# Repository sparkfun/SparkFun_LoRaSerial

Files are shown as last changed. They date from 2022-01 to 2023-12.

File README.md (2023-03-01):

SparkFun LoRaSerial
========================================

SparkFun LoRaSerial (https://www.sparkfun.com/products/19311)

[*SparkFun LoRaSerial Kit - 915MHz (WRL-19311)*](https://www.sparkfun.com/products/19311)

Head to the [LoRaSerial Product Manual](http://docs.sparkfun.com/SparkFun_LoRaSerial/) for technical documentation.

LoRaSerial is a pair of serial radio modems that simply passes serial back and forth. Do you have a system that needs to report data every few seconds? Is it located beyond WiFi or Bluetooth range? Do you need 9 mile/15 kilometer range? LoRaSerial transmits data over LoRa giving it incredible range compared to other methods. We’ve regularly transmitted over 9 miles/15km line-of-sight using two LoRaSerial radios, right out of the box.

LoRaSerial utilizes a 1 watt 915MHz transceiver and an open source protocol to and transmit AES encrypted data at 4800bps or approximately 480 bytes per second. Video streaming, this is not. LoRaSerial is very good at getting whatever data you need from point A to point B, encrypted, without configuration. The radios automatically frequency hop (FHSS) between channels to avoid collisions. The ‘airspeed’ or data rate is configurable up to approximately 2,000 bytes per second for shorter range, or for *extremely* long range transmissions, as low as 400 bytes per second.

LoRaSerial radios support simple point to point and point as well as multipoint broadcasts. Multipoint broadcasting makes it ideal for GNSS RTK and many other scenarios where one device needs to produce data and many devices need to consume that data.

The LoRaSerial firmware supports an innovative and simple to use ‘training’ method. Pressing the train button on both radios will generate a new random network ID and AES encryption key and share them between radios. This makes pairing radios in the field as simple as a button press. WiFi WPS this is not. Bring the radios near each other and the LoRaSerial training method is simple and secure.

Currently, SparkFun is offering radios utilizing 915MHz modems that are allowed in most parts of the world. Please check your local restrictions. The radios are fully configurable to restrict frequencies, channels, dwell time, power output, and a variety of other settings to make the radios compatible with your local regulations.

Repository Contents
-------------------

* **/Binaries** - Compiled firmware, ready to load
* **/Documents** - Datasheets and additional product information
* **/Firmware** - Main Arduino firmware
* **/Hardware** - Eagle PCB files

Documentation
--------------

* **[LoRaSerial Product Manual](http://docs.sparkfun.com/SparkFun_LoRaSerial/)** - Configuration guide for the SparkFun LoRaSerial.

License Information
-------------------

This product is _**open source**_! 

Please review the LICENSE.md file for license information. 

If you have any questions or concerns on licensing, please contact technical support on our [SparkFun forums](https://forum.sparkfun.com/viewforum.php?f=152).

Distributed as-is; no warranty is given.

- Your friends at SparkFun.

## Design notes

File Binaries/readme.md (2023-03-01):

Programming SAMD21 in Circuit
===========================================================

LoRaSerial uses a SAMD21. This folder contains the various production and release binaries for the device. Please see [Updating LoRaSerial Firmware](https://docs.sparkfun.com/SparkFun_LoRaSerial/firmware_update/) for instructions on how to update the firmware on the device.

This folder also contains binaries combined with a UF2 bootloader. These binaries are loaded during production to allow both the bootloader and firmware to be loaded in one step. These files, along with atprogram.exe are used with a J-Link programmer to load the combined binary onto a target device.

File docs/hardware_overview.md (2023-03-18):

# Hardware Overview

The LoRaSerial is a SAMD21 based assembly with an SX1276 LoRa radio with innovative firmware to make things as simple as possible.

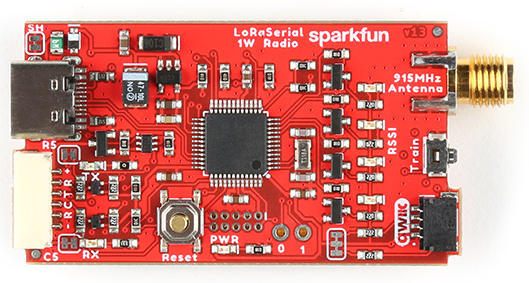
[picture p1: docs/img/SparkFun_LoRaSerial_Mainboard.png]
SAMD21 based serial radio


*SAMD21 based serial radio*

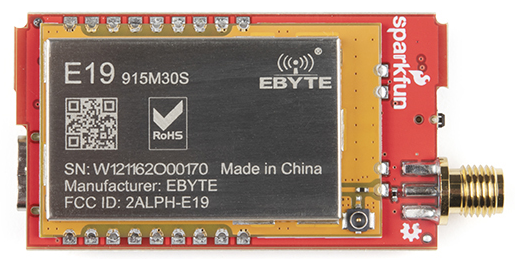
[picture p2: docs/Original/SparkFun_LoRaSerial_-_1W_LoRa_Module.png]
LoRa module


*1-watt module containing the SX1276 and a power amplifier*

The LoRaSerial uses a 1W LoRa radio based on the SX1276 radio along with a SAMD21 utilizing the UF2 bootloader. Any serial received at USB or serial port will be queued up, encrypted, and sent out over the radio. Any received packets are checked for CRC and Network ID, decrypted, then printed on both USB and serial interfaces.

Note: By default, there is a 50ms timeout in which the radio will wait for additional characters to be received until a partial frame is sent.

### USB C

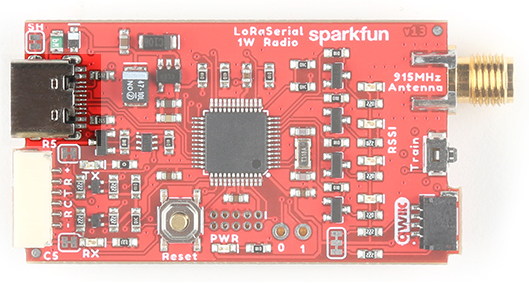
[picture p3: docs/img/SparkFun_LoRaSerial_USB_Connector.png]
USB C connector for power and serial


*USB C connector for power and serial*

The USB C connector provides power and serial communication to the unit. LoRaSerial will automatically show up on a computer or SBC (single board computer) as a serial COM port at a default of 57600bps. Currently, only 8-N-1 serial communication is supported but we are open to additional features as users' needs arise.

### 6-Pin JST

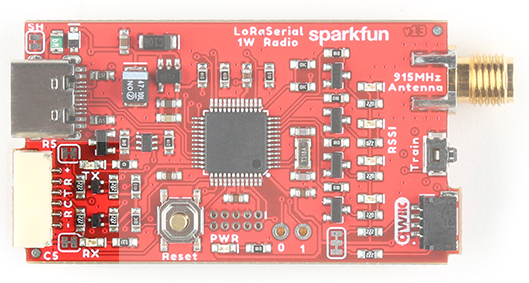
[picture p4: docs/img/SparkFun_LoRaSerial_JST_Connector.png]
6-pin locking JST connector for power and serial


*6-pin locking JST connector for power and  serial*

LoRaSerial features a ‘locking’ type 6-pin JST connector. The connector on LoRaSerial is X and mates with a connector JST-GHR-06V. Each LoRaSerial radio comes with a cable to connect from the JST connector to breadboard-friendly pins. If you need additional cables they are available [here](https://www.sparkfun.com/products/18079) (Note: the wire color may be different between cables). 

The pinout is as follows:

* **PWR** - 3.3-5V
* **RX** - Receive (Input into LoRaSerial)
* **TX** - Transmit (Output from LoRaSerial)
* **CTS** - Clear To Send (Input into LoRaSerial)
* **RTS** - Ready To Send (Output from LoRaSerial)
* **GND** - Ground

**PWR** (3.3-5V) - LoRaSerial requires 3.3 to 5V to operate. We recommend 5V for maximum transmission range but we’ve found operating off of a LiPo at 3.7 to 4.2V works great.

**RX** (Receive) - Connect this pin to the TX pin of your system. This pin is 3.3-5V tolerant and has an internal pull-up.

**TX** (Transmit) - Connect this pin to the RX pin of your system. This pin uses 3.3V logic.

**CTS** (Clear To Send) - (Optional) Connect this pin to a GPIO of your system. This pin is 3.3-5V tolerant and has an internal pull-up. When this pin is low LoRaSerial will continue to send data. If the host system pulls this pin high, the radio will stop sending data.

**RTS** (Ready To Send) - (Optional) Connect this pin to a GPIO of your system. This pin uses 3.3V logic. If the radio’s buffer (size currently is 4096 bytes) becomes full the system will drive RTS high indicating that it should not be passed more data. If more serial data is received, the buffer will be overwritten, oldest data first.

**GND** (Ground) - Connect this pin to the ground of your system.

#### Flow Control

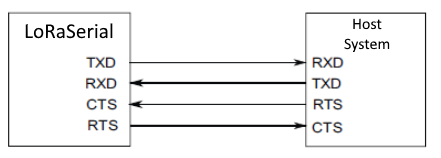
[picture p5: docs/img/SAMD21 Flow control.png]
Flow control on the SAMD21


If flow control is enabled, LoRaSerial will send data when its CTS pin is driven low (the host system is telling the radio to transmit). If flow control is enabled, LoRaSerial will drive its RTS low if its serial buffer is full (the radio is telling the host system to hold its horses). CTS and RTS pins are only exposed on the UART connector but if flow control is enabled, the UART flow control pins will apply to both USB and serial data streams. Internal pull-ups are used so if flow control is enabled, RTS and CTS must not be left floating. By default, flow control is turned off.

Hardware flow control applies to both the UART connection and the USB connector but in slightly different ways. 

The USB connection uses a concept called backpressure. It is not affected by the [FlowControl setting](http://docs.sparkfun.com/SparkFun_LoRaSerial/at_commands/#serial-commands) and cannot be disabled. If LoRaSerial is not able to read the incoming data fast enough, the USB driver will indicate to the host’s operating system that the data has not been consumed. Depending on the application, data will either be paused or lost. 

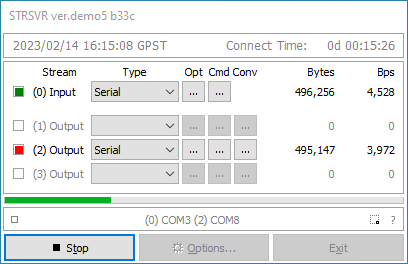
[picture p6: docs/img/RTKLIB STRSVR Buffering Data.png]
STRSVR Buffering Serial Data


This is most obvious in applications such as STRSVR (from [RTKLIB](https://rtklib.com/)). If STRSVR sends more data to the LoRaSerial than it can consume, STRSVR will begin to buffer the data until it can be sent. This is problematic for time-sensitive data, such as RTCM, where data, being delivered successfully but delayed but multiple seconds, can cause problems with RTK. If RTCM data is multiple seconds old, an RTK Fix will go to RTK Float, then fail because current RTCM data is not being delivered to the far end of the radio link. The easiest way to fix the problem is to increase the AirSpeed of the link.

### RSSI LEDs

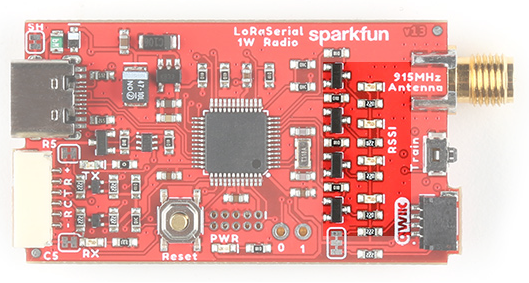
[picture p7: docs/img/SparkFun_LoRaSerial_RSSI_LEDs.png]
4 LEDs indicating signal strength


*4 LEDs indicating signal strength*

Four LEDs indicate in real-time the received signal strength or RSSI. These LEDs are meant to show a qualitative level of receive strength. Don’t worry if you’ve got three LEDs rather than four. LoRa technology is capable of transmitting a long range in harsh RF conditions. As long as you’ve got one LED, you will be able to send and receive data.

### RPSMA Connector

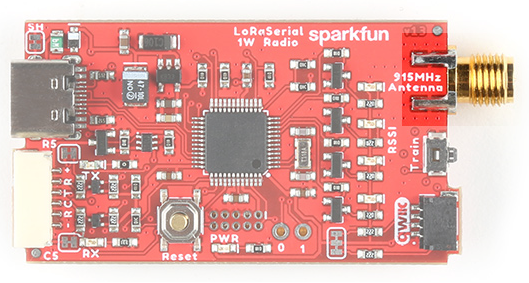
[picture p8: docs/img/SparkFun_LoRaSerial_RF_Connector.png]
Reverse polarized SMA antenna connector


*Reverse polarized SMA antenna connector*

Attach a 915MHz RPSMA antenna to this port. Not sure which is SMA and which is RPSMA? Check out this [RF Connector Guide](https://www.sparkfun.com/pages/RF_Conn_Guide). The LoRaSerial is also compatible with any large 915MHz antennas including [fiberglass antennas](https://www.sparkfun.com/products/15597). We recommend a good thick RG58 RPSMA extension from the radio to your antenna to minimize loss. Remember, we are transmitting at 1W so keep your cables and connectors to a minimum.

Note: Be careful of antennas that have a gain higher than 6 dBi as this may violate the [maximum effective isotropic radiated power](https://afar.net/tutorials/fcc-rules/) (EIRP) for your area/country.

### Qwiic Connector

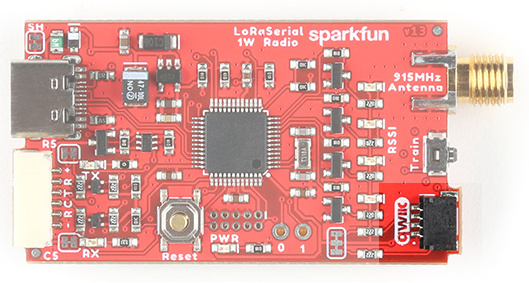
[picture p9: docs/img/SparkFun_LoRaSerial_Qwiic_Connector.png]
Qwiic connector for I2C communication


*Qwiic connector for I2C communication*

The Qwiic connector and I2C accessibility are not yet implemented.

### Train Button

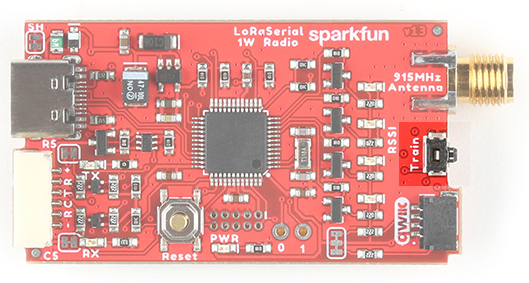
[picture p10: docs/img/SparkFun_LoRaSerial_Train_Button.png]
Button to enter train mode


*Button to enter train mode*

LoRa Serial uses a unique and very easy-to-use train feature. Each radio has a default Network ID and AES key programmed into it. Changing these keys is as easy as pressing a button! 

Using a ballpoint pen or other small pointed device, press and hold the Train button for 2 seconds, until you see the RSSI LEDs begin to blink. You can release the button. If the LEDs begin to cylon (bounce back and forth) the device has entered training ‘wait’ mode where it waits for another device to ping it.

On the second radio, press and hold the Train button for 2 seconds, until you see the RSSI LEDs begin to blink. Release the button. The RSSI LEDs on both units will blink in unison indicating that the units are now trained to each other.

For security reasons, the radios are both set to the lowest transmission power to minimize any eavesdropper from monitoring the transaction. While the ‘new’ keys are themselves encrypted, they are encrypted using a published AES key so one could theoretically back out the new AES keys if they are within ~30ft of the devices when the radios are being trained. If you’re paranoid, train the radios with the antennas off, within a few inches of each other. If total security is a concern, or if the radios cannot be physically brought near one another, the AES keys and/or the network IDs can be set via software commands.

### Internal Reset Button

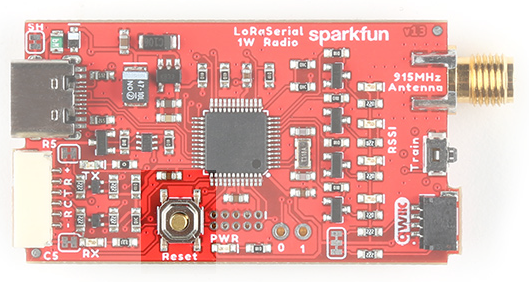
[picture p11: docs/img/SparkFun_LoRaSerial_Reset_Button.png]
SAMD21 reset button


*SAMD21 reset button*

The firmware on the LoRaSerial can be upgraded from a computer without ever having to open the unit. In the rare case that the SAMD21 needs to be forced into bootloader mode the reset button should be quickly double-tapped. The unit will then enter bootloader mode and wait for new firmware or for a reset event (button is pressed or power is cycled).

Please see [Updating LoRaSerial Firmware](http://docs.sparkfun.com/SparkFun_LoRaSerial/firmware_update/) for more information.

### GPIO

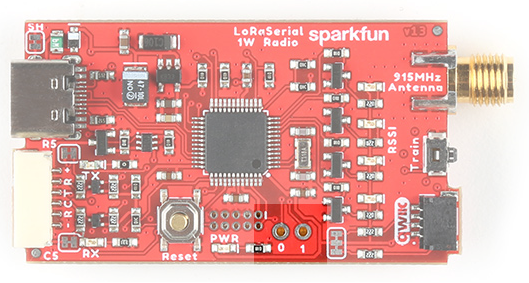
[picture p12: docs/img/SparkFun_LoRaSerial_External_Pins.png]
GPIOs on SAMD21


*GPIOs on SAMD21*

Two GPIOs capable of ADC are broken out for potential future use.

### U.FL Connector

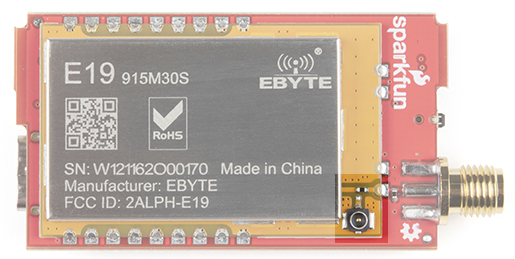
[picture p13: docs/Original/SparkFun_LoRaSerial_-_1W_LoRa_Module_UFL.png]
Zero ohm jumper resistor and U.FL connector


*Zero ohm jumper resistor and U.FL connector*

For advanced users, the 915/868MHz modules feature a U.FL connector. This can be helpful if you need to embed the radio in an enclosure and need an external bulkhead RP-SMA connector. To use the U.FL connection, desolder the 0402 0Ω jumper and move it to the U.FL's RF path.

### Power Selection

LoRaSerial uses an onboard 'ideal' MOSFET to select the high voltage source between the USB connector and the VCC/GND of the UART connector. This allows dual power supplies to be applied without fear of back-feeding a higher voltage onto a lower voltage system.

## Enclosure

The enclosure is industrial 3D SLA printed with an effective IPX rating of IP52 (dust and waterdrop protected).

The enclosure is secured with two screws on either side of the unit. The top cover can be removed to expose the inner assembly.

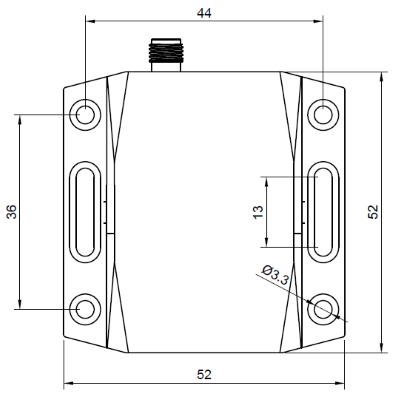
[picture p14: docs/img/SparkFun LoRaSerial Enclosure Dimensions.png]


*[LoRaSerial Dimensional Drawing](img/SparkFun_LoRaSerial_Enclosure_Dimensions.pdf)*

The enclosure includes mounting holes for wall or rack mounting.

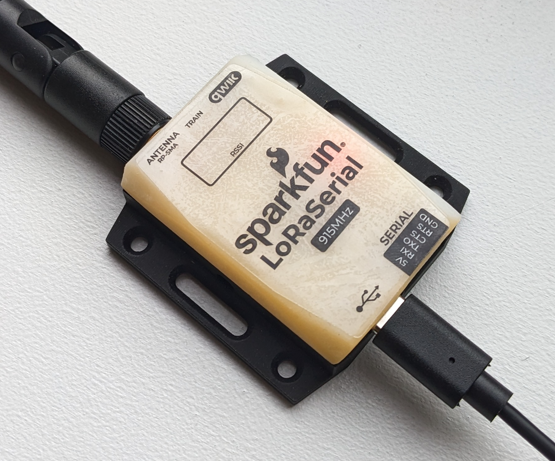
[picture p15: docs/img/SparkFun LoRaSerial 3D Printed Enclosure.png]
LoRaSerial Enclosure UV Exposed


**Note:** Leaving a LoRaSerial unit exposed to daylight outdoors or near a window will cause the cover to darken over a period of months. This will not affect the performance of the radio or the enclosure.

## Power Usage

The SX1276-based radio module is rated for 1 watt. The radio can be adjusted from 14dBm up to 30dBm (default). 

**Note:** The **AT-TxPower** command ranges from 14 to 30 in dBm. The radio uses an internal lookup table to map the correct power output (30dBm by default) to the associated power level for the power amplifier (20 in this case).

The average standby current is approximately **60mA** when TxPower of 30 is selected. The average current varies based on the selected output power because the units will periodically transmit *Find Partner* packets when the link is down and *Heartbeat* packets when the link is up, even if there is no data waiting to be transmitted. 

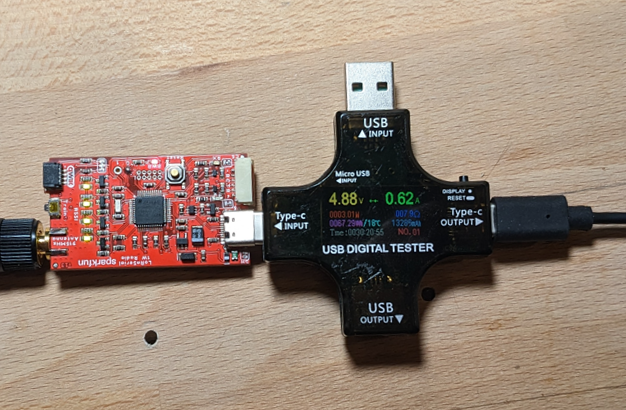
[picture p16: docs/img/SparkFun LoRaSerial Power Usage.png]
A 1W radio using 2.5W


During broadcast, the radio can use much more than 1W. Use a good 5V supply capable of outputting at least 1A at 5V. A USB 3.0 port is good. A USB 2.0 port will considerably limit the capabilities of the radio.

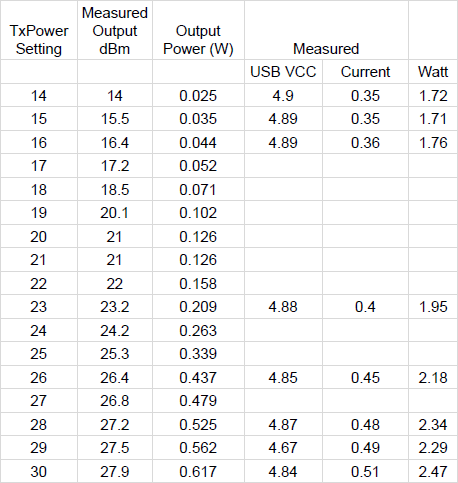
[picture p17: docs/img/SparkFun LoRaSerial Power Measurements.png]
Power output vs Power input


The above table shows power usage during 100% broadcast envelope usage. The actual current usage will be proportionally lower depending on the amount of data transmitted. For example, if only half of the airspeed is used (240 bytes out of a max of 480 at airspeed 4800) then the transmitter will only be on for 50% of the time at the stated power.

The power meter and hardware setup limited the ability to get to the full 30dBm output. The above measurements should be used as a rule-of-thumb for power considerations.

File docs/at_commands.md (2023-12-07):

# AT Commands

LoRaSerial radios are very flexible. By default, the radio is looking for serial communication at 57600bps. Open the terminal of your choice and enter +++ and wait for an OK. The radio is now ready for an AT command.

A PDF of *all* AT commands is available [here](img/LoRaSerial%20AT%20Commands%20v2.0.pdf).

Below is a brief list of commands:

| AT Command | Command Description |
|---|---|
|+++ | Enter command mode |
|AT | Reports OK |
|AT? | Display help text |
|ATB | Break the link |
|ATD | Display the debug settings |
|ATF | Restore factory settings |
|ATG | Generate new netID and encryption key |
|ATI | Display the radio version |
|ATI? | Display the information commands |
|ATIn | Display system information |
|ATO | Exit command mode |
|ATP | Display probe trigger settings |
|ATR | Display radio settings |
|ATS | Display the serial settings |
|ATT | Enter training mode |
|ATW | Save current settings to NVM |
|ATZ | Reboot the radio |
|AT-Param=xxx| Set parameter's value to xxx by name (Param)|
|AT-Param? | Print parameter's current value by name (Param)|
|AT-? | Display the setting values |

*Table of AT Commands*

The commands are best discussed in groups:

* [Radio Commands](http://docs.sparkfun.com/SparkFun_LoRaSerial/at_commands/#radio-commands)
* [Serial Commands](http://docs.sparkfun.com/SparkFun_LoRaSerial/at_commands/#serial-commands)
* [Info Commands](http://docs.sparkfun.com/SparkFun_LoRaSerial/at_commands/#info-commands)
* Debug Commands

A parameter is set using the **AT-** prefix, followed by the name of the command with an equals sign and the value to set. For example, sending **AT-Echo=1**** will enable serial echo. This setting can be stored in NVM (non-volatile memory) by sending the **ATW** command. To query a setting, send the AT command without a value and the device will respond with the current value. For example, sending **AT-FrequencyMax** will generate the response **928.000** followed by **OK**.

## Radio Commands

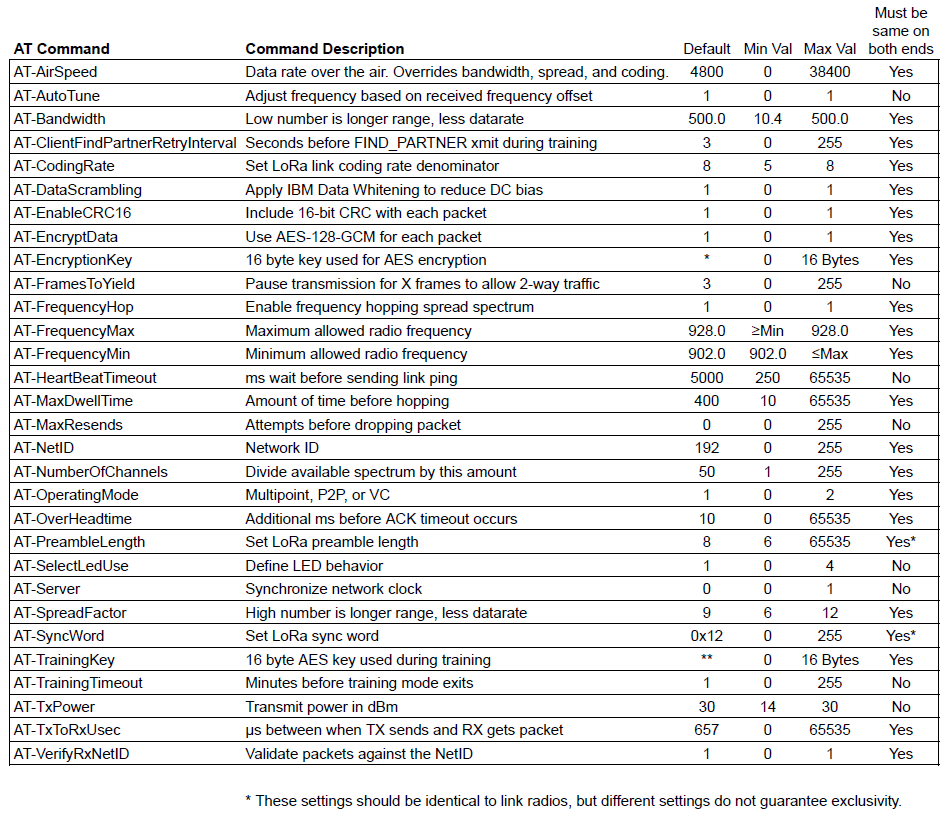
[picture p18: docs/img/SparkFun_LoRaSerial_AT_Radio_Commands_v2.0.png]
Table of common radio parameters


*Table of common radio link parameters*

A table of the subset of the common Radio Link Parameters is available [here](img/LoRaSerial%20AT%20Commands%20v2.0.pdf) in PDF format.

**Note:** Some settings must be identical on both radios for the link to be possible. These settings are used to generate the unique hop table. If settings are not compatible between radios, they will not be able to communicate.

| AT Command | Command Description |
|---|---|
| AT-AirSpeed | Data rate over the air. Overrides bandwidth, spread, and coding.
| AT-AutoTune | Adjust frequency based on received frequency offset
| AT-Bandwidth | Low number is longer range, less data rate
| AT-ClientFindPartnerRetryInterval | Seconds before FIND_PARTNER xmit during training
| AT-CodingRate | Set LoRa link coding rate denominator
| AT-DataScrambling | Apply IBM Data Whitening to reduce DC bias
| AT-EnableCRC16 | Include 16-bit CRC with each packet
| AT-EncryptData | Use AES-128-GCM for each packet
| AT-EncryptionKey | 16 byte key used for AES encryption
| AT-FramesToYield | Pause transmission for X frames to allow 2-way traffic
| AT-FrequencyHop | Enable frequency hopping spread spectrum
| AT-FrequencyMax | Maximum allowed radio frequency
| AT-FrequencyMin | Minimum allowed radio frequency
| AT-HeartBeatTimeout | ms wait before sending link ping
| AT-MaxDwellTime | Amount of time before hopping
| AT-MaxResends | Attempts before dropping packet
| AT-NetID | Network ID
| AT-NumberOfChannels | Divide available spectrum by this amount
| AT-OperatingMode | Multipoint or P2P
| AT-OverHeadtime | Additional ms before ACK timeout occurs
| AT-PreambleLength | Set LoRa preamble length
| AT-SelectLedUse | Define LED behavior
| AT-Server | Synchronize network clock
| AT-SpreadFactor | High number is longer range, less data rate
| AT-SyncWord | Set LoRa sync word
| AT-TrainingKey | 16 byte AES key used during training
| AT-TrainingTimeout | Minutes before training mode exits
| AT-TxPower | Transmit power in dBm
| AT-TxToRxUsec | μs between when TX sends and RX gets packet
| AT-VerifyRxNetID | Validate packets against the NetID

*Table of Radio Commands*

* **AirSpeed** - This is the effective rate in bits-per-second at which data is sent over the air. In general, the lower the airspeed, the greater the transmission distance. LoRaSerial uses buffers to receive and send serial over USB or UART at the *SerialSpeed* and begins sending that data in chunks over the air at the AirSpeed. The *AirSpeed* setting does not have to match the SerialSpeed. It is recommended to limit the total incoming data to match the airspeed. For example, regularly sending a group of 300 bytes with an air speed of 4800 bps (480 bytes per second) will allow the radio sufficient bandwidth. Sending 1,000 bytes per second with an air speed of 4800 bps (480 bytes per second) will within a few seconds overwhelm the link leading to buffer overflow and data loss. The default is 4800bps. Allowed values are 400, 1200, 2400, 4800, 9600, and 19200 bits per second. Changing the AirSpeed value overwrites the following 5 parameters:

  + HeartbeatTimeout
  + RadioBandwidth
  + RadioCodingRate
  + RadioSpreadFactor
  + TxToRxUsec

  After AirSpeed is set, it is possible to modify any of the above five parameters. Note that AirSpeed is just an easy way to set the five parameters to known values. AirSpeed is not a parameter that is transmitted during training, merely a convenient way to set the five parameters in one step.

  Note: The AirSpeed setting can be queried, but it is not back calculated. Said differently, after a system reset, the AirSpeed setting will report 0. This is because calculating the equivalent airspeed based on the user's settings results in non-sensical values that do not map cleanly with the defined AirSpeed options. Currently, the way to verify the device is set to the correct airspeed is to check the 5 parameters shown above against the settings shown on the [AirSpeed calculation page](https://github.com/sparkfun/SparkFun_LoRaSerial/tree/main/Documents).

* **AutoTune** - Enabling autotune will cause the radio to tune the receiver frequency based on the calculated frequency error. This is used for testing and is not recommended for general use.

* **Bandwidth** - The bandwidth used around a given frequency during LoRa transmissions. This setting is in kHz. This setting is overwritten if the AirSpeed setting is changed. It is recommended to use the airspeed setting unless you are very aware of the consequences. In general, a lower bandwidth number provides a longer range, but a lower overall data rate. Allowed bandwidths: 10.4, 15.6, 20.8, 31.25, 41.7, 62.5, 125.0, 250.0, and 500.0kHz.

* **ClientFindPartnerRetryInterval** - In training mode, the client will transmit a special packet and then await a response from a server. This is the number of seconds between re-transmits of the FIND_PARTNER packet.

* **CodingRate** - The coding rate used during LoRa transmissions. It is recommended to use the airspeed setting unless you are very aware of the consequences. This setting is overwritten if the AirSpeed setting is changed. In general, a higher spread factor provides a longer range, but a lower overall data rate. Allowed spread factors: 6 to 12 (inclusive).

* **DataScrambling** - Enabling data scrambling will send all packets through an *[IBM data whitening](https://www.nxp.com/docs/en/application-note/AN5070.pdf)* process. This removes long sets of 1s or 0s from the packet to reduce DC bias during transmission. This is generally not needed and is not recommended when AES encryption is enabled. By default, scrambling is turned off.

* **EnableCRC16** - When CRC is enabled, any packet that does not have a valid CRC will be ignored. The SX1276 IC has CRC at the radio interface, but because of RF noise, the number of corrupt packets is noticeable. This extra layer ensures packet delivery. Enabling CRC will add two bytes to each frame.

* **EncryptData** - By default, all packets are encrypted using 128-bit AES GCM. Disabling this will not achieve a greater range or bandwidth. Disabling encryption will allow all packets to be seen in clear text via an SDR or other monitoring device.

* **EncryptionKey** - This is the 16-byte key used for AES encryption. While SparkFun provides a default value, it is strongly recommended to change this value for your own networks. This can be changed via command or via the P2P training method. Please see [P2P Training](http://docs.sparkfun.com/SparkFun_LoRaSerial/training/#point-to-point-training-as-server) for more information.

* **FramesToYield** - During large data flows the receiving radio can request a yield within the ACK packet. When the transmitter receives a yield request, data flow is paused for FramesToYield * Frame Transmit Time. This gives the receiver a chance to transmit its own data allowing data to flow in both directions on the link.

* **FrequencyHop** - The LoRaSerial implements frequency hopping spread spectrum (FHSS) by default to meet FCC Part 15.247 compliance. Turning off frequency hopping is not recommended unless You Know What You’re Doing™.

* **FrequencyMin/FrequencyMax** - These are the lower and upper bounds for the allowed transmission frequencies in megahertz. By default, this is 902.0 to 928.0.

* **HeartbeatTimeout** - Heartbeats are transmitted on a regular basis by the server and in point-to-point mode by the clients. This parameter specifies the time in milliseconds during which a HEARTBEAT frame should be transmitted. If a HEARTBEAT frame is not received within three (3) times this interval then the point-to-point link is broken. The default heartbeatTimeout is 5000 milliseconds (5 seconds).

* **MaxDwellTime** - The number of milliseconds of transmission allowed on a given frequency before hopping intra-packet. The default is 400ms to be compliant with FCC Part 15.247. This means the radio will change its frequency to the next channel in the hop table during the packet transmission. Note this is the maximum dwell time; depending on the air speed setting the radio may have a hopping period that is shorter than the dwell time.

* **MaxResends** - Number of retransmission attempts when an ACK is not received from the destination radio. The valid range is 0 to 255. The default of zero represents infinite and retries will continue as long as the two radios are receiving HEARTBEAT frames from each other. The transmission will fail only when the link breaks due to not receiving HEARTBEAT frames.

* **NetID** - When VerifyRxNetID is enabled, each received packet is checked against the radio's network ID. If a packet is received with a non-matching NetID it is discarded. Changing the NetID is a handy way to make sure your radios do not interfere with other radios in the same vicinity.

* **NumberOfChannels** - The available spectrum (default is 902MHz to 928MHz) is divided by this number of channels to create the channel spacing and allowed frequency list (aka the ‘hop table’). The default is 50 channels to meet FCC Part 15.247 compliance and may be changed to meet local regulations.

* **OperatingMode** - The radios can operate in one of two different modes: Multipoint and Point-To-Point. See [Operating Modes](http://docs.sparkfun.com/SparkFun_LoRaSerial/operating_modes/) for more information.

  + MODE_MULTIPOINT (0) - A single server with multiple clients. All radios may broadcast to all other radios, but data is not guaranteed to be received by the other radios. This mode is great when real-time transmission is necessary and the application can tolerate some loss of data.

  + MODE_POINT_TO_POINT (1, default) - Communications between two LoRaSerial radios with guaranteed delivery of frames or the link breaks.

* **OverheadTime** - The number of milliseconds to add to ACK and datagram times before ACK timeout occurs. The default is 10 milliseconds.

* **PreambleLength** - The number of sync words to send at the start of a packet. Note that two LoRa radios with the same settings but different preamble lengths have been shown to intermittently receive packets from each other. Therefore, using a unique preamble length does *not* guarantee exclusivity. Allowed values: 6 to 65535.

* **SelectLedUse** - Select how to display information on the LEDs. See [LED States](http://docs.sparkfun.com/SparkFun_LoRaSerial/led_states/) for more information.

* **Server** - Enable (1) or disable (0) the server mode for training and for multipoint operation. The default is client mode (0). The radio designated as Server synchronizes the network. A server is required for Multipoint and Training modes.

* **SpreadFactor** - The spread factor used during LoRa transmissions. It is recommended to use the airspeed setting unless you are very aware of the consequences. This setting is overwritten if the AirSpeed setting is changed. In general, a higher spread factor provides a longer range, but a lower overall data rate. Allowed spread factors: 6 to 12 (inclusive).

* **SyncWord** - The byte used to synchronize LoRa transmissions. In general, this is set to 0x12 for non-LoRaWAN networks. Note that two LoRa radios with the same settings but different sync words have been shown to intermittently receive packets from each other. Therefore, using a unique synch word does *not* guarantee exclusivity. Allowed values: 0 to 255.

* **TxPower** - The LoRaSerial uses a high-power 1W transceiver. By default, all transmissions are sent at the highest possible power of 30dBm which is compliant with FCC Part 15.247 when used with an antenna that has a gain of 6dBi or less. If your local regulations require lower transmission power this setting can be lowered. Allowed values are 30 down to 14dBm. Note: The chosen setting is the actual measured transmit power at the SMA connector. An internal lookup table sets the radio settings accordingly.

* **TxToRxUsec** - This is the number of microseconds between when the transmitter completes a transmission, and when the receiver completes the reception of that packet. For lower airspeeds, this value increases and generally tracks to 1 symbol time. It is recommended to use the airspeed setting unless you are very aware of the consequences. This setting is overwritten if the AirSpeed setting is changed.

* **VerifyRxNetID** - Enable (1) or disable (0) the verification of the netID value during reception. The default is enabled (1).

## Serial Commands

| AT Command | Command Description |
|---|---|
| AT-CopySerial | Copy the serial parameters to the training client
| AT-Echo | Print locally inputted serial
| AT-FlowControl | Enable the use of CTS/RTS flow control signals
| AT-InvertCts | Invert the input of CTS
| AT-InvertRts | Invert the output of RTS
| AT-SerialDelay | ms of no data before fractional buffer is sent
| AT-SerialSpeed | Hardware UART baud rate
| AT-UsbSerialWait | Wait for USB enumeration before radio start

* **CopySerial** - False by default. Set to true to transmit Serial settings during training from Server to Clients.

* **Echo** - By default, the radio will not echo the incoming serial. This is helpful at times if a user is typing data directly into a terminal. During AT configuration echo is turned on regardless of this setting.

Flow control on the SAMD21

* **FlowControl** - If flow control is enabled, LoRaSerial will send data when its CTS pin is driven low (the host system is telling the radio to transmit). If flow control is enabled, LoRaSerial will drive its RTS low if its serial buffer is full (the radio is telling the host system to hold its horses). CTS and RTS pins are only exposed on the UART connector but if flow control is enabled, the UART flow control pins will apply to both USB and serial data streams. Internal pull-ups are used so if flow control is enabled, RTS and CTS must not be left floating. By default, flow control is turned off.

* **InvertCts** - By default, InvertCts is false and CTS is high when data is allowed to flow. Enable InvertCts to do the opposite.

* **InvertRts** - By default, InvertRts is false and RTS is high when data is allowed to flow. Enable InvertRts to do the opposite.

* **SerialDelay** - The number of milliseconds of timeout before a partial packet is sent. For example, if a partial frame of 12 bytes is received, the radio will wait this amount for more bytes before initiating a transmission. The default is 50ms. Allowed values: 10 to 2000ms.

* **SerialSpeed** - Controls the baud rate in bits-per-second used over the UART connector. Data sent over USB will be sent/received regardless of this setting. The default is 57600bps. Allowed values are 2400, 4800, 9600, 14400, 19200, 38400, 57600, and 115200bps.

* **UsbSerialWait** - If enabled, the radio will wait for the USB port to be enumerated and open before beginning operation. The default is false.

## Info Commands

| AT Command | Command Description |
|---|---|
| ATI0 | Show user settable parameters
| ATI1 | Show board variant
| ATI2 | Show firmware version
| ATI3 | Display RSSI value
| ATI4 | Get random byte from RSSI
| ATI5 | Show max possible bytes per second
| ATI6 | Display current radio state
| ATI7 | Show current FHSS channel
| ATI8 | Display system unique ID
| ATI9 | Display the maximum datagram size
| ATI10 | Display radio metrics
| ATI13 | Display the SX1276 registers
| ATI14 | Dump the radioTxBuffer

* **ATI0** - List all available AT commands.

* **ATI1** - Shows the board variant. For example "SparkFun LoRaSerial SAMD21 1W 915MHz".

* **ATI2** - Shows the LoRaSerial firmware version. For example "2.0".

* **ATI3** - Shows the last RSSI during a successful reception. For example "-76".

* **ATI4** - Queries the radio for a random byte, 0 to 255, based on RF noise. For example "42".

* **ATI5** - Based on settings, returns the ideal number of bytes capable of being transmitted over the link. This number assumes no retransmits and should be used only as a guide to set expectations of the host system.

* **ATI6** - Displays the current radio state. For example: "State: P2P: Receiving Standby LinkUptime:     2:45:08".

* **ATI7** - Displays the current channel number. For example: "29".

* **ATI8** - Displays the unique 32-character, 16-byte, 128-bit value marked into the SAMD21 microcontroller. For example: "5BCEDAE13630595020312E32102317FF".

* **ATI9** - Displays the maximum number of bytes that can be transmitted. Different radio settings will use fewer or a greater number of bytes for overhead. For example: "249".

* **ATI10** - Displays a large number of metrics related to the radio link including datagrams sent, link uptime, ACK counts, buffer states, etc.

* **ATI13** - Displays the contents of all the registers in the SX1276 LoRa transceiver.

* **ATI14** - Displays the contents of the current transmit buffer.

## Remote Training

Currently, only one remote command is supported - **RTT**. Issuing this command to the local radio when the link is up will cause the remote radio to drop from the link and enter training mode. The remote radio will wait in this mode until training is completed, a local **ATZ** command is entered into the remote device, or the Train button is pressed on the remote device.

This command is generally used to remotely configure a radio. First, the **RTT** command is issued, the local radio is configured (including enabling Server), then the **ATT** is issued to push the local radio into training. Because the local radio is the server, its settings are set to the remote radio. The remote radio will reset and start with these newly issued settings. The local radio needs to reset with an **ATZ** command and the link should be re-established with new settings. Below is a command script to achieve this remote configuration. We assume the radios are currently linked at the start of the script.

*Note:* RTT is only supported in P2P mode.

    +++
    RTT
    AT-Server=1
    AT-AirSpeed=9600
    ATW
    ATT
    (Wait for the 'Client XYZ Trained' message)
    ATZ

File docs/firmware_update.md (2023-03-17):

# Updating LoRaSerial Firmware

From time to time SparkFun will release new firmware for the LoRaSerial product line to add and improve functionality. Firmware can be upgraded using the SparkFun BOSSA GUI.

## BOSSA GUI

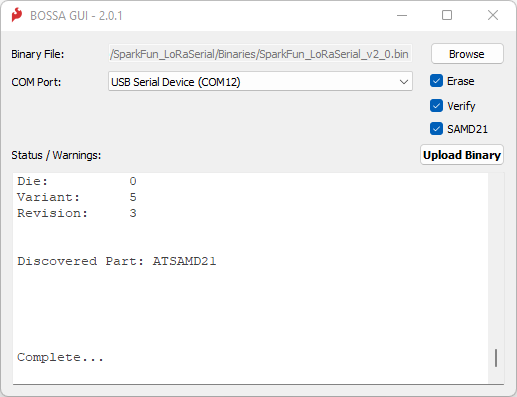
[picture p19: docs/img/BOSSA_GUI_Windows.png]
SparkFun BOSSA GUI


The LoRaSerial utilizes a SAMD21 microcontroller. To update the firmware, obtain the SparkFun BOSSA GUI from [this repo](https://github.com/sparkfun/SparkFun_BOSSA_GUI). The GUI is PyQt5 based on the Python SAM-BA Loader script that can be run from the command line. Alternatively, Windows, macOS and Linux-compatible executables are available in the [release section](https://github.com/sparkfun/SparkFun_BOSSA_GUI/releases). There is a Python package too, which works nicely on Raspberry Pi.

Next, get the latest LoRaSerial Firmware binary located in [LoRaSerial Binaries folder](https://github.com/sparkfun/SparkFun_LoRaSerial/tree/main/Binaries). Note: There are two types of firmware files, one 'with_bootloader' and one without. You can ignore the 'with_bootloader' type file.

Run the GUI.

Click `Browse` and select the firmware file.

Click the `COM Port` dialog box and select the correct port. On macOS, you will see two ports - select the one called `tty.usbmodem`.

Click `Upload Binary` to start the upload.

### Bootloader Mode

The BOSSA GUI will attempt to put the SAMD21 into bootloader mode automatically to perform the update. But we have noticed that this fails occasionally on some machines - it is machine-dependent.

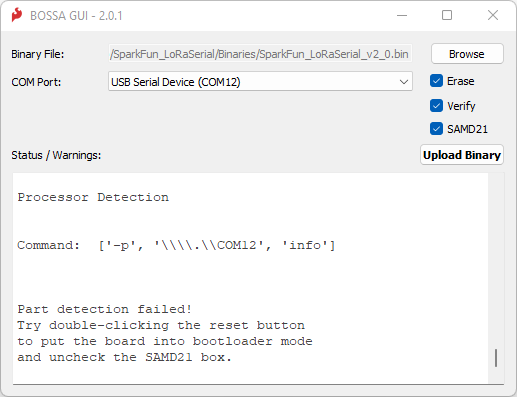
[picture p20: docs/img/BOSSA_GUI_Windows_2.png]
SparkFun BOSSA GUI


On those machines, you will need to put the SAMD21 into bootloader mode manually by opening the case and giving the reset button a double-tap.

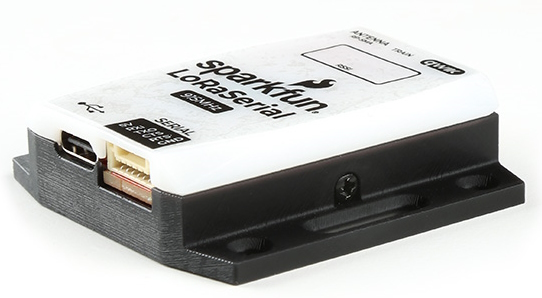
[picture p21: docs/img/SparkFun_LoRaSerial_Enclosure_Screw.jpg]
Enclosure screw


*Small Philips head screw*

Remove the two side screws and open the LoRaSerial enclosure to expose the reset button. 

SAMD21 reset button

*SAMD21 reset button*

Connect the LoRaSerial to the computer over USB. Double-tap the reset button to enter bootloader mode. You should see the blue LED slowly pulse on/off. Now open the BOSSA GUI, select the Binary file you downloaded, select the COM port of the LoRaSerial device. ***Uncheck the SAMD21 check-box*** and finally click `Upload Binary`.

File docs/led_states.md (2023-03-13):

# LED States

A variety of LEDs are visible on the LoRaSerial radio to give the user feedback about the state of the system.

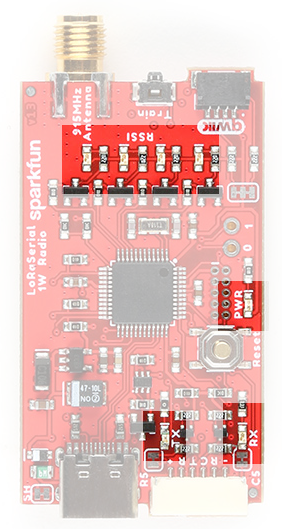
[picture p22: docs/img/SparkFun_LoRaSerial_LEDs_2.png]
LEDs on the LoRaSerial


*LEDs on the LoRaSerial*

The following diagram shows the various LEDs on the LoRaSerial device:

        Antenna         Qwiic
    +---------------------------+
    |                           |
    |     G4   G3   G2   G1     |
    |                           |
    |                           |
    |                       Red |
    |                           |
    |                           |
    |            Blue    Yellow |
    |                           |
    +---------------------------+
        USB            Serial

The red LED is the power indicator. G1 through G4 in the diagram above are all green LEDs.

## Radio Reset

When the device is first powered on or is reset, all LEDs will blink quickly three times indicating system reset.

## Training

During [training](https://docs.sparkfun.com/SparkFun_LoRaSerial/training/), the green RSSI LEDs will cylon back and forth. One green LED is lit at a time and the lit LED moves from side to side.

    G4    G3    G2    G1
                       X
                 X
           X
     X
           X
                 X
                       X
                 X
          ...

The yellow LED will blink when radio traffic is received and the blue LED will blink
when radio traffic is transmitted. Once training is complete, the radio will reset causing all LEDS to blink.

## LED Mode - LEDS_RSSI

This is the default mode. The RSSI LEDs will indicate the link's signal strength. The mode number is 4.

The LED behavior may be changed by using the **AT-SelectLedUse** command and setting the value to one of the mode numbers described in the sections below. As an example, the following commands cause the LEDs to display different information about the radio's behavior.

    +++
    AT-SelectLedUse=4
    ATO

* The RSSI LEDs indicate the signal strength of the last received packet:
    * -70 < RSSI: All green LEDs lit (strong)
    * -100 < RSSI <= -70: G3, G2, G1 LEDs lit, G4 off
    * -120 < RSSI <= -100: G2, G1 LEDs lit, G4 and G3 off
    * -150 < RSSI <= -120: G1 LED lit, all G4, G3 and G2 off (weak)
    * RSSI <= -150: <= All green LEDs off
* The blue TX LED indicates when serial data is received over the radio and sent to the host, either over USB or hardware serial.
* The yellow RX LED indicates when serial data is received from the host and sent over the radio.

## LED Mode - LEDS_MULTIPOINT

This mode gives the user insight into when the link is hopping and when a heartbeat is transmitted/received. The mode number is 0.

    +++
    AT-SelectLedUse=0
    ATO

* The G4 LED pulses when the radio transmits a frame.
* The G3 LED is pulse width modulated to indicate the last received RSSI level.
* The G2 LED turns on when the link is up (data can pass).
* The G1 LED pulses when the radio successfully receives a frame.
* The blue LED pulses on the server radio when the server transmits a HEARTBEAT frame. The blue LED pulses on the client radio when the client successfully receives a HEARTBEAT frame from the server.
* The yellow LED pulses each time a channel hop (frequency change) occurs.

## LED Mode - LEDS_RADIO_USE

This mode gives the user insight into when a bad or duplicate frame is detected. The mode number is 3.

    +++
    AT-SelectLedUse=3
    ATO

* The G4 LED pulses when the radio transmits a frame.
* The G3 LED is pulse width modulated to indicate the last received RSSI level.
* The G2 LED turns on when the link is up (data can pass).
* The G1 LED pulses when the radio successfully receives a frame.
* The blue LED will blink when the radio receives a bad frame.
* The yellow LED will blink when the radio receives a duplicate frame or receives a frame where the software CRC does not match.

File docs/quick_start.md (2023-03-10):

# Quick Start Guide

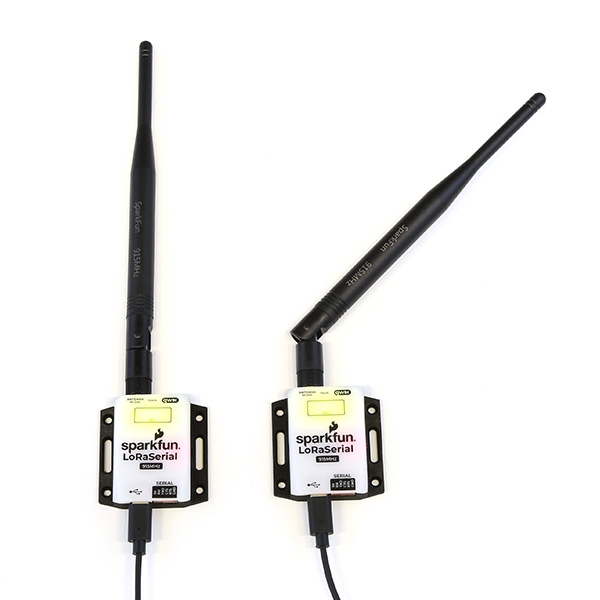
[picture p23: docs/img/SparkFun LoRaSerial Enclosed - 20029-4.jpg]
Two Linked LoRaSerials


LoRaSerial radios are very easy to use and ship ready to connect out of the box. Simply attach the antennas, plug two units into USB ports, open a terminal at each of the USB serial ports, and start passing data back and forth.

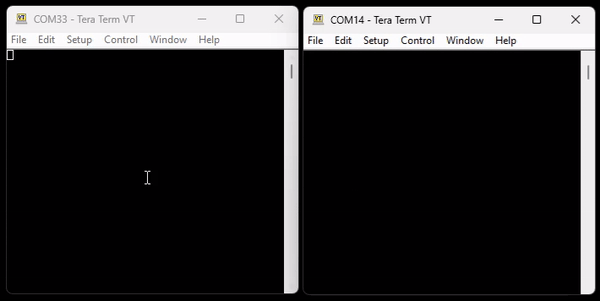
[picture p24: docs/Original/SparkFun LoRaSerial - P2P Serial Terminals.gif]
Passing text between two terminals


*Passing simple text data between two radios*

The default settings are as follows:

* **Mode:** Point to Point
* **Frequency:** 902 to 928 MHz
* **Channels:** 50
* **Frequency Hopping:** Enabled
* **Broadcast Power:** 30 dbm
* **Airspeed:** 4800 bps
* **Serial:** 57600 bps
* **Encryption:** Enabled
* **Encryption Key:** Default<sup>1</sup>
* **Software CRC:** Enabled

<sup>1</sup> The radios default to a published encryption key. For maximum security, we recommend changing the key and network ID value using command mode or the [training process](http://docs.sparkfun.com/SparkFun_LoRaSerial/training/).

Serial can be passed into the unit either through the USB port, or over the serial connector. If the serial connector is used, the baud rate is 57600 bps by default.

LoRaSerial is designed to get small amounts of data from point A to point B as easily as possible. If you've got a sensor, or Arduino, or any device that can output serial, then it can transmit data over long distances. LoRaSerial has been used to send data over 9 miles (14 km) line-of-sight.

## Additional Documentation

The LoRaSerial products are described in the [introduction](http://docs.sparkfun.com/SparkFun_LoRaSerial/intro/). The [radios](http://docs.sparkfun.com/SparkFun_LoRaSerial/hardware_overview/) support several [operating modes](http://docs.sparkfun.com/SparkFun_LoRaSerial/operating_modes/).

* [Point-to-Point](https://docs.sparkfun.com/SparkFun_LoRaSerial/operating_modes/#point-to-point) with guaranteed delivery or the link breaks
* [Multipoint](https://docs.sparkfun.com/SparkFun_LoRaSerial/operating_modes/#multipoint), two or more LoRaSerial radios, is best for real-time applications but uses broadcast datagrams that may be lost

Enter [command mode](http://docs.sparkfun.com/SparkFun_LoRaSerial/at_commands/) to change modes and adjust the parameters for that mode of operation. [Training](http://docs.sparkfun.com/SparkFun_LoRaSerial/training/) is the process to distribute the set of parameters from a server radio (server=1) to the other client radios (server=0). Training can be done one radio at a time or multiple radios at once.

The green LEDs by default display a received signal strength indication. The more LEDs that are on the better the signal. However other [LED patterns](http://docs.sparkfun.com/SparkFun_LoRaSerial/led_states/) are available to provide more data on the radio behavior.

Occasionally, SparkFun may release new firmware for LoRaSerial. The
[firmware update](http://docs.sparkfun.com/SparkFun_LoRaSerial/firmware_update/) procedure enables you to load the firmware into the LoRaSerial radio. Advanced users may also want to [build](http://docs.sparkfun.com/SparkFun_LoRaSerial/firmware_build/) the [open source LoRaSerial firmware](https://github.com/sparkfun/SparkFun_LoRaSerial).

### Hardware Documentation

The following hardware documents are available:

* [Schematic](https://cdn.sparkfun.com/assets/9/3/0/6/e/SparkFun_LoRaSerial_915MHz_-_1W.pdf)
* [Eagle Files](https://cdn.sparkfun.com/assets/d/e/c/e/5/SparkFun_LoRaSerial_915MHz_-_1W.zip)
* [Semtech SX1276 datasheet](https://cdn.sparkfun.com/assets/7/7/3/2/2/SX1276_Datasheet.pdf)
* [Ebyte E19-915M30S Datasheet](https://cdn.sparkfun.com/assets/6/3/e/e/3/E19-915M30S_Usermanual_EN_v1.20.pdf)
* [Atmel SAMD-21 datasheet](https://cdn.sparkfun.com/datasheets/Dev/Arduino/Boards/Atmel-42181-SAM-D21_Datasheet.pdf)
* [Understanding LoRa PHY](https://wirelesspi.com/understanding-lora-phy-long-range-physical-layer/) - A good article on the math behind Semtec's Long Range modulation technique

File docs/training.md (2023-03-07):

# Training

Training is the process of passing a radio's set of parameters to other radios so that they can successfully communicate.

Training button on LoRaSerial

*The train button on the LoRaSerial*

There are two ways to initiate training:

* Pressing the **Train** button on the end of the LoRaSerial device
* Entering the **ATT** command

Training is performed by a server radio sending parameters to the client radio. Upon reception, the client radio saves the parameters in non-volatile memory and then reboots with the new parameters.

Pressing and releasing the training button for different lengths of time initiates the following behaviors.

A ball-point pen is best for pressing the training button. *Be gentle.* The training button can be damaged with too much force.

## Training as Client

Press and hold the training button until the yellow LED starts to blink then release the button. The cylon pattern appears on the green LEDs. The device is now ready to receive settings from a Server. Once settings are received from a server, the device saves the parameters to NVM and then reboots with the new settings.

If training needs to be canceled, press and release the training button before the yellow LED starts to blink to exit training mode. No settings will be modified. The radio will return to normal operation.

## Training as Server

Press and hold the training button until the blue LED starts to blink then release the button. The Cylon pattern appears on the green LEDs. In this mode, the radio will respond to any training client with its settings. The radio will not exit this mode unless it is powered cycled or the **ATZ** reset command is issued.

This mode (Training as Server) is convenient when multiple clients need to be paired to a server. For example, when a device is configured to be a Server in Multipoint mode, putting it in *Training as Server* mode will allow a user to put another radio into *Training as Client*. The radios will communicate and the Server radio will configure the client radio. Any number of client radios can be quickly and conveniently configured this way.

## Simple Point-To-Point Training

If a radio is set for P2P mode, entering training mode as a server will generate a new random NetID and AES key. In other words, pushing the Train button and releasing it after the blue LED flashes on one radio will cause that radio to generate new, unique/secure P2P settings. On the other radio, press the Train button and release it after the yellow LED flashes. The radios will be trained to the new AES key and NetID, and the radios will reset, then immediately link up. This is helpful in the field if you need to put a pair of radios onto a different network and encryption key from other radios that may be nearby.

## Factory Reset

Press and hold the training button for 10 seconds to Factory Reset the radio. Release the button when all the LEDs blink quickly three times during the reset.  Just before reset the NVM is erased and LoRaSerial returns to factory settings. Note: You can also return a radio to factory defaults using the **ATF** command.

## Temporary Training Server

It is possible to use a temporary training server for multipoint mode. The only difference between a temporary server and a regular server is that the parameters are not saved to the non-volatile storage of the server using the ATW command before exiting command mode.

## Example: Training a Batch of Radios

To get a known set of parameters onto a network of radios, choose one radio to be the server. Enter command mode on the chosen server radio and set the radio's parameters as desired. Once complete, save the settings to NVM (**ATW** command) then enter training mode (**ATT**). From here, you may either use the Training buttons on the Client radios or you may use AT commands. Here is the same scenario in step-by-step instructions:

Server:

* Enter command mode with **+++**
* Optionally, start from factory defaults with **ATF**
* Set the desired parameters
* Set AT-Server=1
* Record settings with **ATW**
* Enter training mode with **ATT**
* Have other radios enter into Training as Client mode
* Power cycle Server radio when clients are trained

Clients can enter training via the **ATT** command:

* Enter command mode with **+++**
* Enter training mode with **ATT**
* The client will now obtain settings from the Server
* Settings saved to NVM
* Radio reboots

Alternatively, the Client can enter training via the button:

* Press the training button and release it when the yellow LED
* The client will now obtain settings from the Server
* Settings saved to NVM
* Radio reboots

## Command Scripts

A command script is simply a text file containing the AT commands the user would like to program. For example, the following script will enter command mode, reset the device to defaults, set the radio to be Server, record settings to NVM, and then exit command mode.

    +++
    ATF
    AT-Server=1
    ATW
    ATO

Copying and pasting command scripts into a terminal program is an efficient way of configuring a radio.

## Training Parameters

The training parameters for radio communication fall into two groups:

* Radio parameters
* Radio protocol parameters

Other optional sets of training parameters may be communicated between the radios when the corresponding copyXxxx parameter is set to true (1). The optional parameter sets are:

* Serial parameters
* Debug parameters
* Trigger parameters

For more information about the various radio settings, please see [AT Commands](http://docs.sparkfun.com/SparkFun_LoRaSerial/at_commands/).

## Security Considerations

**Summary:** We recommend training radios located next to each other, in a secure area with antennas removed, to limit the amount of RF emissions and potential security issues. If security is a great concern, do not use training. Instead, AT commands can be used to set the settings between radios including AES keys.

During training, the Server will broadcast sensitive information including AES keys. Additionally, all radios used in training will use the default, published training settings. These include the following important parameters:

* 14dBm lower power transmission
* Default training frequency and hop tables
* Default training AES key

By default, radios will use the lowest power transmission possible of 14dBm. This is to limit RF eavesdropping. While data is encrypted and frequency hopping is used, the key *is* publicly published, and the hop table could be deduced. In theory, the transmitted parameters, including link keys that are trained to the Client could be obtained. 

If desired, the AES key used during training can be assigned to all units either using training (note the security issue) or via AT commands. This allows future training to be secure.

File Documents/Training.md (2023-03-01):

LoRaSerial Training
===================

# Goals

There are two goals for LoRaSerial training:

1 Establish a common set of communication parameters between a set of LoRaSerial radios.
2 Make it easy to test an initial pair of LoRaSerial radios through the use of the training button.

# Methods of Training

There are two methods of initiating training:

* Pressing the training button on the top of the LoRaSerial module
* Entering the ATT command

Training is performed by a server radio sending parameters to the client radio.  Upon reception the client radio saves the parameters in non-volatile memory and then reboots with the new parameters.

## Training Button Behavior

Pressing and releasing the training button for different lengths of time initiates the following behaviors:

* 2 Seconds:
    * Enter training as a client, cylon pattern appears on the green LEDs
    * Exit training (client or server) without saving parameter changes, cylon pattern stops and previous LED pattern returns
* 5 Seconds - Enter training as a server, yellow LED flashes 3 times when 5 seconds of press time is detected, cylon pattern appears on the green LEDs when the button is released
* 15 Seconds - Reset LoRaSerial to factory settings and erase NVM, blue LED flashes 3 times when 15 seconds of press time is detected

# Temporary Training Server

It is possible to use temporary training servers for multipoint and virtual circuit modes.  The only difference with a temporary server and a regular server is that the parameters are not saved to the non-volatile storage using the ATW command before exiting command mode.

# Point-To-Point Training

To get a known set of parameters on the client radio, use command mode to initialize the parameters on the server.  Using the training buttons on both radios only changes
the network ID and encryption key values, it does not change any of the other parameters such as AirSpeed.

Point-to-Point Training Examples:

Server:
* Enter command mode using +++
* Optional, start from factory defaults by issuing the ATF command
* Set the desired parameters
* Set Server=1
* Enter training mode using ATT command
* After the client is trained
* Saves new parameters for netID and encryptionKey
* Reboots

Server (no clients):
* Enter command mode with +++
* Set any of the desired parameters
* Enter training mode with ATT command
* No client to be trained
* Exit command mode with ATO or ATZ

Assuming the radios are already able to communicate, use the training button to select a random NetID and EncryptionKey value.

Server:
* 2 second training button press
* Does not receive training from a server
* After 3 seconds, generates new netID and encryption key and automatically switches to server mode
* Wait for client to be trained
* Saves new parameters for netID and encryptionKey
* Reboots

Server:
* 5 second training button press
* Generates new netID and encryption key
* Wait for client to be trained
* Saves new parameters for netID and encryptionKey
* Reboots

Client:
* 2 second training button press
* Receives training parameters from server
* Saves new parameters
* Reboots

Client:
* Enter command mode using +++
* Enter training using the ATT command
* Receives training parameters from server
* Saves new parameters
* Reboots

Point-To-Point Timeout Examples:

Client:
* 2 second training button press
* Before three seconds
* 2 second training button press, exits training without receiving any new parameters

Server:
* 2 second training button press
* Does not receive training from a server
* After 3 seconds, generates new netID and encryption key and automatically switches to server mode
* 2 second training button press, exits training and does not save new netID or encryption key

Server:
* 5 second training button press
* Generates new netID and encryption key
* 2 second training button press, exits training and does not save new netID or encryption key

# Multi-Point Training

It is recommend to use a command script to initialize the server radio when performing multipoint traning.  The client radios can either use command mode or the training button to enter training mode.

Temporary Server (Doesn't save settings):
* If not already at factory reset, hold the training button down for 15 seconds
* Connect to the LoRaSerial radio via USB or the serial port
* Enter command mode with +++
* Start from factory defaults by issuing the ATF command
* Issue the following commands:
    * AT-OperatingMode=0
    * AT-Server=1
    * AT-SelectLedUse=1
    * ATG
* Set any of the other parameters
* Enter training mode with ATT command
* Wait for clients to be trained
* Exit command mode with ATO command or reboot with ATZ command

Server (Saves settings):
* If not already at factory reset, hold the training button down for 15 seconds
* Connect to the LoRaSerial radio via USB or the serial port
* Enter command mode with +++
* Start from factory defaults by issuing the ATF command
* Issue the following commands:
    * AT-OperatingMode=0
    * AT-Server=1
    * AT-SelectLedUse=1
    * ATG
* Set any of the other parameters
* Enter training mode with ATT command
* Wait for clients to be trained
* Save parameters with ATW command
* Always reboot with ATZ command

Client:
* 2 second training button press
* Receives training parameters from server
* Saves new parameters
* Reboots

Client:
* Connect to the LoRaSerial radio via USB or the serial port
* Enter command mode using +++
* Enter training using the ATT command
* Receives training parameters from server
* Saves new parameters
* Reboots

# Virtual Circuit Training

It is recommend to use a command script to initialize the server radio when performing virtual-circuit traning.  The client radios can either use command mode or the training button to enter training mode.

Temporary Server (Doesn't save settings):
* If not already at factory reset, hold the training button down for 15 seconds
* Connect to the LoRaSerial radio via USB or the serial port
* Enter command mode with +++
* Start from factory defaults by issuing the ATF command
* Issue the following commands:
    * AT-OperatingMode=2
    * AT-Server=1
    * AT-SelectLedUse=2
    * ATG
* Set any of the other parameters
* Enter training mode with ATT command
* Wait for clients to be trained
* Exit command mode with ATO command or reboot with ATZ command

Server (Saves settings):
* If not already at factory reset, hold the training button down for 15 seconds
* Connect to the LoRaSerial radio via USB or the serial port
* Enter command mode with +++
* Start from factory defaults by issuing the ATF command
* Issue the following commands:
    * AT-OperatingMode=2
    * AT-Server=1
    * AT-SelectLedUse=2
    * ATG
* Set any of the other parameters
* Enter training mode with ATT command
* Wait for clients to be trained
* Save parameters with ATW command
* Always reboot with ATZ command

Client:
* 2 second training button press
* Receives training parameters from server
* Saves new parameters
* Reboots

Client:
* Connect to the LoRaSerial radio via USB or the serial port
* Enter command mode using +++
* Enter training using the ATT command
* Receives training parameters from server
* Saves new parameters
* Reboots

# Training Parameters

The training parameters for radio communication fall into two groups:

* Radio parameters
* Radio protocol parameters

Other optional sets of training parameters may be communicated between the radios when the corresponding copyXxxx parameter is set to true (1).  The optional parameter sets are:

* Serial parameters
* Debug parameters
* Trigger parameters

The following sections describe the communication parameters.

## Radio Parameters

The following parameters describe the radio transmit operation:

* AutoTuneFrequency - Adjust the frequency based upon the last received frame's frequency error.

* FrequencyHop - Enable or disable frequency hopping.  Legal operation in the United States requires that this value be set to true (1) which is the default.  This parameter specifies whether the radio will change frequencies to a new channel every MaxDwellTime milliseconds.

* FrequencyMax - Maximum frequency the radio will use specified in MegaHertz.  The default value is 928.0 MHz.

* FrequencyMin - Minimum frequency the radio will use specified in MegaHertz.  The default value is 902.0 MHz.

* MaxDwellTime - Number of milliseconds that the LoRaSerial radio uses a specific frequency (channel).  After this time, the radio switches (hops) to another frequency.  For operation within the United States this value must not be greater than 400 milliseconds which is the default.

* NumberOfChannels - Specify the number of unique frequencies that will be used by the LoRaSerial radio.  For operation within the United States this value needs to be a minimum of 50 which is the default value.

* RadioBroadcastPower_dbm - Transmit power level for the LoRaSerial radio.  The valid range for this parameter is from 14 (25 milliWatts) to 30 dBm (1 Watt).  The default value is 30 dBm.

### Frame Synchronization Parameters

The following parameters specify data that the radios use for data synchronization and frame reception:

* RadioPreambleLength - Number of symbols to transmit at the beginning of the frame to notify the receiving radios of the incoming frame.  The range of values are 6 to 65535 with the default being 8.  The preamble is used to synchronize the PLLs in the radio to properly detect the symbol boundaries.  NOTE: Different lengths does *not* guarantee a remote radio privacy. 8 to 11 works. 8 to 15 drops some. 8 to 20 is silent.

* RadioSyncWord - The sync word following the preamble indicates the destination set of radios.  Note that different sync words do *not* guarantee a remote radio will not receive a rogue frame.

### AirSpeed

The parameter AirSpeed is a simplification that selects values for the following parameters to approximate the baud rate implied by the AirSpeed.

* HeartbeatTimeout
* RadioBandwidth
* RadioCodingRate
* RadioSpreadFactor
* TxToRxUsec

Valid values for AirSpeed are (40, 150, 400, 1200, 2400, 4800, 9600, 19200, 28800 and 38400) and the default is 4800.  After AirSpeed is set, it is possible to modify any of the parameters above.  Note that AirSpeed is just an easy way to set the parameters above to known value.  AirSpeed is not an actual parameter that is used for training, only the parameters listed above are used during training.  More detail for these parameters is provided below:

* HeartbeatTimeout - Heartbeats are transmitted on a regular basis by the server and in point-to-point and virtual circuit modes by the clients.  This parameter specifies the time in milliseconds during which a HEARTBEAT frame should be transmitted.  If a HEARTBEAT frame is not received within three (3) times this interval then the point-to-point or virtual circuit link is broken.  The default heartbeatTimeout is 5000 milliseconds (5 seconds).

* RadioBandwidth - Bandwidth of the spread spectrum signal specified in kiloHertz.  The default is 500.0 kHz and other supported values are: 10.4, 15.6, 20.8, 31.25, 41.7, 62.5, 125 and 250 kHz.

* RadioCodingRate - Number of bits to send 4 data bits of information.  This is used for forward error correction, allowing the receiver to correct the incoming bit stream.  Valid values are 5 through 8 where higher coding rates ensure less frames are dropped.  The default value is 8.

* RadioSpreadFactor - Number of bits in a symbol.  Valid values are 6 to 12 with the default value of 9.  Larger values enable longer range while reducing the data rate.

* TxToRxUsec - Transition time from end of transmission to the end of reception on the remote radio specified in microseconds.

## Radio protocol parameters

The following parameters describe the contents of the data frame sent between the LoRaSerial radios:

* DataScrambling - Enable (1) or disable (0) the use of IBM's Data Whitening algorithm to reduce DC bias

* EnableCRC16 - Enable (1) or disable (0) adding a software generated CRC-16 to the end of the data frame.

* EncryptData - Enable (1) or disable (0) the use of AES encryption for each data frame

* EncryptionKey - The 16 byte encryption key specified in hexadecimal.  While SparkFun provides a default value, it is strongly recomended to change this value for your own networks.

* FramesToYield - When requested by the remote radio, suppress transmission for this number of max packet frames.  The valid range is 0 to 255 with a default value of 3.

* MaxResends - Number of retransmission attempt to make for a each frame when an ACK is not received from the destination radio.  The valid range is 0 to 255.  The default of zero represents infinite and retries will continue as long as the two radios are receiving HEARTBEAT frames from each other.  The transmission will fail only when the link breaks due to not receiving HEARTBEAT frames.

* NetID - A unique value denoting the network of LoRaSerial radios.  All radios in the network must share the same ID value.  This value is in addition to the radioSyncWord.

* OperatingMode - The following modes of operation are supported by the LoRaSerial radios:

    * MODE_MULTIPOINT (0) - A single server with multiple clients, all radios are sending datagram frames which are not guarranteed to be received by the other radios.  This mode is great when real-time transmission is necessary and the application is able to tolerate some loss of data.

    * MODE_POINT_TO_POINT (1, default) - Communications between only two LoRaSerial radios with guarranteed delivery of frames or the link breaks.

    * MODE_VIRTUAL_CIRCUIT - A single server with multiple clients that supports multipoint communications with guarranteed delivery or the link breaks.  This mode uses a special protocol over the serial link to be able to specify the destination radio for transmission and the receive radio for reception.  More information is available [here](https://github.com/sparkfun/SparkFun_LoRaSerial/blob/release_candidate/Documents/Virtual_Circuits.md).

* OverheadTime - The number of milliseconds to add to ACK and datagram times before ACK timeout occurs.  The default is 10 milliseconds.

* SelectLedUse - Select how to display information on the LEDs

* Server - Enable (1) or disable (0) the server mode for training and for multipoint or virtual circuit operation.  The default is client mode (0).

* VerifyRxNetID - Enable (1) or disable (0) the verification of the netID value during reception.  The default is enabled (1).

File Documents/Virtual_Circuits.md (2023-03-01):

Virtual Circuit Mode
====================

Multiple radios can communicate to each other in Virtual Circuit mode.  This mode provides guaranteed message delivery or the link breaks.  Virtual circuit mode supports:
* Up to 32 radios
* Virtual circuit serial interface
* Local command support
* Remote command support
* [Header file](https://github.com/sparkfun/SparkFun_LoRaSerial/blob/release_candidate/Firmware/LoRaSerial_Firmware/Virtual_Circuit_Protocol.h) for C and C++

## Virtual Circuit Network Configuration

A LoRaSerial virtual circuit network consists of a single server radio and up to 31 client radios.  The server transmits HEARTBEAT frames that provide the synchronization signal for the channel hop timer.  Each time the timer fires, the radio switches to a new center frequency (channel).

Clients wait to receive a HEARTBEAT frame from the server on channel 0.  If the selectLedUse is set to LED_VC (2) then the blue LED will flash upon when the server's HEARTBEAT frame is received.  After receiving the server's HEARTBEAT frame the client synchronizes its hop timer and starts hopping channels.  If the selectLedUse is set to LED_VC (2) then each hop is indicated by a flash of the yellow LED.

The virtual circuit server assigns virtual circuit ID numbers to all of the client radios.  This may be done during radio training or during the first time the radio is connected to the network.  After receiving a HEARTBEAT frame from the server, the client sends a HEARTBEAT frame with the source VC address of VC_UNASSIGNED and the radio's 16-byte unique ID.  The server echos this HEARTBEAT replacing the source VC with the assigned VC number.  While the client is using VC_UNASSIGNED as it's VC number, the client radio compares the unique ID in the HEARTBEAT frame to the local radio's unique ID value.  If the values match then the client replaces its VC number with the assigned VC number.

For consistent processing, the server records the client unique ID values in the non-volatile memory.  These values are read and loaded into the virtual circuit table when the system boots again.

### Radio Parameters

Select a LoRaSerial radio for the virtual circuit server.  Set the following parameters on the server radio.

The following parameters should be set to enable virtual circuit mode:
* AT=OperatingMode=2 - Select virtual circuit mode
* AT-NetID=n - Choose a unique value (n) for your network
* AT-VerifyNetID=1 - Eliminate communications from other radios which are not using the NetID value
* AT-EnableCRC16=? - Enable software CRC-16 by setting the value to 1, otherwise set the value to zero to disable software CRC
* AT-EncryptionKey=? - Choose a unique encryption key for the network
* AT-SelectLedUse=2 - The use of LEDS_VC (2) flashes the blue LED when server HEARTBEAT frames are received by the clients, providing a visual indication that the radio is synchronizing with the server
* AT-Server=1 - Define this radio as the virtual circuit server
* ATW - Write the parameters to the non-volatile memory (NVM).

Now enter training mode with the ATT command.  The training enables the server to pass these parameters (except for server) to the client radios.  On the client radios, with power applied, press the button at the top of the client radio to enter training mode.  The radio will obtain the parameters from the server, write them to NVM and then reboot using the new parameters.

After all of the client radios are trained, the ATZ command may be entered on the server radio to cause it to reboot.

#### Example Virtual Circuit Initialization Script for Training

    +++
    AT=OperatingMode=2
    AT-NetID=3
    AT-VerifyNetID=1
    AT-EnableCRC16=1
    AT-EncryptionKey=54637374546373745463737454637374
    AT-SelectLedUse=2
    AT-Server=1
    ATW
    ATT

## Virtual Circuit Communications

Communication is possible between the server and client or between clients. A three-way handshake must be performed prior to normal data communications to synchronize the ACK numbers.  By default, the three-way handshake is not performed.  The user or application initiates the handshake using the AT-CmdVc=n to select the client or server radio (n) for communications.  Next the ATC command initiates the three-way handshake between the local radio and the remote radio (n).

After the three-way handshake communications between the two radios is possible in virtual circuit mode.

## Virtual Circuit Number

The virtual circuit number of the local radio is obtained by issuing the ATI11 command to the local radio.  The response returns a number in the range of zero (0) to MAX_VC.  The value VC_UNASSIGNED is returned between reset until the server assigns a virtual circuit number to the local radio.

## Virtual Circuit Serial Interface

In virtual circuit mode all communications over the serial port must be proceeded by a VC_SERIAL_MESSAGE_HEADER.  Data not proceeded by a VC_SERIAL_MESSAGE_HEADER data structure is discarded!  The VC_SERIAL_MESSAGE_HEADER is defined in the [Virtual_Circuit_Protocol.h](https://github.com/sparkfun/SparkFun_LoRaSerial/blob/release_candidate/Firmware/LoRaSerial_Firmware/Virtual_Circuit_Protocol.h) header file.  This data structure is four (4) bytes long starting with the value START_OF_VC_SERIAL (2).  The next byte specifies the length of the binary data following the VC_SERIAL_MESSAGE_HEADER plus the size of VC_RADIO_MESSAGE_HEADER (3).  The other two bytes are virtual circuit numbers for the destination and source virtual circuits.

The server radio is identified by VC_SERVER (0) and client radios have VC numbers between 1 and MAX_VC.  A data message sent from the server to client 3 would have the source VC set to VC_SERVER (0) and the destination VC set to 3.  Example:

    START_OF_VC_SERIAL
    +-----+-----+-----+-----+-----+-----+-----+-----+-----+
    |  2  |  8  |  3  |  0  |  H  |  e  |  l  |  l  |  o  |
    +-----+-----+-----+-----+-----+-----+-----+-----+-----+
          Length  Dest  Src   Data

### Radio Responses

The LoRaSerial radio will return the following responses:

* Data response
* Local command response
* Remote command response
* VC state response
* Reconnect serial response

#### Data Response

When sending a data message, the radio returns a VC_DATA_ACK_NACK_MESSAGE.  The response is sent to PC_DATA_ACK (0xe2) when the data is acknowledged by the remote radio.  A response of PC_DATA_NACK (0xe3) is returned when the link is broken.

    START_OF_VC_SERIAL
    +-----+-----+-----+-----+-----+-----+-----+-----+-----+
    |  2  |  8  |  B  |  A  |  H  |  e  |  l  |  l  |  o  |
    +-----+-----+-----+-----+-----+-----+-----+-----+-----+
          Length  Dest  Src   Data

    Host A              Radio A             Radio B             Host B
    Data Message  --->
                        Data Message  --->
                                      <---  ACK
                                            Data Message  --->
                  <---  VC_DATA_ACK_NACK_MESSAGE

    START_OF_VC_SERIAL
    +-----+-----+--------+-----+
    |  2  |  3  |  0xe2  |  B  |
    +-----+-----+--------+-----+
          Length   Dest    Src

#### Local Command Response
When sending a local command, the radio responds with VC_COMMAND_COMPLETE_MESSAGE sent to PC_COMMAND_COMPLETE (0xe5) with the status VC_CMD_SUCCESS (0) or VC_CMD_ERROR (1).

One pair of virtual circuit numbers allows the local host to communicate with the command interface on the local radio.  The data portion of the message contains the command to be executed.

* VC_COMMAND (0xfe): Destination VC used by the host computer to send a command to the local radio to be executed immediately

* PC_COMMAND (0xe0): Source VC for the local command message

        START_OF_VC_SERIAL
        +-----+-----+------+------+-----+-----+-----+-----+-----+------+------+
        |  2  |  8  | 0xe5 | 0xe0 |  A  |  T  |  I  |  1  |  1  | 0x0d | 0x0a |
        +-----+-----+------+------+-----+-----+-----+-----+-----+------+------+
              Length  Dest   Src    Command

        Host A                 Radio A
        Command Message  --->
                         <---  Command response (ASCII text)
        +------+------+---+---+---+---+---+---+...+------+------+---+---+------+------+
        | 0x0d | 0x0a | m | y | V | c | : |   | A | 0x0d | 0x0a | O | K | 0x0d | 0x0a |
        +------+------+---+---+---+---+---+---+...+...+--+------+---+---+------+------+
                         <---  VC_COMMAND_COMPLETE_MESSAGE

        START_OF_VC_SERIAL
        +-----+-----+--------+-----+-----+
        |  2  |  4  |  0xe2  |  A  |  0  |
        +-----+-----+--------+-----+-----+
              Length   Dest    Src  VC_CMD_SUCCESS

#### Remote Command Response

A command sent to a remote radio is acknowledged with a VC_DATA_ACK_NACK_MESSAGE sent to the PC_DATA_ACK (0xe2) or PC_DATA_NACK (0xe3) destination port.  The actual command response is sent to the local radio's VC ored with PC_REMOTE_RESPONSE (0xc0).  After the command response text is delivered, the command status is returned to the destination VC of PC_COMMAND_COMPLETE (0xe5) with the status of VC_CMD_SUCCESS (0) or VC_CMD_ERROR (1).

The VC number range from 32 to 63 is reserved for remote command execution. The VC number equals the target radio number (0 - 31) or-ed with PC_REMOTE_COMMAND (0x20). This VC number is placed in the destination VC field and the local radio VC number is placed in the source VC field.

The following example sends an ATI11 command from radio A to radio B to get radio
B's VC number:

    START_OF_VC_SERIAL
    +-----+------+----------+-----+-----+-----+-----+-----+-----+------+------+
    |  2  |  10  | 0x20 + B |  A  |  A  |  T  |  I  |  1  |  1  | 0x0d | 0x0a |
    +-----+------+----------+-----+-----+-----+-----+-----+-----+------+------+
          Length    Dest     Src   Command

    Host A                 Radio A               Radio B
    Command Message  --->
                           Remote Command  --->
                                           <---  ACK
                     <---  VC_DATA_ACK_NACK_MESSAGE

    START_OF_VC_SERIAL
    +-----+-----+--------+-----+
    |  2  |  3  |  0xe2  |  B  |
    +-----+-----+--------+-----+
          Length   Dest    Src

                                           <---  Remote Command Response
                     <---  Remove Command Response
    +---+----+----------+---+------+------+---+---+---+---+---+---+...+------+------+---+---+------+------+
    | 2 | 18 | 0xc0 + A | B | 0x0d | 0x0a | m | y | V | c | : |   | B | 0x0d | 0x0a | O | K | 0x0d | 0x0a |
    +---+----+----------+---+------+------+---+---+---+---+---+---+...+...+--+------+---+---+------+------+

                                           <---  VC_COMMAND_COMPLETE_MESSAGE
                     <---  VC_COMMAND_COMPLETE_MESSAGE

    START_OF_VC_SERIAL
    +-----+-----+--------+-----+-----+
    |  2  |  4  |  0xe5  |  B  |  0  |
    +-----+-----+--------+-----+-----+
          Length   Dest    Src  VC_CMD_SUCCESS

#### VC State Response

As VC links change states, the host is notified of the state changes with a VC_STATE_MESSAGE sent to PC_LINK_STATUS (0xe1).  An example where radio A detects the initial HEARTBEAT frame from radio B and notifies host A of the VC link change:

    Host A        Radio A        Radio B

                           <---  HEARTBEAT
            <---  VC_STATE_MESSAGE

    START_OF_VC_SERIAL
    +-----+-----+--------+-----+----------+
    |  2  |  4  |  0xe1  |  B  |  Status  |
    +-----+-----+--------+-----+----------+
          Length   Dest    Src  VC_CMD_SUCCESS

The status values are:

* VC_STATE_LINK_DOWN (0): HEARTBEATs not received
* VC_STATE_LINK_ALIVE (1): Receiving HEARTBEATs, waiting for UNKNOWN_ACKS
* VC_STATE_SEND_UNKNOWN_ACKS (2): ATC command received, sending UNKNOWN_ACKS
* VC_STATE_WAIT_SYNC_ACKS (3): UNKNOWN_ACKS sent, waiting for SYNC_ACKS
* VC_STATE_WAIT_ZERO_ACKS (4): SYNC_ACKS sent, waiting for ZERO_ACKS
* VC_STATE_CONNECTED (5): ZERO_ACKS received, ACKs cleared, ready to send data

#### Reconnect Serial Response

The ATZ command causes the system to reboot.  Prior to the reboot, the radio responds with a message sent to PC_SERIAL_RECONNECT (0xe4).  The local radio takes a couple of seconds to reset and causes the USB serial device to go off-line.  The timing is critical here, the application must close the serial connection before the LoRaSerial USB device goes off-line.  If the host is still holding the USB serial connection open when the LoRaSerial USB serial port goes off-line then the host may not be able to release it in time before the LoRaSerial attempts to connect its USB serial port.  In this case, the LoRaSerial serial port may show up as a new device on the host system and
further communications with the radio would no longer be possible using the previous device path.

An example is below:

    START_OF_VC_SERIAL
    +-----+-----+------+------+-----+-----+-----+------+------+
    |  2  |  8  | 0xe5 | 0xe0 |  A  |  T  |  Z  | 0x0d | 0x0a |
    +-----+-----+------+------+-----+-----+-----+------+------+
           Length  Dest   Src  Command

        Host A                 Radio A
        Command Message  --->
                         <---  Command response (ASCII text)

        +---+---+------+------+
        | O | K | 0x0d | 0x0a |
        +---+---+------+------+

                         <---  Reconnect message

        START_OF_VC_SERIAL
        +-----+-----+--------+-----+
        |  2  |  3  |  0xe4  |  A  |
        +-----+-----+--------+-----+
              Length   Dest    Src

                         <---  VC_COMMAND_COMPLETE_MESSAGE

        START_OF_VC_SERIAL
        +-----+-----+--------+-----+-----+
        |  2  |  4  |  0xe2  |  A  |  0  |
        +-----+-----+--------+-----+-----+
              Length   Dest    Src  VC_CMD_SUCCESS

## Example Program

The [VcServerTest.c](https://github.com/sparkfun/SparkFun_LoRaSerial/blob/release_candidate/Firmware/Tools/VcServerTest.c) is an example C program that communicates with the VC server using the virtual circuit serial interface.  The first parameter is the device path to the local LoRaSerial radio.  The second parameter specifies the destination VC number to send commands or data.

The example program has the following features:

* <code>--reset</code> command line option
* <code>--break</code> command line option
* Gets the local radio's virtual circuit number
* Opens a virtual circuit to the target VC
* Passes entered serial data to the target VC
* Displays responses from the target VC

### Debug Defines

There are some useful defines that may be set to one (1) to display the host's interaction with the radio.  These defines are:

* DEBUG_PC_TO_RADIO
* DEBUG_RADIO_TO_PC
* DUMP_RADIO_TO_PC

Setting these defines will display the radio communications in hexadecimal and ASCII.

### <code>--reset</code>

The reset command line option is not used very often, but sends an ATZ command to the local radio.

### <code>--break</code>

The break command line option sends an ATB command to the local radio causing it to delay for 5 times the heartbeatTimeout interval.  This delay is sufficient to break all links with any remote virtual circuits.  Following the delay, the radio returns to the RADIO_RESET state and brings up links to the other radios.

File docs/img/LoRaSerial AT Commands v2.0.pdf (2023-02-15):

AT Command | Command Description
Radio Command | Command Description | Default | Min Val | Max Val

Must be same
on networked
radios
+++ | Enter command mode
AT | Reports OK
AT? | Display help text
ATA | Get the current VC status
ATB | Break the link
ATC | Establish VC connection for data
ATD | Display the debug settings
ATF | Restore factory settings
ATG | Generate new netID and encryption key
ATI | Display the radio version
ATI? | Display the information commands
ATIn | Display system information
ATO | Exit command mode
ATP | Display probe trigger settings
ATR | Display radio settings
ATS | Display the serial settings
ATT | Enter training mode
ATV | Display virtual circuit settings
ATW | Save current settings to NVM
ATZ | Reboot the radio
AT-Param=xxx | Set parameter's value to xxx by name (Param)
AT-Param? | Print parameter's current value by name (Param)
AT-? | Display the setting values
AT-AirSpeed | | 4800 | 0 | 38400 | Yes
AT-AutoTune | Adjust frequency based on received frequency offset | 1 | 0 | 1 | No
AT-Bandwidth | Low number is longer range, less datarate | 500.0 | 10.4 | 500.0 | Yes
| Seconds before FIND_PARTNER xmit during training | 3 | 0 | 255 | Yes
AT-CodingRate | Set LoRa link coding rate denominator | 8 | 5 | 8 | Yes
AT-DataScrambling Apply IBM Data Whitening to reduce DC bias | 1 | 0 | 1 | Yes
AT-EnableCRC16 | Include 16-bit CRC with each packet | 1 | 0 | 1 | Yes
AT-EncryptData | Use AES-128-GCM for each packet | 1 | 0 | 1 | Yes

Data rate over the air. Overrides bandwidth, spread, a

AT-ClientFindPartnerR

AT-EncryptionKey | 16 byte key used for AES encryption | * | 0 | 16 Bytes | Yes
AT-FramesToYield | | 3 | 0 | 255 | No
AT-FrequencyHop | Enable frequency hopping spread spectrum | 1 | 0 | 1 | Yes
AT-FrequencyMax | Maximum allowed radio frequency | 928.0 | ≥Min | 928.0 | Yes
AT-FrequencyMin | Minimum allowed radio frequency | 902.0 | 902.0 | ≤Max | Yes
AT-HeartBeatTimeout ms wait before sending link ping | 5000 | 250 | 65535 | No
AT-MaxDwellTime | Amount of time before hopping | 400 | 10 | 65535 | Yes
AT-MaxResends | Attempts before dropping packet | 0 | 0 | 255 | No
AT-NetID | Network ID | 192 | 0 | 255 | Yes
| Divide available spectrum by this amount | 50 | 1 | 255 | Yes
AT-OperatingMode | Multipoint, P2P, or VC | 1 | 0 | 2 | Yes
AT-OverHeadtime | Additional ms before ACK timeout occurs | 10 | 0 | 65535 | Yes
AT-PreambleLength Set LoRa preamble length | 8 | 6 | 65535 | Yes*
AT-SelectLedUse | Define LED behavior | 1 | 0 | 4 | No
AT-Server | Synchronize network clock | 0 | 0 | 1 | No
AT-SpreadFactor | High number is longer range, less datarate | 9 | 6 | 12 | Yes
AT-SyncWord | Set LoRa sync word | 0x12 | 0 | 255 | Yes*
AT-TrainingKey | 16 byte AES key used during training | ** | 0 | 16 Bytes | Yes
AT-TxPower | Transmit power in dBm | 30 | 14 | 30 | No
AT-TxToRxUsec | μs between when TX sends and RX gets packet | 657 | 0 | 65535 | Yes
AT-VerifyRxNetID | Validate packets against the NetID | 1 | 0 | 1 | Yes
ATI0 | Show user settable parameters
ATI1 | Show board variant
ATI2 | Show firmware version
ATI3 | Display RSSI value
ATI4 | Get random byte from RSSI
ATI5 | Show max possible bytes per second
ATI6 | Display AES key
ATI7 | Show current FHSS channel
ATI8 | Display system unique ID
ATI9 | Display the maximum datagram size
ATI10 | Display radio metrics
ATI11 | Return myVc value

Pause transmission for X frames to allow 2-way traffic

AT-NumberOfChanne

Info Command Command Description

ATI12 | Display the VC details
ATI13 | Display the SX1276 registers
ATI14 | Dump the radioTxBuffer
ATI15 | Dump the NVM unique ID table
AT-CopySerial | Copy the serial parameters to the training client | 0 | 0 | 1 | No
AT-Echo | Print locally inputted serial | 0 | 0 | 1 | No
AT-FlowControl | Enable the use of CTS/RTS flow control signals | 0 | 0 | 1 | No
AT-InvertCts | Invert the input of CTS | 0 | 0 | 1 | No
AT-InvertRts | Invert the output of RTS | 0 | 0 | 1 | No
AT-SerialDelay | ms of no data before fractional buffer is sent | 50 | 0 | 65535 | No
AT-SerialSpeed | Hardware UART baud rate | 57600 | 2400 | 115200 | No
AT-UsbSerialWait | Wait for USB enumeration before radio start | 0 | 0 | 1 | No
AT-CopyDebug | 0 | 0 | 1 | No
AT-Debug | 0 | 0 | 1 | No
AT-DebugDatagrams | 0 | 0 | 1 | No
AT-DebugHeartbeat | 0 | 0 | 1 | No
AT-DebugNvm | 0 | 0 | 1 | No
AT-DebugRadio | 0 | 0 | 1 | No
AT-DebugReceive | 0 | 0 | 1 | No
AT-DebugSerial | 0 | 0 | 1 | No
AT-DebugStates | 0 | 0 | 1 | No
AT-DebugSync | 0 | 0 | 1 | No
AT-DebugTraining | 0 | 0 | 1 | No
AT-DebugTransmit | 0 | 0 | 1 | No
AT-DisplayRealMillis | 0 | 0 | 1 | No
AT-PrintAckNumbers | 0 | 0 | 1 | No
AT-PrintChannel | 0 | 0 | 1 | No
AT-PrintFrequency | 0 | 0 | 1 | No
Serial Command | Command Description | Default | Min Val | Max Val

Must be same
on networked
radios
Debug Command | Command Description | Default | Min Val | Max Val

Must be same
on networked
radios

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
alit

y

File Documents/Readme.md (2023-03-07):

LoRaSerial Documents and Airspeed Calculations
========================================

SparkFun LoRaSerial Airspeed Spreadsheet (https://docs.google.com/spreadsheets/d/1qyJa3ldE-KDUHwHNSctBMccPTVRwKbmAsodkdvOc3-8/edit?usp=sharing)

The available airspeeds (400 to 19200) used in LoRaSerial were picked to, as closely as possible, mimic modem baud rates. Other spread factors, bandwidths, and coding rates can be used if desired.

[This spreadsheet](https://docs.google.com/spreadsheets/d/1qyJa3ldE-KDUHwHNSctBMccPTVRwKbmAsodkdvOc3-8/edit?usp=sharing) can be used to inspect the airtime formulas.

Additionally, this folder contains the various datasheets for the SX1276 IC, common to all LoRaSerial modules, as well as the individual datasheets for the different module types (915, 868, 433, etc).

[Atmel SAM D21G Datasheet](https://cdn.sparkfun.com/datasheets/Dev/Arduino/Boards/Atmel-42181-SAM-D21_Datasheet.pdf)

Please see the [LoRaSerial Product Manual](http://docs.sparkfun.com/SparkFun_LoRaSerial/) for all the general documentation on how to use LoRaSerial.

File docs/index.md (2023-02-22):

# Introduction

Out of the box, the SparkFun LoRaSerial products are simple-to-use point-to-point serial radio pair and can be used with little or no configuration. This [Product Manual](http://docs.sparkfun.com/SparkFun_LoRaSerial/quick_start/) provides detailed descriptions of all the available features of the LoRaSerial products.

The line of LoRaSerial products offered by SparkFun all run identical firmware. The [LoRaSerial repo](https://github.com/sparkfun/SparkFun_LoRaSerial) and this guide cover the following products:

<table class="table table-hover table-striped table-bordered">
  <tr align="center">
   <td></td>
   <td></td>
  </tr>
  <tr align="center">
    <td><a href="https://www.sparkfun.com/products/19311">SparkFun LoRaSerial Kit - 915MHz (WRL-19311)</a></td>
    <td><a href="https://www.sparkfun.com/products/20029">SparkFun LoRaSerial Enclosed Kit - 915MHz (WRL-20029)</a></td>
  </tr>
</table>

If you have an issue, feature request, bug report, or a general question about the LoRaSerial firmware specifically we encourage you to post your comments on the [firmware's repository](https://github.com/sparkfun/SparkFun_LoRaSerial/issues).

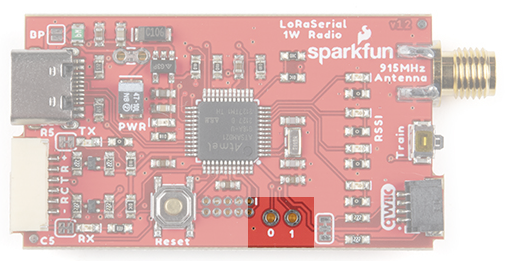
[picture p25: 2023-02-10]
docs/Original/SparkFun_LoRaSerial_-_GPIO.png

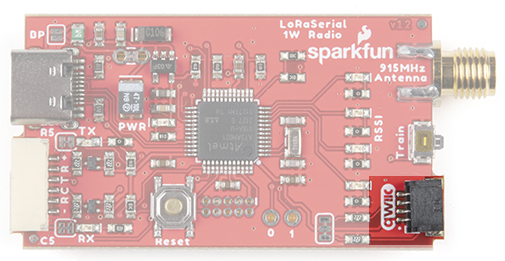
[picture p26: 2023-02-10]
docs/Original/SparkFun_LoRaSerial_-_Qwiic.png

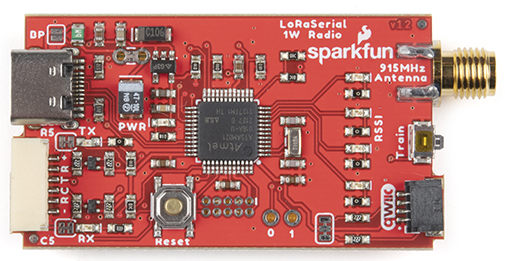
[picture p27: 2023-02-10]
docs/Original/SparkFun_LoRaSerial.png

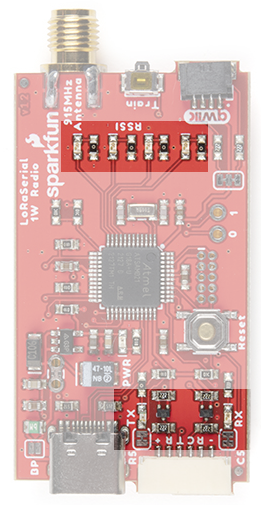
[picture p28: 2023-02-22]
docs/img/SparkFun_LoRaSerial_LEDs.png

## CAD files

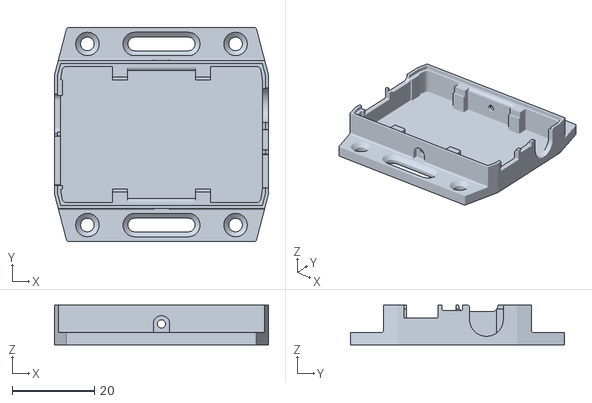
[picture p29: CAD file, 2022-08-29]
Enclosure/LRS-Enclosure-Body.stl
52.0 x 52.0 x 9.69

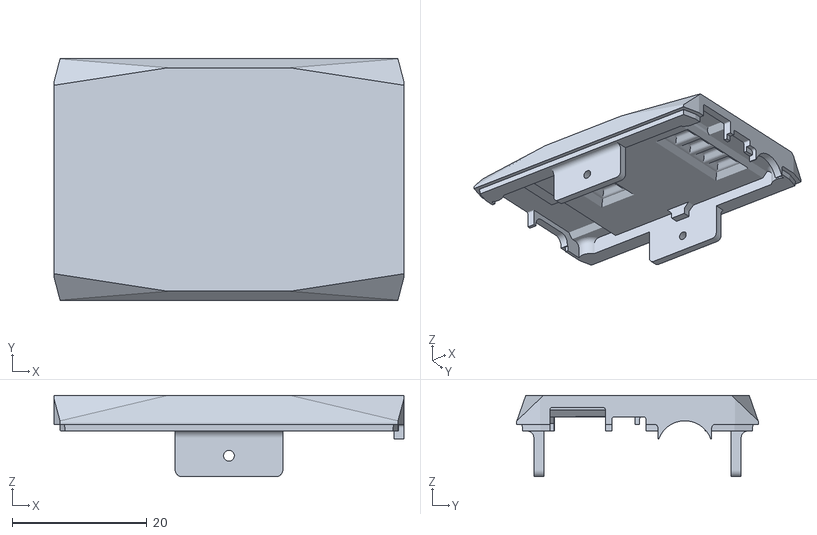
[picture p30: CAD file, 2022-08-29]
Enclosure/LRS-Enclosure-Lid.stl
52.0 x 36.0 x 12.1

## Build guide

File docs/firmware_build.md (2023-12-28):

# Building LoRaSerial Firmware

The open source [LoRaSerial firmware](https://github.com/sparkfun/SparkFun_LoRaSerial) builds under Windows and Linux.  Use the following procedures to setup the environment and perform the build:

* [Windows](http://docs.sparkfun.com/SparkFun_LoRaSerial/firmware_build/#Windows)
* [Linux](http://docs.sparkfun.com/SparkFun_LoRaSerial/firmware_build/#Linux)

## Ubuntu Build Environment

The following setup and build instructions were tested on Ubuntu 22.04.1. The build can run on a physical or virtual CPU. The following section describes how to setup a virtual machine. Further sections describe the build environment and how to perform the build.

### Virtual Machine

Execute the following commands in the [VirualBox](https://www.virtualbox.org/) application to create a virtual machine:

1. Click on the Machine menu item
2. Click on the New submenu item
3. Specify the machine Name, e.g.: Sparkfun_LoRaSerial_22.04.1
4. Select Type, e.g.: Linux
5. Select Version, e.g.: Ubuntu (64-bit)
6. Click the Next> button
7. Select the memory size: 7168
8. Click the Next> button
9. Click on Create a virtual hard disk now
10. Click the Create button
11. Select VDI (VirtualBox Disk Image)
12. Click the Next> button
13. Select Dynamically allocated
14. Click the Next> button
15. Select the disk size: 128 GB
16. Click the Create button
17. Click on the Settings button
18. Click on Storage
19. Click the empty CD icon
20. On the right-hand side, click the CD icon
21. Click on Choose a disk file...
An operating system is needed for the virtual machine to enable it to run applications.  Download one of the following operating system images (.iso files):

* [Ubuntu Desktop (Linux)](https://ubuntu.com/download/desktop)
* Windows

22. Choose one of the .iso files downloaded above
23. Click the Open button
24. Click on Network
25. Under 'Attached to:' select Bridged Adapter
26. Click the OK button
27. Click the Start button
28. Install the operating system
29. Log into the operating system

* For Ubuntu:
    1. Click on Activities
    2. Type terminal into the search box
    3. In the terminal window
        a. sudo apt install -y net-tools openssh-server
        b. ifconfig

        Write down the IP address

    4. On the PC (Linux) in a terminal window
        a. ssh-keygen -t rsa -f ~/.ssh/SparkFun_LoRaSerial_22.04.1
        b. ssh-copy-id -o IdentitiesOnly=yes -i ~/.ssh/SparkFun_LoRaSerial_22.04.1  &lt;username&gt;@&lt;IP address&gt;
        c. ssh -Y &lt;username&gt;@&lt;IP address&gt;

Execute the following commands to create the build environment for the SparkFun LoRaSerial Firmware:

1. sudo adduser $USER dialout
2. sudo shutdown -r 0

Reboot to ensure that the dialout privilege is available to the user

3. sudo apt update
4. sudo apt install -y  git  gitk  git-cola  minicom  python3-pip
5. sudo pip3 install pyserial
6. mkdir ~/SparkFun
7. cd ~/SparkFun
8. nano serial-57600.sh

Insert the following text into the file:

    #!/bin/bash
    #   serial-57600.sh
    #
    #   Shell script to read the serial data from the LoRaSerial USB port
    #
    #   Parameters:
    #       1:  ttyACMn
    #
    sudo minicom -b 57600 -8 -D /dev/$1 < /dev/tty

9. chmod +x serial-57600.sh

Get the SparkFun LoRaSerial Firmware sources

10. mkdir ~/SparkFun/LoRaSerial
11. cd ~/SparkFun/LoRaSerial
12. git clone [https://github.com/sparkfun/SparkFun_LoRaSerial](https://github.com/sparkfun/SparkFun_LoRaSerial) .

Install the Arduino IDE

13. mkdir ~/SparkFun/arduino
14. cd ~/SparkFun/arduino
15. wget https://downloads.arduino.cc/arduino-1.8.15-linux64.tar.xz
16. tar -xvf ./arduino-1.8.15-linux64.tar.xz
17. cd arduino-1.8.15/
18. sudo ./install.sh
19. arduino

# Setup the Arduino Build Environment

Install the ARM Cortex-M0+ tools.  See [SAMD21 MiniDev Hookup Guide](https://learn.sparkfun.com/tutorials/samd21-minidev-breakout-hookup-guide/setting-up-arduino) for more documentation.

1. Click on Tools in the menu bar
2. Click on Board
3. Click on Board Manager ...
4. Scroll down to Arduino SAMD Boards (32-bits ARM Cortex-M0+)
5. Click on Arduino SAMD Boards (32-bits ARM Cortex-M0+)
6. Select version 1.8.13
7. Click on the install button
8. Click on the close button

## Install the SparkFun Board Packages

9. Click on File in the menu bar
10. Click on Preferences
11. Go down to the Additional Boards Manager URLs text box
12. Only if the textbox already has a value, go to the end of the value or values and add a comma
13. Add the link: https://raw.githubusercontent.com/sparkfun/Arduino_Boards/main/IDE_Board_Manager/package_sparkfun_index.json
14. Note the value in Sketchbook location
15. Click the OK button
16. Click on Tools in the menu bar
17. Click on Board
18. Click on Board Manager ...
19. Scroll down and click on SparkFun SAMD Boards (dependency: Arduino SAMD Boards 1.8.1)
20. Select version 1.8.9
21. Click on the install button
22. Click on the close button
23. Click on Tools in the menu bar
24. Click on Board
25. Click on SparkFun SAMD (32-bits ARM Cortex-M0+) Boards
26. Click on SparkFun LoRaSerial

## Install the required libraries

The following procedure installs the libraries needed to successfully build the LoRaSerial firmware.

27. Click on Tools in the menu bar
28. Click on Manage Libraries...
29. For each library:

    a. Enter the library name into the search box
    b. Scroll down the list if necessary to locate the specified libray
    c. Click on the library
    d. Select the specified version
    e. Click on the install button

30. Install the following libraries:

    a. Crypto, v0.4.0
    a. FlashStorage_SAMD, v1.3.2
    a. JC_Button, v2.1.2
    a. RadioLib, v5.1.2
    a. SAMD_TimerInterrupt, v1.9.0

31. Click on File in the menu bar
32. Click on Quit

## External Libraries

The WDT library is not registered with the Arduino IDE.  It must be added outside of the Arduino IDE environment.  Install the external libraries adding them to the Sketchbook location noted above.

33. cd ~/Arduino/libraries
34. mkdir WDTZero
35. cd WDTZero/
36. git clone https://github.com/javos65/WDTZero.git .

# Build the LoRaSerial Firmware

Use the following procedure to get the project ready to build

1. arduino
2. Click on File in the menu bar
3. Click on Open
4. Select the project file: ~/SparkFun/LoRaSerial/Firmware/LoRaSerial/LoRaSerial.ino
5. Click on the Open button
6. Click on Tools in the menu bar
7. Verify that Board lists "SparkFun LoRaSerial"

## Connect the LoRaSerial Device

8. Plug the LoRaSerial device into a USB port on the PC
9. In the arduino program, click on Tools
10. Click on Ports
11. Select the port for the LoRaSerial device

## Compile

12. Click on Sketch in the menu bar
13. Click on Verify/Compile
14. Using an editor or the Arduino IDE ake any source file changes until the Sketch (program) compiles cleanly

## Upload the Firmware

15. Click on Sketch
16. Click on Upload

# Arduino CLI

The firmware can be compiled using [Arduino CLI](https://github.com/arduino/arduino-cli). This makes compilation fairly platform independent and flexible. All release candidates and firmware releases are compiled using Arduino CLI using a github action. You can see the source of the action [here](https://github.com/sparkfun/SparkFun_RTK_Firmware/blob/main/.github/workflows/compile-release.yml), and use it as a starting point for Arduino CLI compilation.

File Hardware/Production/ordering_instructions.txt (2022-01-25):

panel size, 168x128mm
PCB thickness, 1.6mm
number of layers, 2
soldermask color, Red
silkscreen color, White
oz copper, 1oz
finish, HASL lead free
stencils, none
pcs per panel, 12
min trace width, 0.1778mm / 0.0070in
min drill size, 0.3048mm / 0.0120in

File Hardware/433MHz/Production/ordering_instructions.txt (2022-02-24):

panel size, 116x153mm
PCB thickness, 1.6mm
number of layers, 4
soldermask color, Red
silkscreen color, White
oz copper, 1oz
finish, HASL lead free
stencils, none
pcs per panel, 10
min trace width, 0.1778mm / 0.0070in
min drill size, 0.3048mm / 0.0120in
filename to layer stackup 1/2/3/4: GTL, GL2, GL3, GBL

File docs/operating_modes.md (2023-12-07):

# Operating Modes

LoRaSerial radios can operate in one of two modes.

* [Point to Point](https://docs.sparkfun.com/SparkFun_LoRaSerial/operating_modes/#point-to-point) - Operating mode 1 (see [AT-OperatingMode](https://docs.sparkfun.com/SparkFun_LoRaSerial/at_commands/)).
* [Multipoint](https://docs.sparkfun.com/SparkFun_LoRaSerial/operating_modes/#multipoint) - Operating mode 0.

## Point to Point

By default, radios use Point to Point mode for communication. In this mode, data is limited to two paired radios.

Radio Linkup is performed at Channel 0: Both radios power on and begin pinging each other until another radio is detected. Once a handshake is complete, both radios begin hopping through their channel tables.

All data packets are acknowledged, guaranteeing that data will get across the link. If data is not able to traverse the link for 3 * Heartbeat Timeout (5 seconds by default) the link is marked as down and any data in the buffer is flushed. Radio Linkup is then initiated.

Benefits of P2P:

* Data is sent until it is successfully received.
* Simple to set up and use.

Disadvantages of P2P:

* Limited to data being shared between two radios.
* Lots of data being sent across a spotty link can lead to the link going down.
* Retransmits will add to latency.

## Multipoint

In Multipoint mode, data is sent out from one radio to all radios. Data *is not* acknowledged, and therefore is not guaranteed to be delivered.

One radio must be designated as Server. This radio is responsible for sending out heartbeat packets that synchronize the system.

Radio Linkup is performed during a discovery phase: The Server radio immediately begins hopping the channel table. When a Client radio is powered on, it will begin traversing the channel table, sending out pings. If no response is found, the Client radio will return to channel 0. The Server radio always transmits a heartbeat on channel 0. Once a heartbeat is detected, the Client radio begins hopping through its channel tables in sync with the Server.

Benefits of Multipoint:

* Similar to P2P, simple to set up and use. Whatever serial comes in gets broadcast.
* Supports up to 32 radios. Data can be broadcast/shared between multiple receivers. This is helpful in setups such as GNSS RTK where a Base receiver broadcasts correction data to multiple Rovers simultaneously.
* A larger continuous data stream can be transmitted. This assumes the user's application layer can handle lost packets graciously.
* This mode is most friendly to very long distance transmissions where an ACK may not be possible.

Disadvantages of Multipoint:

* Data is not retransmitted if lost.
* Additional setup requirements: One radio must be configured as Server.

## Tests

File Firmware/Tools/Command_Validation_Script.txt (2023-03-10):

+++
#Restore factory defaults
atf

# Display the commands
at?
ati?

# Allow leading white space (space, tab, cr, lf)
        	ati
        ati1
	ati2
ati3
ati4
ati5
ati6
ati7
ati8
ati9
ati10
ati0

#Debug parameters
at-CopyDebug=1
at-CopyDebug=2
at-CopyDebug=0
at-CopyDebug

at-Debug=1
at-Debug=2
at-Debug=0
at-Debug

at-DebugDatagrams=1
at-DebugDatagrams=2
at-DebugDatagrams=0
at-DebugDatagrams

at-DebugHeartbeat=1
at-DebugHeartbeat=2
at-DebugHeartbeat=0
at-DebugHeartbeat

at-DebugNvm=1
at-DebugNvm=2
at-DebugNvm=0
at-DebugNvm

at-DebugRadio=1
at-DebugRadio=2
at-DebugRadio=0
at-DebugRadio

at-DebugReceive=1
at-DebugReceive=2
at-DebugReceive=0
at-DebugReceive

at-DebugSerial=1
at-DebugSerial=2
at-DebugSerial=0
at-DebugSerial

at-DebugStates=1
at-DebugStates=2
at-DebugStates=0
at-DebugStates

at-DebugSync=1
at-DebugSync=2
at-DebugSync=0
at-DebugSync

at-DebugTraining=1
at-DebugTraining=2
at-DebugTraining=0
at-DebugTraining

at-DebugTransmit=1
at-DebugTransmit=2
at-DebugTransmit=0
at-DebugTransmit

at-DisplayRealMillis=1
at-DisplayRealMillis=2
at-DisplayRealMillis=0
at-DisplayRealMillis

at-PrintAckNumbers=1
at-PrintAckNumbers=2
at-PrintAckNumbers=0
at-PrintAckNumbers

at-PrintChannel=1
at-PrintChannel=2
at-PrintChannel=0
at-PrintChannel

at-PrintFrequency=1
at-PrintFrequency=2
at-PrintFrequency=0
at-PrintFrequency

at-PrintLinkUpDown=1
at-PrintLinkUpDown=2
at-PrintLinkUpDown=0
at-PrintLinkUpDown

at-PrintPacketQuality=1
at-PrintPacketQuality=2
at-PrintPacketQuality=0
at-PrintPacketQuality

at-PrintPktData=1
at-PrintPktData=2
at-PrintPktData=0
at-PrintPktData

at-PrintRfData=1
at-PrintRfData=2
at-PrintRfData=0
at-PrintRfData

at-PrintTimestamp=1
at-PrintTimestamp=2
at-PrintTimestamp=0
at-PrintTimestamp

at-PrintTxErrors=1
at-PrintTxErrors=2
at-PrintTxErrors=0
at-PrintTxErrors

#Radio Parameters
at-AirSpeed=0
at-AirSpeed=1
at-AirSpeed=40
at-AirSpeed=50
at-AirSpeed=110
at-AirSpeed=134
at-AirSpeed=150
at-AirSpeed=300
at-AirSpeed=400
at-AirSpeed=600
at-AirSpeed=1200
at-AirSpeed=2400
at-AirSpeed=4800
at-AirSpeed=9600
at-AirSpeed=14400
at-AirSpeed=19200
at-AirSpeed=28800
at-AirSpeed=38400
at-AirSpeed=57600
at-AirSpeed=76800
at-AirSpeed=115200
at-AirSpeed=128000
at-AirSpeed=230400
at-AirSpeed=250000
at-AirSpeed=256000
at-AirSpeed=460800
at-AirSpeed=500000
at-AirSpeed=512000
at-AirSpeed=576000
at-AirSpeed=921600
at-AirSpeed=1000000
at-AirSpeed=1843200
at-AirSpeed=2000000
at-AirSpeed=3000000
at-AirSpeed=3686400
at-AirSpeed=4000000
at-AirSpeed=4800
at-AirSpeed

at-AutoTune=1
at-AutoTune=2
at-AutoTune=0
at-AutoTune

at-Bandwidth=0
at-Bandwidth=10.4
at-Bandwidth=15.6
at-Bandwidth=20
at-Bandwidth=31.25
at-Bandwidth=41.7
at-Bandwidth=62.5
at-Bandwidth=125
at-Bandwidth=250
at-Bandwidth=500
at-Bandwidth

at-CodingRate=4
at-CodingRate=5
at-CodingRate=9
at-CodingRate=8
at-CodingRate

at-FrequencyHop=0
at-FrequencyHop=2
at-FrequencyHop=1
at-FrequencyHop

at-FrequencyMax=0
at-FrequencyMax=901.9
at-FrequencyMax=902
at-FrequencyMax=902.1
at-FrequencyMax=927.9
at-FrequencyMax=928.1
at-FrequencyMax=928
at-FrequencyMax

at-FrequencyMin=928
at-FrequencyMin=0
at-FrequencyMin=928.1
at-FrequencyMin=928
at-FrequencyMin=927.9
at-FrequencyMin=901.9
at-FrequencyMin=902
at-FrequencyMin

at-MaxDwellTime=9
at-MaxDwellTime=10
at-MaxDwellTime=65535
at-MaxDwellTime=65536
at-MaxDwellTime=400
at-MaxDwellTime

at-NumberOfChannels=0
at-NumberOfChannels=1
at-NumberOfChannels=255
at-NumberOfChannels=256
at-NumberOfChannels=50
at-NumberOfChannels

at-PreambleLength=5
at-PreambleLength=6
at-PreambleLength=255
at-PreambleLength=256
at-PreambleLength=65535
at-PreambleLength=65536
at-PreambleLength=8
at-PreambleLength

at-SpreadFactor=5
at-SpreadFactor=6
at-SpreadFactor=12
at-SpreadFactor=13
at-SpreadFactor=9
at-SpreadFactor

at-SyncWord=0
at-SyncWord=255
at-SyncWord=256
at-SyncWord=18
at-SyncWord

at-TxPower=13
at-TxPower=14
at-TxPower=31
at-TxPower=30
at-TxPower

at-TxToRxUsec=999999
at-TxToRxUsec=1000000
at-TxToRxUsec=0
at-TxToRxUsec

#Radio Protocol Parameters
at-DataScrambling=1
at-DataScrambling=2
at-DataScrambling=0
at-DataScrambling

at-EnableCRC16=0
at-EnableCRC16=2
at-EnableCRC16=1
at-EnableCRC16

at-EncryptData=0
at-EncryptData=2
at-EncryptData=1
at-EncryptData

at-EncryptionKey=00112233445566778899aabbccddeeff
at-EncryptionKey
at-EncryptionKey=00112233445566778899aabbccddeef
at-EncryptionKey=00112233445566778899aabbccddeefff
at-EncryptionKey=00112233445566778899aabbccddeefg
at-EncryptionKey=37782141A665734E4475672AE6308308
at-EncryptionKey

at-FramesToYield=255
at-FramesToYield=256
at-FramesToYield=0
at-FramesToYield

at-HeartBeatTimeout=249
at-HeartBeatTimeout=250
at-HeartBeatTimeout=65535
at-HeartBeatTimeout=65536
at-HeartBeatTimeout=5000
at-HeartBeatTimeout

at-MaxResends=0
at-MaxResends=255
at-MaxResends=256
at-MaxResends=2
at-MaxResends

at-NetID=0
at-NetID=255
at-NetID=192
at-NetID

at-OperatingMode=0
at-OperatingMode=1
at-OperatingMode

at-OverHeadtime=0
at-OverHeadtime=1001
at-OverHeadtime=1000
at-OverHeadtime

at-SelectLedUse=0
at-SelectLedUse=1
at-SelectLedUse=256
at-SelectLedUse=255
at-SelectLedUse=4
at-SelectLedUse

at-Server=1
at-Server=2
at-Server=0
at-Server

at-VerifyRxNetID=1
at-VerifyRxNetID=2
at-VerifyRxNetID=0
at-VerifyRxNetID

#Serial Parameters
at-CopySerial=1
at-CopySerial=2
at-CopySerial=0
at-CopySerial

at-Echo=1
at-Echo=2
at-Echo=0
at-Echo

at-FlowControl=1
at-FlowControl=2
at-FlowControl=0
at-FlowControl

at-InvertCts=0
at-InvertCts=2
at-InvertCts=1
at-InvertCts

at-RTSOffBytes=0
at-RTSOffBytes=1025
at-RTSOffBytes=1024
at-RTSOffBytes=32

at-RTSOnBytes=0
at-RTSOnBytes=1025
at-RTSOnBytes=1024
at-RTSOnBytes=256

at-InvertRts=0
at-InvertRts=2
at-InvertRts=1
at-InvertRts

at-SerialDelay=9
at-SerialDelay=10
at-SerialDelay=1
at-SerialDelay=2001
at-SerialDelay=2000
at-SerialDelay

at-SerialSpeed=0
at-SerialSpeed=1
at-SerialSpeed=40
at-SerialSpeed=50
at-SerialSpeed=110
at-SerialSpeed=134
at-SerialSpeed=150
at-SerialSpeed=300
at-SerialSpeed=400
at-SerialSpeed=600
at-SerialSpeed=1200
at-SerialSpeed=2400
at-SerialSpeed=4800
at-SerialSpeed=9600
at-SerialSpeed=14400
at-SerialSpeed=19200
at-SerialSpeed=28800
at-SerialSpeed=38400
at-SerialSpeed=57600
at-SerialSpeed=76800
at-SerialSpeed=115200
at-SerialSpeed=128000
at-SerialSpeed=230400
at-SerialSpeed=250000
at-SerialSpeed=256000
at-SerialSpeed=460800
at-SerialSpeed=500000
at-SerialSpeed=512000
at-SerialSpeed=576000
at-SerialSpeed=921600
at-SerialSpeed=1000000
at-SerialSpeed=1843200
at-SerialSpeed=2000000
at-SerialSpeed=3000000
at-SerialSpeed=3686400
at-SerialSpeed=4000000
at-SerialSpeed=57600
at-SerialSpeed

at-UsbSerialWait=1
at-UsbSerialWait=2
at-UsbSerialWait=0
at-UsbSerialWait

#Training Parameters
at-ClientFindPartnerRetryInterval=1
at-ClientFindPartnerRetryInterval=0
at-ClientFindPartnerRetryInterval=256
at-ClientFindPartnerRetryInterval=255
at-ClientFindPartnerRetryInterval

at-TrainingKey=00112233445566778899aabbccddeeff
at-TrainingKey
at-TrainingKey=00112233445566778899aabbccddeef
at-TrainingKey=00112233445566778899aabbccddeefff
at-TrainingKey=00112233445566778899aabbccddeefg
at-TrainingKey=37782141A665734E4475672AE6308308
at-TrainingKey

at-TrainingTimeout=0
at-TrainingTimeout=1
at-TrainingTimeout=256
at-TrainingTimeout=255
at-TrainingTimeout

#Trigger Parameters
at-CopyTriggers=1
at-CopyTriggers=2
at-CopyTriggers=0
at-CopyTriggers

at-TriggerEnable_31-0=4294967295
at-TriggerEnable_31-0=0
at-TriggerEnable_31-0

at-TriggerEnable_63-32=4294967295
at-TriggerEnable_63-32=0
at-TriggerEnable_63-32

at-TriggerWidth=0
at-TriggerWidth=1
at-TriggerWidth=256
at-TriggerWidth=255
at-TriggerWidth

at-TriggerWidthIsMultiplier=0
at-TriggerWidthIsMultiplier=2
at-TriggerWidthIsMultiplier=1
at-TriggerWidthIsMultiplier

ati0

atf

atz

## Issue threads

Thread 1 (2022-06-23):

Getting garbage data with RTK facet on radio port

coalman321, 2022-06-23:
Hi, i just picked u this radio kit to try with an RTK facet as a 915MHz local correction system. In trying this out, I have been unable to get valid RTCM data over the serial link. The modules and configurations do seem to be valid for sending data between USB connections of the two LoRaSerial modules, so the issue seems to be isolated to the UART connection.

Setup:
- Configure RTK facet to ouput on radio port at 19200 Baud
- Configure Facet side radio for 19200 baud and 38400 air speed (ATS0=19200 and ATS1=38400)
- Write radio configuration with AT&W
- Connect first LoRaSerial module to the RTK facet Radio port
- Repeat same radio configuration for the second LoRaSerial module
- Connect second LoRaSerial module over USBC to computer
- Reset both LoRaSerial modules
- Open serial terminal on second LoRaSerial module

This procedure, as well as some other variations of air speed (on the LoRaSerial modules) and baud rates (on all 3 devices) produces similarly garbage output. Personally, I'm not quite sure where to go from here beyond inspecting the raw packets. Any help would be greatly appreciated.

Also, something that might be helpful is a way to use the USBC port as a debug port when connected to the UART connector (for echoing received data and such).

nseidle, 2022-06-23:
This is the main application for LoRaSerial. Thanks for reporting a well described issue.

Your setup sounds good. However, RTCM is a binary encoded packet. It will appear as garbage viewed in a serial terminal. If you have a 2nd Facet, RTK Express, Surveyor, ZED-F9P, ZED-F9R, etc, available, you should be able to pipe the RTCM into that u-blox device and then view the successful RTCM packet reception via u-center MON-COMM message.

FWIW the default settings of LoRaSerial support RTCM packet delivery. ie, the default UART speed of 57600bps is the default for the RTK product line, and the default AirSpeed of 4800bps will support the ~500 bytes per second that RTCM needs.

> Also, something that might be helpful is a way to use the USBC port as a debug port when connected to the UART connector (for echoing received data and such).

This is an interesting idea. What debug information would you want to see?

nseidle, 2022-06-23:
> an echo of the incoming and outgoing traffic was my original idea

Incoming traffic is sent to both UART and USB ports. Echoing outgoing traffic would have to be marked as such (otherwise it looks like incoming).

> You would probably only want to do this though if the USB is connected at or during boot

There are quite a few applications where the radio is permanently attached via USB (ie a [GNSS reference station](https://learn.sparkfun.com/tutorials/how-to-build-a-diy-gnss-reference-station/all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)) for serial traffic. Auto-detecting intention will be difficult. That said, there is command **ATS20=1** that will enable debug messages. We would need to add some additional watermarking to echo other port data but let's make sure you're up and running before we start going down that feature path.

coalman321, 2022-06-23:
Yes, I was looking for a way to echo the outgoing traffic from the UART. Using ATS20 (or possibly another command?) might work better than auto-detecting intent in that case.  My concern with turning it on via other means without an actual USB connected could cause more power or resources to be used up for lower power or constrained installations.

coalman321, 2022-08-07:
Sorry that I dropped this for a bit. I was able to get the RTK data to transmit and receive correctly over the radios as expected. I did factory reset the radios out of precaution just in case i had modified any settings.

nseidle, 2022-08-10:
Awesome! Thanks for reporting back. Glad to hear it's working.

Closed 2022-08-10.

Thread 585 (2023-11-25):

When displaying airspeed, the zero is confusing and looks like a bug.  (1) back calc it or (2) document it

tonycanike, 2023-11-25:
### Subject of the issue
After a power cycle or reboot, the airspeed displays as zero.  How can I confirm that it is set properly?
I'm attempting to optimize the airspeed for RTCM data between to Facets to maximize the radio range, so I currently need to frequently check if the airspeed is set to 4800, 9600, or 19200 and if both units match.

Two suggestions/alternatives:

**Alternative 1:  Calc and display airspeed based on bw, coding, and spread**
When displaying the parameters (eg. ATI0), back-calculate the airspeed from the bandwidth, coding, and spread.  I'd guess you have a lookup table to set those three parameters when someone sets the airspeed; could you use that table  backwards?

If the bw, coding, and spread are set to non-standard values, that is values that would not be set from an at-airspeed=XXXX command, do something reasonable but not crazy, perhaps display "????".

**Alternative 2:  Document this behavior**
Simply document the behavior and provide a link in the product manual to
https://github.com/sparkfun/SparkFun_LoRaSerial/blob/main/Documents/Readme.md

----------------

### Your workbench
ATI1
SparkFun LoRaSerial SAMD21 1W 915MHz
OK
ati2
ATI2
2.0
OK

### Steps to reproduce
ATZ
OK
OK
ati0
ATI0
AT-AirSpeed=0
AT-AutoTune=0
AT-Bandwidth=500.00
AT-ClientFindPartnerRetryInterval=3
AT-CmdVC=0
AT-CodingRate=7
AT-CopyDebug=0
AT-CopySerial=0
AT-CopyTriggers=0
AT-DataScrambling=0
AT-Debug=0
AT-DebugDatagrams=0
AT-DebugHeartbeat=0
AT-DebugNvm=0
AT-DebugRadio=0
AT-DebugReceive=0
AT-DebugSerial=0
AT-DebugStates=0
AT-DebugSync=0
AT-DebugTraining=0
AT-DebugTransmit=0
AT-DisplayRealMillis=0
AT-Echo=0
AT-EnableCRC16=1
AT-EncryptData=1
AT-EncryptionKey=37782141A665734E4475672AE6308308
AT-FlowControl=0
AT-FramesToYield=3
AT-FrequencyHop=1
AT-FrequencyMax=928.000
AT-FrequencyMin=902.000
AT-HeartBeatTimeout=5000
AT-InvertCts=0
AT-InvertRts=0
AT-MaxDwellTime=400
AT-MaxResends=0
AT-NetID=192
AT-NumberOfChannels=50
AT-OperatingMode=0
AT-OverHeadtime=10
AT-PreambleLength=8
AT-PrintAckNumbers=0
AT-PrintChannel=0
AT-PrintFrequency=0
AT-PrintLinkUpDown=0
AT-PrintPacketQuality=0
AT-PrintPktData=0
AT-PrintRfData=0
AT-PrintTimestamp=0
AT-PrintTxErrors=0
AT-RTSOffBytes=32
AT-RTSOnBytes=256
AT-SelectLedUse=4
AT-SerialDelay=50
AT-SerialSpeed=57600
AT-Server=0
AT-SpreadFactor=8
AT-SyncWord=18
AT-TrainingKey=537061726B46756E547261696E696E67
AT-TrainingTimeout=1
AT-TriggerEnable_31-0=0
AT-TriggerEnable_63-32=0
AT-TriggerWidth=25
AT-TriggerWidthIsMultiplier=1
AT-TxPower=30
AT-TxToRxUsec=280
AT-UsbSerialWait=0
AT-VerifyRxNetID=1
OK
ato
ATO
OK

tonycanike, 2023-11-26:
I think I understand a little more now.  Airspeed is not a characteristic setting of the radio modem hardware.   Bandwidth, coding, and spread are.  When "setting" the airspeed, we are making a request for comms at that rate, not directly programming the radio modem to operate at the airspeed we request.

The LoRaSerial firmware takes our requested airspeed, and programs the bandwidth, coding, and spread of the radio modem.

I'll update this issue to, when displaying parameters, read the bandwidth, coding, and spread, calc the effective airspeed, and display it.

nseidle, 2023-12-07:
> do something reasonable but not crazy, perhaps display "????"

Yes, that was the bulk of the conversation we had when we were designing the airspeed command interface. For now, it's very not clean to try to back calculate the airspeed. A lookup table would be a reasonable fix. For now, [I've documented](https://docs.sparkfun.com/SparkFun_LoRaSerial/at_commands/#radio-commands) how AirSpeed is displayed and checked after a system reset.

tonycanike, 2023-12-08:
Awesome, thanks!

Closed 2023-12-07.

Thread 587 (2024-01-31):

Comm link too unstable for RTK use.

tonycanike, 2024-01-31:
Here is my problem description:
https://forum.sparkfun.com/viewtopic.php?f=116&t=60898

Multiple other users seem to be reporting this issue also.

viewtopic.php?f=116&t=60609
viewtopic.php?f=117&t=60671
viewtopic.php?f=117&t=60673
viewtopic.php?f=117&t=60872

nseidle, 2024-01-31:
Tony's configuration:

Base/Transmitter/Server
ATR
AT-AirSpeed=0
AT-AutoTune=0
AT-Bandwidth=500.00
AT-ClientFindPartnerRetryInterval=3
AT-CodingRate=7
AT-DataScrambling=0
AT-EnableCRC16=1
AT-EncryptData=1
AT-EncryptionKey=xxx
AT-FramesToYield=3
AT-FrequencyHop=1
AT-FrequencyMax=928.000
AT-FrequencyMin=902.000
AT-HeartBeatTimeout=5000
AT-MaxDwellTime=400
AT-MaxResends=0
AT-NetID=192
AT-NumberOfChannels=50
AT-OperatingMode=0
AT-OverHeadtime=10
AT-PreambleLength=8
AT-SelectLedUse=4
AT-Server=1
AT-SpreadFactor=8
AT-SyncWord=18
AT-TrainingKey=xxx
AT-TrainingTimeout=1
AT-TxPower=30
AT-TxToRxUsec=280
AT-VerifyRxNetID=1

ATS
AT-CopySerial=0
AT-Echo=0
AT-FlowControl=0
AT-InvertCts=0
AT-InvertRts=0
AT-RTSOffBytes=32
AT-RTSOnBytes=256
AT-SerialDelay=50
AT-SerialSpeed=57600
AT-UsbSerialWait=0
OK

Receiver/Rover
ATR
AT-AirSpeed=0
AT-AutoTune=0
AT-Bandwidth=500.00
AT-ClientFindPartnerRetryInterval=3
AT-CodingRate=7
AT-DataScrambling=0
AT-EnableCRC16=1
AT-EncryptData=1
AT-EncryptionKey=xxxx
AT-FramesToYield=3
AT-FrequencyHop=1
AT-FrequencyMax=928.000
AT-FrequencyMin=902.000
AT-HeartBeatTimeout=5000
AT-MaxDwellTime=400
AT-MaxResends=0
AT-NetID=192
AT-NumberOfChannels=50
AT-OperatingMode=0
AT-OverHeadtime=10
AT-PreambleLength=8
AT-SelectLedUse=4
AT-Server=0
AT-SpreadFactor=8
AT-SyncWord=18
AT-TrainingKey=xxxx
AT-TrainingTimeout=1
AT-TxPower=30
AT-TxToRxUsec=280
AT-VerifyRxNetID=1
OK

ats
ATS
AT-CopySerial=0
AT-Echo=0
AT-FlowControl=0
AT-InvertCts=0
AT-InvertRts=0
AT-RTSOffBytes=32
AT-RTSOnBytes=256
AT-SerialDelay=50
AT-SerialSpeed=57600
AT-UsbSerialWait=0

> My radios were in multipoint mode (this makes the most sense for the continuous stream of updated RTK data).

nseidle, 2024-01-31:
> I had SerialTest send a 100-character string every 500ms to my "server" LoRaSerial radio, and I monitored the output of the other radio with either Teraterm or another instance of SerialTest. The 4 green signal strength LEDs were illuminated on the receiving radio, I think 3 or 4 on the server/transmitting radio.

> The yellow LED on the server radio would flash with every string transmitted (every 500ms), and the blue LED on the other radios would flash with every string received (every 500ms). Sometimes, often after 4 or so minutes, the reception would stop, the data wasn't displayed in TeraTerm, the blue LED stopped flashing. Nothing would happen for about 30 seconds. Then the green LEDs would blink on the receiving radio, and everything would start working fine again. Sometimes this would happen again every 3-4 minutes, and sometimes it would not.

> It's like there's some bug and the receiving radio loses sync with the transmitting radio, and it has to restart/resync. The transmitting radio shows no apparent anomalous behavior - that yellow LED just keeps blinking every 500ms.

nseidle, 2024-01-31:
Thanks for reporting!

> after 4 or so minutes, the reception would stop,

It sounds as if the units are getting out of sync. In MP mode, the server is transmitting a clock sync but if the client misses the clock sync multiple times, it will eventually get off frequency and the link will go down. We have the time delay of the client realizing it's truly out of sync, and the time delay where the server has to come back around through the hop table. If the client misses the clock sync, it has another wait for the server to come around again. We have a few mitigations in place to reduce this time: the client will enter a discover_scan mode where it actively pings the hop table but this can come back negative if the server is actively transmitting when the client is pinging.

P2P doesn't have this time delay. Because they are expecting to regularly hear from each other, the desync and sync times are much shorter.

Point-To-Point and Multipoint are very different beasts. Are you seeing similar issues with Point-To-Point?

cturvey, 2024-02-01:
>>Point-To-Point and Multipoint are very different beasts.
Indeed, skimming thru this there doesn't look to be a method where one unit establishes itself as a master station, so they all potentially throw DATAGRAM_SYNC_CLOCKS packets at each other, or back-n-forth

cturvey, 2024-02-01:
In the One-to-Many situation, really need to establish one as the primary station, driving the hop time and pattern. The primary should be only one broadcasting DATAGRAM_SYNC_CLOCKS, and ideally this should communicate the time to next hop, and where it's going to go. The rest of the stations need to synchronize to this, and not be sending their own DATAGRAM_SYNC_CLOCKS as this will just result in chaos as there's no indication of who's in charge, some of the stations will not be in range of each other, and apt to be synchronized by the periodicity of the messaging from the GPS receivers.

Perhaps some way to identify who is sending sync messages, and some level of precedence. Data from GPS/GNSS should allow for  time domain synchronization around multiple units

tonycanike, 2024-02-01:
@nseidle  Nathan, thanks for jumping on this.

I don't have a solid answer on your P2P vs. MP question.  I'm geographically distant from my equipment right now and hope to work on this more mid-February.

I tried Point-to-Point once when I first got the LoRaSerial radios, but I've been focusing on MP as I believe it makes better sense for the RTK use case.   If data is lost forgetaboutit, as updated data will be sent in the next second.

I experienced the MP issues with the two radios within 5 feet of each other on my workbench.

@cturvey  I do configure the one radio at my RTK base to be the "server", and the docs say only the server is transmitting the sync heartbeats.  I haven't looked at the code though.
https://docs.sparkfun.com/SparkFun_LoRaSerial/operating_modes/

Tony.

cturvey, 2024-02-01:
Mostly just skimmed the source doing a quick static-analysis as to what looks to be going on, and where the sync packets are transmitted and where received. Unpacked the hopping somewhat, but suppose if it misses a hop it's going to have to wait until it cycles around. I'd need to get some units to do dynamic analysis and review debug output side-by-side, or back-port onto the DISCO / Murata platform

nseidle, 2024-02-01:
Hi @cturvey - I welcome the analysis and help. I can send you hardware if desired, just say the word and I'll PM you for an address.

cturvey, 2024-02-01:
TBH the logic as I'm unpacking it suggests that both ends schedule transmission, the server doesn't act on reception

https://github.com/sparkfun/SparkFun_LoRaSerial/blob/62aa9cc391a47dd5f0f9b08da599cfd0d7820ac1/Firmware/LoRaSerial/States.ino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

j-w-bullfrog, 2024-02-02:
Yes, Point -to Point has the same issues. I havn't seen any performance difference between to two modes, I also tested with the radio's between 1000ft, 10 & 3 ft apart so I could watch the led's.
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
j-w-bullfrog, 2024-02-14:
Tony, I've re-read your test procedure and it produces the same results that I got from using RTK in the setup, and what you have seen (weeks ago). I used both point to point, multipoint, both allowable speeds, and encryption disabled.  It does help the radios to supply them with separate power.

cturvey, 2024-02-14:
I haven't had much chance to work on this over the last week. I need to perhaps integrate some RTCM3 diagnostic output.

In terms of resyncing / recovery the channels could be reduced so it cycles quicker on 400 ms hops. Not sure of the feelings about cycling vs FCC compliance. LoRa already sweeps.
```
AT-NumberOfChannels=50
```

nseidle, 2024-02-14:
50 channel min required for FCC compliance. 400ms could be lowered but not increased.

HighSpeedLowDrag1, 2024-02-22:
> Multi-Point Server that only sends (no RSSI LEDs) and Multi-Point Client that just listens, waits for the Heart Beat to loop back, and doesn't send partner requests https://github.com/cturvey/SparkFun_LoRaSerial/tree/tinker/Firmware/LoRaSerial

Hi guys! I am very interested in what you are doing here and would like to help if I can. @cturvey Would there be a limit to the number of clients in this case? I have a need that requires more than 32 clients.

j-w-bullfrog, 2024-04-02:
Any solutions to getting a working radio set?  Thanks All.

nseidle, 2024-04-02:
Tony's original issue is with Multipoint. We are still working on a more robust solution for multipoint. Use the radios in P2P mode for now.

j-w-bullfrog, 2024-04-02:
As I stated previously, they don't work any better or differently in the
other mode.

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

tonycanike, 2024-05-30:
For RTK work, I really want simplex one-way base-to-rover transmissions.  The rover NEVER transmits any RF.  The Base just transmits and sends data.  The rover just receives.   No ACKs.  No retries.   No handshaking.   Keep it simple.   Here's why:

1.  POWER - the base radio can transmit at a higher power with an external battery, the rover can be powered off the Facet and receive.   We know the 1w radios can not be fully powered by the Facet radio port.   The Facet radio port is (understandably) voltage and current limited. It's not hard to put a battery and make a custom power cable for the base radio to fully power the base radio.  I find it surprisingly challenging to fully power the rover radio and not create nightmare for myself.

I spent 4 hours on my hands and knees crawling through dense autumn olive the other day with my Facet rover, pole, radio, and a weak JST connector cable.  Understory brush, briars, multi-flora, poison ivy, barberry, hawthorns, autumn olive, and all the other crap out there is grabby, pokey, prickly, itchy, and totally annoying.  The brush grabs at cables and external batteries and wants to eat them.   This is the reality of surveying.  Those pretty pictures of nicely-dressed happy smiling people with a rover on a manhole cover are total bs...well at least they don't correspond to my experience of surveying!

Having dangly cables, external batteries, and other choss on the rover pole is simply not a workable solution.  The rover setup needs to be robust, clean, simple, and lightweight.

Being able to fully power the base radio with an external battery and minimally power the rover radios off the Facet would be a great solution.  I tape up the JST cable to keep it in place.  Of course, this means the base radio probably will not be able to receive transmissions from the rover radio, hence this post.

2.  DUTY CYCLE & BANDWIDTH -  as others have points out above, if you're receiving you can't transmit.  If you're transmitting you can't receive.  It's just a waste of time for the base radio to receive.  It's just a waste of time for the rover radio to transmit, and the rover probably then misses data from the base.

3.  HIGHER PROBABILITY OF WORKING - if the radios aren't relying on handshakes, some data is more likely to get from the base to the rover.   If the rover misses a few packets, so what? No one cares. Next second new data comes down the pike.  The old data is worthless now, stop trying to resend it.   **Retries, handshakes, and acknowledgments are a non-value-add "feature" in a base-rover RTK radio link.**

I didn't invent the above - this is how the 450MHz band radios that most surveyors use work.

I, for one, have sadly put the SparkFun LoRaSerial radios into the "stuff that doesn't work" box.   I really wanted to like them.   I have some of the above power problems with the RFD900x radios I use, and I hate the "hard to see" LEDs on the RFD900x radios.   The SparkFun radios have great LEDs.

Raulricardo23, 2024-08-13:
SOME NEWS so that the multipoint signal is not lost

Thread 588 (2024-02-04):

Add new Repeater capability.

tonycanike, 2024-02-04:
Add a new feature to have a third LoRaSerial radio (or perhaps an additional pair of radios) repeat the data from a radio at an RTK base to the radio at an RTK rover.

As these radios are mostly line of sight, the ability to put a third unit on a hill top to repeat the data over a ridge would be very useful. Commercial survey RTK radios often have this capability.

Bonus if the rover can automatically switch from receiving from either the base radio or the repeater radio.

Use case:  the base and rover SparkFun RTK devices are setup with radios and surveying begins.  The rover moves away from the base and perhaps over hills.  If/when the signal from the base gets weak, the surveyor can back up and setup the repeater.  The rover radio automatically picks the stronger signal.  The surveyor can continue to move farther away from the base while surveying.

tonycanike, 2024-02-04:
Also see discussion in

https://forum.sparkfun.com/viewtopic.php?f=116&t=59557

cturvey, 2024-02-04:
Perhaps want to consider different profiles, with different min-max frequency bands or hop patterns, so the two don't step on each other.

Could cross connect a pair of radios via JST headers, running different profiles, and one as MULTIPOINT:STATION and other as MULTIPOINT:SERVER to rebroadcast.

JST Common Grounds, JST#1 TX  to JST#2 RX

The end-point radio being able to switch between the two profiles (DIRECT / REPEATER) would then be needed to handle this transparently.

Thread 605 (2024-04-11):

Intermittent Scrambled data from Serial

57hydra, 2024-04-11:
### Subject of the issue
For the most part, the LoRaSerial is perfect for my use case (since I need to just prototype as fast as possible). But something that I didn't realize until I started a continuous data stream is that sometimes the serial data comes in all scrambled. I originally thought this was an issue with my code implementation (`termios` usage written in C) to access the serial data but if I look at the data by setting the baud rate at the system level and use the `sudo cat </dev/ttyX>` command to see the incoming data, I see the same issue. After some time, the data seems to come in just fine with no issues.

I am honestly a bit new to this and I have a feeling that there is an obvious setting that I am missing/overlooking. I have tried changing a few settings but I seem to get the same behavior. Please let me know if there is something that you would like me to try out.

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
(From code implementation of reading Serial data)

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
(Displaying the received data using the cat command)

### Your workbench/What settings are you using? This is normally a list of AT commands that we can run against a radio to put it into an identical configuration to replicate the issue.

I am using two LoRaSerial devices that use a USB-C port to connect to a computer. After experimenting with some of the settings, I reset everything back to factory default and only changed the radios to **Multipoint Mode**.

I'm including all of the settings below:

ATI
SparkFun LoRaSerial SAMD21 1W 915MHz v2.0

ATI2
2.0

ATR
AT-AirSpeed=0
AT-AutoTune=0
AT-Bandwidth=500.00
AT-ClientFindPartnerRetryInterval=3
AT-CodingRate=8
AT-DataScrambling=0
AT-EnableCRC16=1
AT-EncryptData=1
AT-EncryptionKey=<omitted>
AT-FramesToYield=3
AT-FrequencyHop=1
AT-FrequencyMax=928.000
AT-FrequencyMin=902.000
AT-HeartBeatTimeout=5000
AT-MaxDwellTime=400
AT-MaxResends=0
AT-NetID=192
AT-NumberOfChannels=50
AT-OperatingMode=0
AT-OverHeadtime=10
AT-PreambleLength=8
AT-SelectLedUse=4
AT-Server=0 // (other radio has AT-Server=1)
AT-SpreadFactor=9
AT-SyncWord=18
AT-TrainingKey=<omitted>
AT-TrainingTimeout=1
AT-TxPower=30
AT-TxToRxUsec=657
AT-VerifyRxNetID=1
OK

ATS
AT-CopySerial=0
AT-Echo=0
AT-FlowControl=0
AT-InvertCts=0
AT-InvertRts=0
AT-RTSOffBytes=32
AT-RTSOnBytes=256
AT-SerialDelay=50
AT-SerialSpeed=57600
AT-UsbSerialWait=0
OK

ATP
AT-CopyTriggers=0
AT-TriggerEnable_31-0=0
AT-TriggerEnable_63-32=0
AT-TriggerWidth=25
AT-TriggerWidthIsMultiplier=1

### Steps to reproduce
Usually happens when you start the entire setup with the computer and the radios powering on at the same time.

### Expected behavior
I'd like to send an ASCII string with a length that is always fixed like this every 1 second (which is definitely within the AirSpeed limits).
`<R,1,0,13.9725684,-23.1726684,1,0,0,1>`

### Actual behavior
I instead receive mixed/scrambled data like this.
```
0,,1,0,13.97256<L,1,0,13.9725684,-206174<L,1,0,174<L,1,0,4<L,1,0,4<L,1,0,4<L,1,0,<R,1,0,13.9725684,-23.1726684,1,0,0,1>
```

Raulricardo23, 2024-08-12:
IF THAT CONFIGURATION WORKED FOR YOU, FRIEND, TO HAVE A BASE ON THE SERVER AND THE ROVER ON THE CLIENT

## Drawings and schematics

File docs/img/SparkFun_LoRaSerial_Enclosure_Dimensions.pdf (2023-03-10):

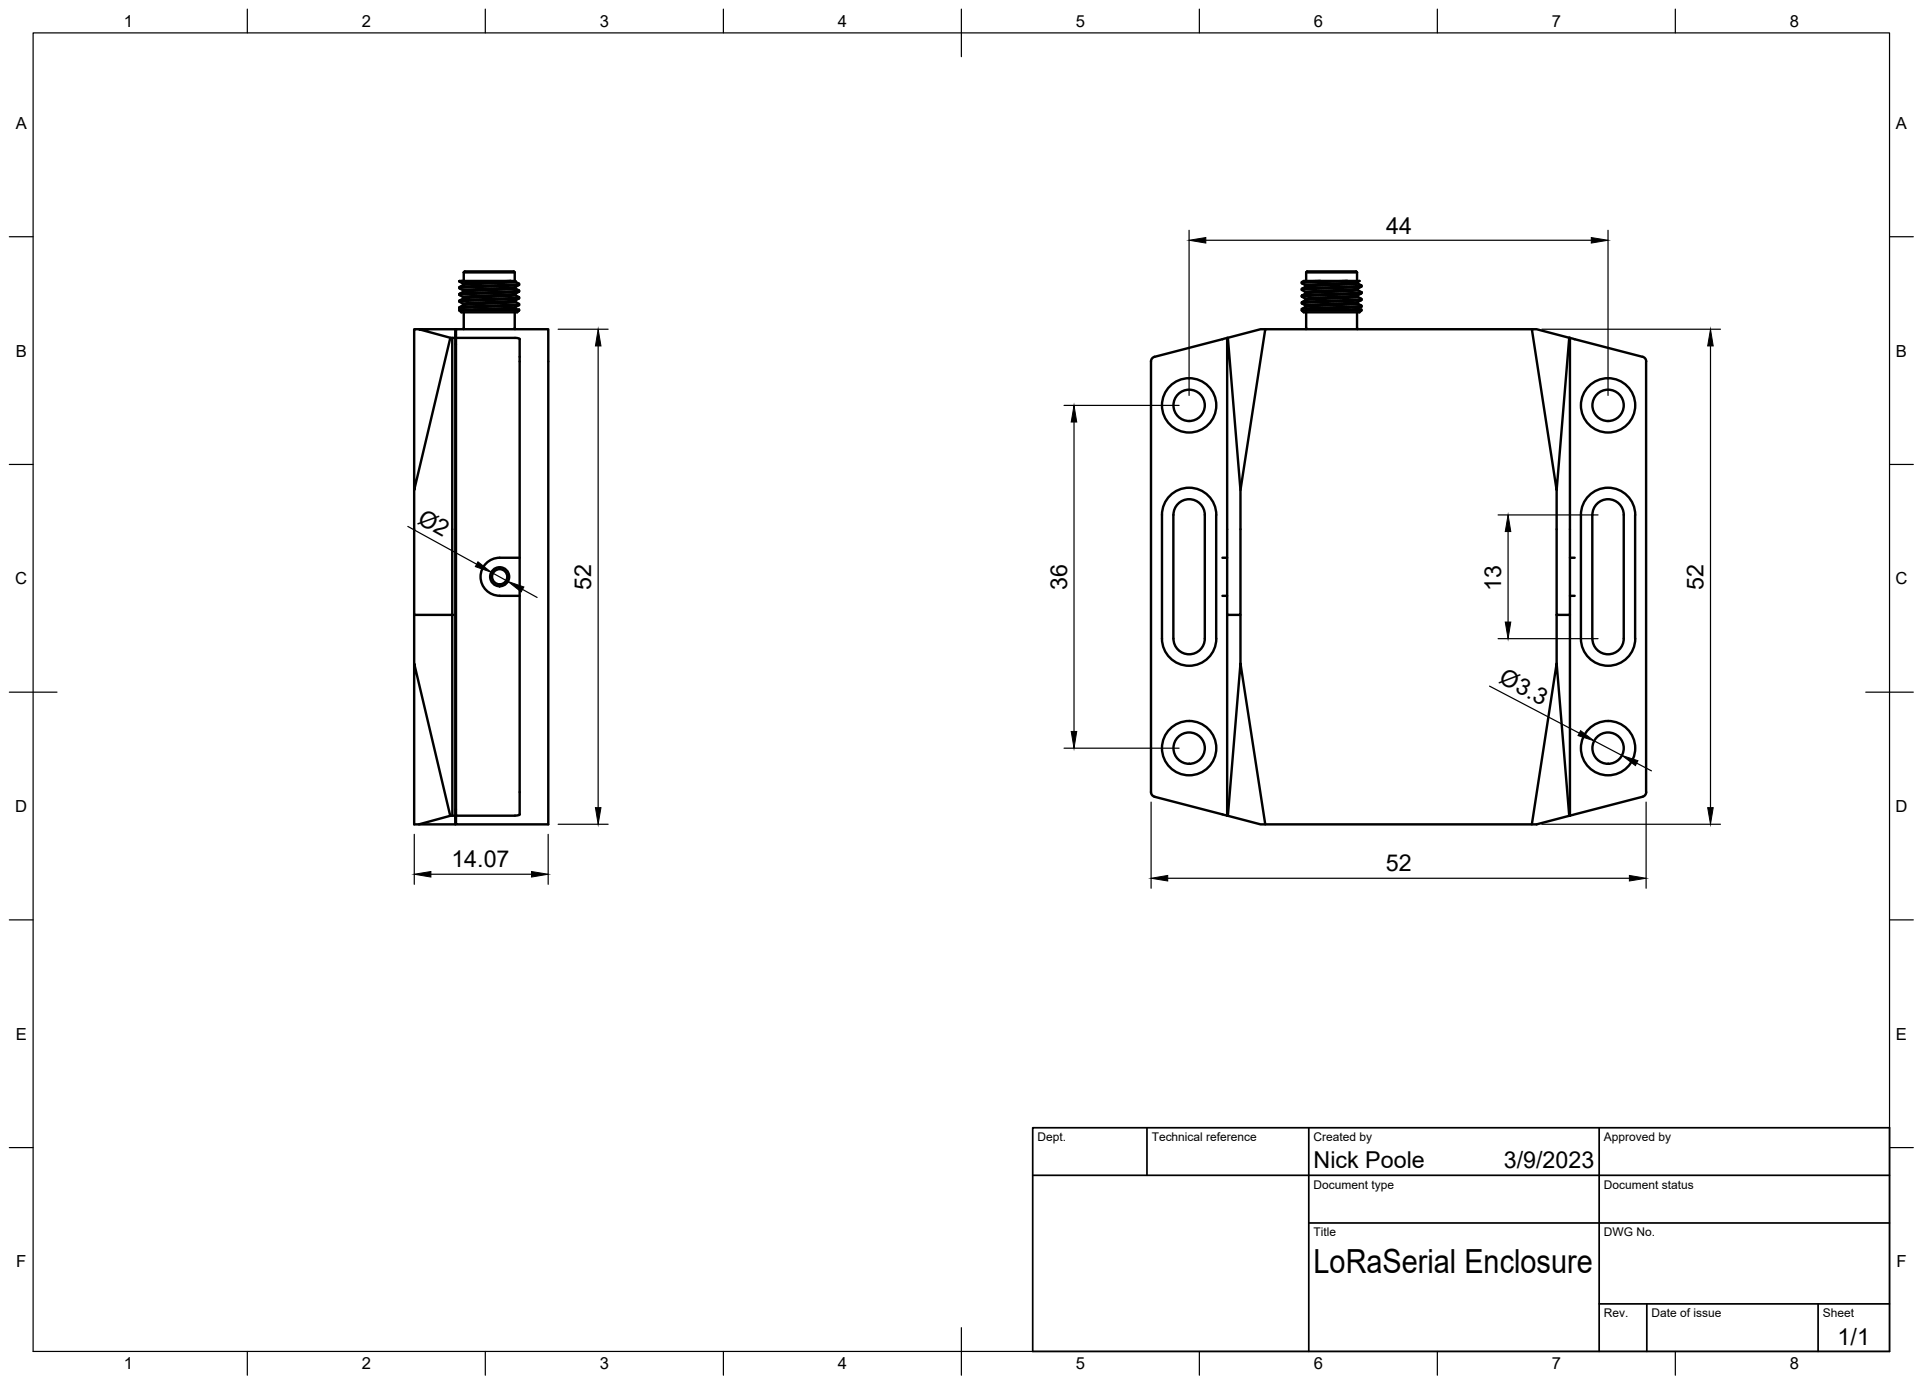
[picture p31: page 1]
Title; DWG No.; Rev.; Date of issue; Sheet; LoRaSerial Enclosure

Dept. | Technical reference | Created by Nick Poole 3/9/2023 | Approved by

Document type | Document status

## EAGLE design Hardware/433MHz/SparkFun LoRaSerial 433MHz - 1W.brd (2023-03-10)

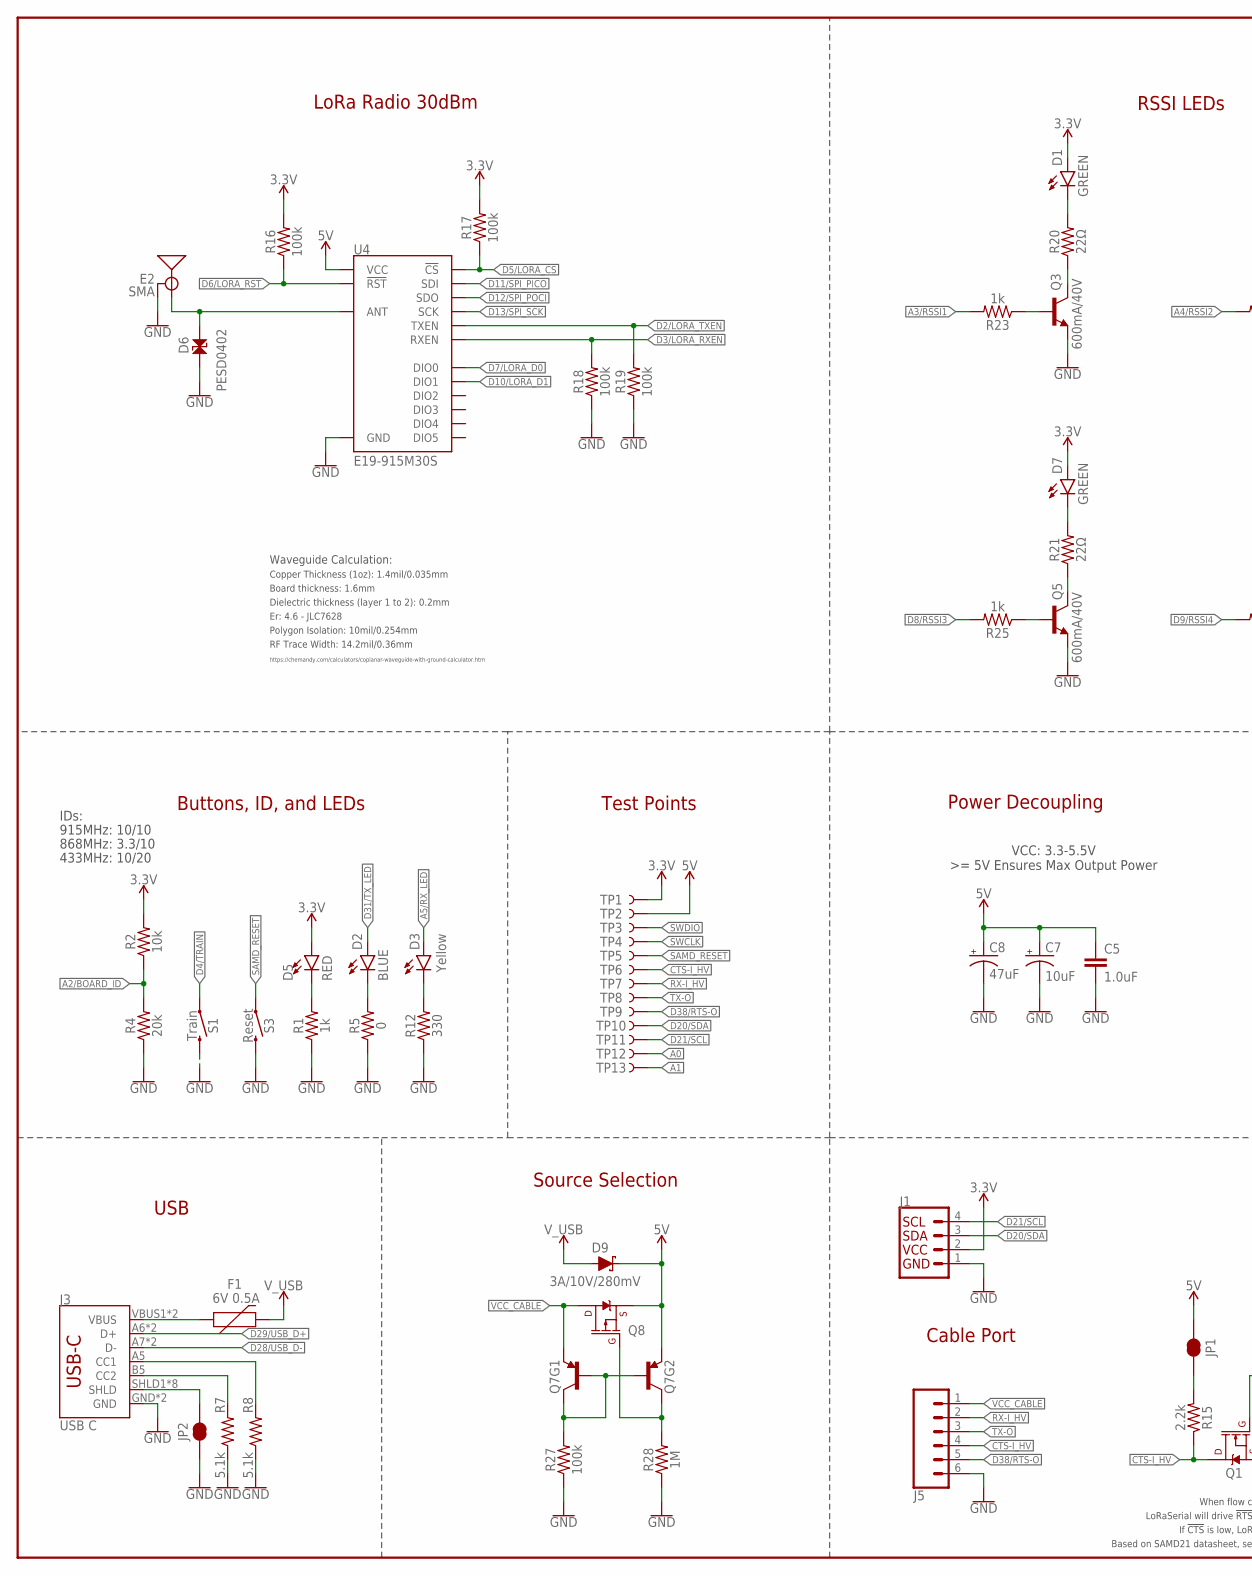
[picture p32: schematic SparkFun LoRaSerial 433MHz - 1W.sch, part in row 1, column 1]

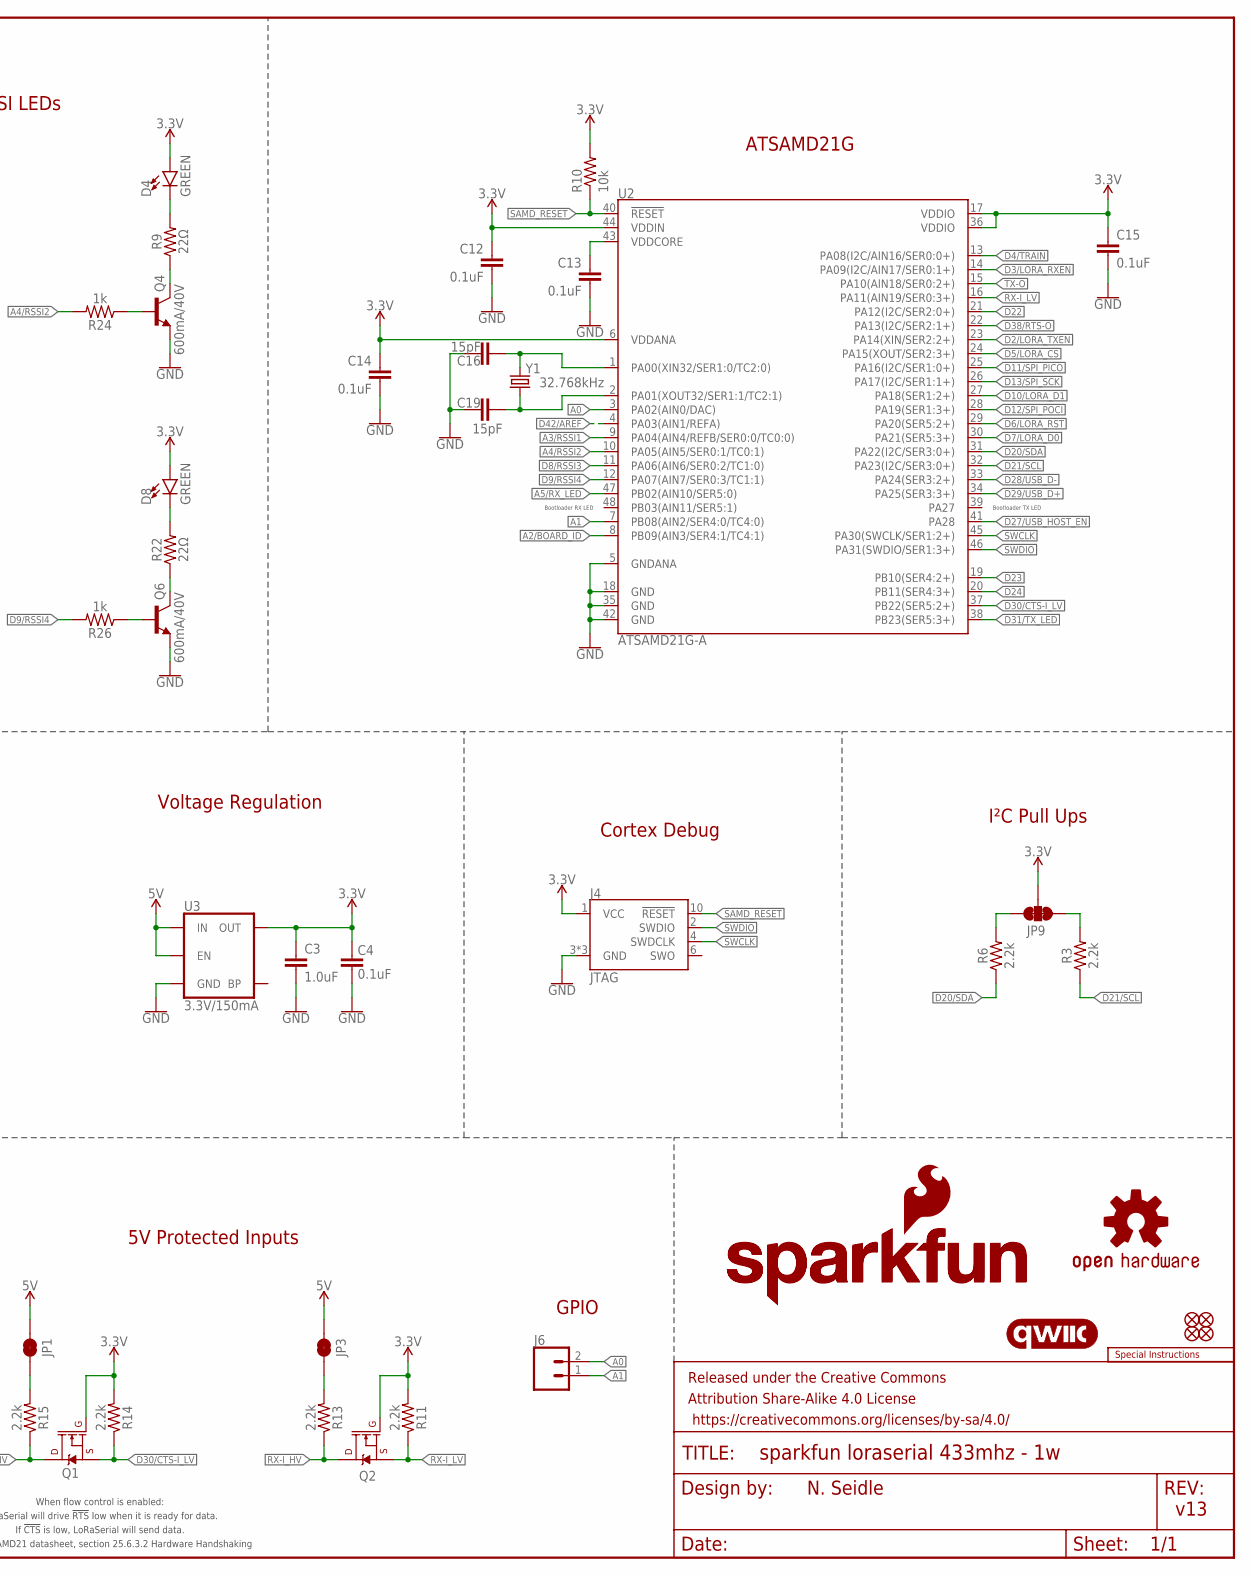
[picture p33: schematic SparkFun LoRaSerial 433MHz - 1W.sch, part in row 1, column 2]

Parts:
C3, C5: 1.0uF; 0603
C4, C12, C13, C14, C15: 0.1uF; 0603
C7: 10uF; EIA3216
C8: 47uF; EIA3528
C16, C19: 15pF; 0603
D1, D4, D7, D8: GREEN; LED-0603
D2: BLUE; LED-0603
D3: Yellow; LED-0603
D5: RED; LED-0603
D6: PESD0402; 0402-TIGHT
D9: 3A/10V/280mV; SOD-323
E2: SMA; SMA-EDGE
F1: 6V 0.5A; 0805
FID1, FID2, FID3, FID4: FIDUCIAL1X2; FIDUCIAL-1X2
FRAME3: FRAME-LEDGER; CREATIVE_COMMONS
J1: QWIIC_RIGHT_ANGLE; JST04_1MM_RA
J3: USB C; USB-C-16P
J4: JTAG; 2X5-PTH-1.27MM-NO_SILK
J5: CONN_06JST-SMD-LOCKING; JST-6-SMD-1.25MM-LOCKING
J6: CONN_021X02_NO_SILK; 1X02_NO_SILK
JP1, JP2, JP3: JUMPER-SMT_2_NC_TRACE_SILK; SMT-JUMPER_2_NC_TRACE_SILK
JP9: JUMPER-SMT_3_2-NC_TRACE_SILK; SMT-JUMPER_3_2-NC_TRACE_SILK
LOGO1: SPECIAL_INSTRUCTIONS-ORDERING; ORDERING_INSTRUCTIONS
LOGO2: SFE_LOGO_NAME_FLAME9_MM; SFE_LOGO_NAME_FLAME_9MM
LOGO3: QWIIC_LOGO_CONNECTOR; QWIIC_5.5MM
LOGO4: OSHW-LOGOMINI; OSHW-LOGO-MINI
LOGO5: SFE_LOGO_NAME9_MM; SFE_LOGO_NAME_9MM
Q1, Q2: 20V/0.2A/8MHz/1.2Ω/1Vth; SOT-416FL
Q3, Q4, Q5, Q6: 600mA/40V; SOT23-3
Q7: TRANS_PNP_DUALSOT-363; SOT363_PHILIPS
Q8: 20V/4.2A/52mΩ/1.4W; SOT23-3
R1, R23, R24, R25, R26: 1k; 0603
R2, R10: 10k; 0603
R3, R6, R11, R13, R14, R15: 2.2k; 0603
R4: 20k; 0603
R5: 0; 0603
R7, R8: 5.1k; 0603
R9, R20, R21, R22: 22Ω; 0603
R12: 330; 0603
R16, R17, R18, R19, R27: 100k; 0603
R28: 1M; 0603
S1: Train; TACTILE_SWITCH_SMD_RIGHT_ANGLE
S3: Reset; TACTILE_SWITCH_SMD_5.2MM
TP1, TP2, TP3, TP4, TP5, TP6, TP7, TP8, TP9, TP10, TP11, TP12, TP13: TEST-POINT3X5; PAD.03X.05
U2: ATSAMD21G-A; TQFP-48
U3: 3.3V/150mA; SOT23-5
U4: E19-915M30S; E19-433M30S
Y1: 32.768kHz; CRYSTAL-SMD-3.2X1.5MM

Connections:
3.3V: C3.1, C4.2, C12.1, C14.1, C15.1, D1.A, D4.A, D5.A, D7.A, D8.A, J1.2, J4.1 (VCC), JP9.2, Q1.1 (G), Q2.1 (G), R2.2, R10.2, R11.2, R14.2, R16.2, R17.2, TP1.1, U2.6 (VDDANA), U2.17 (VDDIO), U2.36 (VDDIO), U2.44 (VDDIN), U3.5 (OUT)
5V: C5.1, C7.+, C8.A (+), D9.C, JP1.2, JP3.2, Q7.4 (E), Q8.2 (S), TP2.1, U3.1 (IN), U3.3 (EN), U4.11 (VCC)
!CTS!-I_HV: J5.4, Q1.3 (D), R15.1, TP6.1
A0: J6.2, TP12.1, U2.3 (PA02(AIN0/DAC))
A1: J6.1, TP13.1, U2.7 (PB08(AIN2/SER4:0/TC4:0))
A2/BOARD_ID: R2.1, R4.2, U2.8 (PB09(AIN3/SER4:1/TC4:1))
A3/RSSI1: R23.2, U2.9 (PA04(AIN4/REFB/SER0:0/TC0:0))
A4/RSSI2: R24.2, U2.10 (PA05(AIN5/SER0:1/TC0:1))
A5/RX_LED: D3.A, U2.47 (PB02(AIN10/SER5:0))
CC1: J3.A5 (CC1), R8.2
CC2: J3.B5 (CC2), R7.2
D2/LORA_TXEN: R19.2, U2.23 (PA14(XIN/SER2:2+)), U4.16 (TXEN)
D3/LORA_RXEN: R18.2, U2.14 (PA09(I2C/AIN17/SER0:1+)), U4.17 (RXEN)
D4/TRAIN: S1.1, U2.13 (PA08(I2C/AIN16/SER0:0+))
D5/LORA_!CS!: R17.1, U2.24 (PA15(XOUT/SER2:3+)), U4.15 (!CS)
D6/LORA_!RST!: R16.1, U2.29 (PA20(SER5:2+)), U4.8 (!RST)
D7/LORA_D0: U2.30 (PA21(SER5:3+)), U4.7 (DIO0)
D8/RSSI3: R25.2, U2.11 (PA06(AIN6/SER0:2/TC1:0))
D9/RSSI4: R26.2, U2.12 (PA07(AIN7/SER0:3/TC1:1))
D10/LORA_D1: U2.27 (PA18(SER1:2+)), U4.6 (DIO1)
D11/SPI_PICO: U2.25 (PA16(I2C/SER1:0+)), U4.14 (SDI)
D12/SPI_POCI: U2.28 (PA19(SER1:3+)), U4.13 (SDO)
D13/SPI_SCK: U2.26 (PA17(I2C/SER1:1+)), U4.12 (SCK)
D20/SDA: J1.3, R6.1, TP10.1, U2.31 (PA22(I2C/SER3:0+))
D21/SCL: J1.4, R3.1, TP11.1, U2.32 (PA23(I2C/SER3:0+))
D22: U2.21 (PA12(I2C/SER2:0+))
D23: U2.19 (PB10(SER4:2+))
D24: U2.20 (PB11(SER4:3+))
D27/USB_HOST_EN: U2.41 (PA28)
D28/USB_D-: J3.A7 (D-), J3.B7 (D-), U2.33 (PA24(SER3:2+))
D29/USB_D+: J3.A6 (D+), J3.B6 (D+), U2.34 (PA25(SER3:3+))
D30/!CTS!-I_LV: Q1.2 (S), R14.1, U2.37 (PB22(SER5:2+))
D31/TX_LED: D2.A, U2.38 (PB23(SER5:3+))
D38/!RTS!-O: J5.5, TP9.1, U2.22 (PA13(I2C/SER2:1+))
D42/AREF: U2.4 (PA03(AIN1/REFA))
GND: C3.2, C4.1, C5.2, C7.-, C8.C (-), C12.2, C13.2, C14.2, C15.2, C16.1, C19.2, D6.1, E2.GND@0 (GND), E2.GND@1 (GND), E2.GND@2 (GND), E2.GND@3 (GND), J1.1, J3.GND, J3.GND2 (GND), J4.3 (GND), J4.5 (GND), J4.9 (GND), J5.6, JP2.1, Q3.2 (E), Q4.2 (E), Q5.2 (E), Q6.2 (E), R1.1, R4.1, R5.1, R7.1, R8.1, R12.1, R18.1, R19.1, R27.1, R28.1, S1.2, S3.3 (2), S3.4 (2), U2.5 (GNDANA), U2.18 (GND), U2.35 (GND), U2.42 (GND), U3.2 (GND), U4.1 (GND), U4.9 (GND), U4.10 (GND), U4.18 (GND), U4.20 (GND), U4.21 (GND), U4.22 (GND)
LORA_ANT: D6.2, E2.SIG (SIGNAL), U4.19 (ANT)
unnamed: C19.1, U2.2 (PA01(XOUT32/SER1:1/TC2:1)), Y1.P$1 (1)
unnamed: C16.2, U2.1 (PA00(XIN32/SER1:0/TC2:0)), Y1.P$2 (2)
unnamed: D3.C, R12.2
unnamed: D2.C, R5.2
unnamed: JP3.1, R13.2
unnamed: JP1.1, R15.2
unnamed: D5.C, R1.2
unnamed: D4.C, R9.2
unnamed: D1.C, R20.2
unnamed: D7.C, R21.2
unnamed: D8.C, R22.2
unnamed: Q3.3 (C), R20.1
unnamed: Q3.1 (B), R23.1
unnamed: Q4.3 (C), R9.1
unnamed: Q4.1 (B), R24.1
unnamed: Q5.3 (C), R21.1
unnamed: Q5.1 (B), R25.1
unnamed: Q6.3 (C), R22.1
unnamed: Q6.1 (B), R26.1
unnamed: J3.SHLD1 (SHLD), J3.SHLD2 (SHLD), J3.SHLD3 (SHLD), J3.SHLD4 (SHLD), J3.SHLD5 (SHLD), J3.SHLD6 (SHLD), J3.SHLD7 (SHLD), J3.SHLD8 (SHLD), JP2.2
unnamed: Q7.3 (C), Q8.1 (G), R28.2
unnamed: Q7.2 (B), Q7.5 (B), Q7.6 (C), R27.2
RX-I_HV: J5.2, Q2.3 (D), R13.1, TP7.1
RX-I_LV: Q2.2 (S), R11.1, U2.16 (PA11(AIN19/SER0:3+))
SAMD_!RESET!: J4.10 (!RESET), R10.1, S3.1, S3.2 (1), TP5.1, U2.40 (!RESET!)
SCL_PU1: JP9.1, R3.2
SDA_PU1: JP9.3, R6.2
SWCLK: J4.4 (SWDCLK), TP4.1, U2.45 (PA30(SWCLK/SER1:2+))
SWDIO: J4.2 (SWDIO), TP3.1, U2.46 (PA31(SWDIO/SER1:3+))
TX-O: J5.3, TP8.1, U2.15 (PA10(AIN18/SER0:2+))
VCC_CABLE: J5.1, Q7.1 (E), Q8.3 (D)
VDDCORE: C13.1, U2.43 (VDDCORE)
VUSB: F1.1, J3.VBUS1 (VBUS), J3.VBUS2 (VBUS)
V_USB: D9.A, F1.2

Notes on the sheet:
v13
Cable Port
Voltage Regulation
N. Seidle
LoRa Radio 30dBm
Power Decoupling
VCC: 3.3-5.5V >= 5V Ensures Max Output Power
Board thickness: 1.6mm
Er: 4.6 - JLC7628
Copper Thickness (1oz): 1.4mil/0.035mm
RF Trace Width: 14.2mil/0.36mm
Polygon Isolation: 10mil/0.254mm
Dielectric thickness (layer 1 to 2): 0.2mm
https://chemandy.com/calculators/coplanar-waveguide-with-ground-calculator.htm
Waveguide Calculation:
USB
ATSAMD21G
5V Protected Inputs
Cortex Debug
Bootloader TX LED
Bootloader RX LED
GPIO
Buttons, ID, and LEDs
I²C Pull Ups
RSSI LEDs
Test Points
Source Selection
IDs:
915MHz: 10/10
868MHz: 3.3/10
433MHz: 10/20
LoRaSerial will drive !RTS! low when it is ready for data.
If !CTS! is low, LoRaSerial will send data.
Based on SAMD21 datasheet, section 25.6.3.2 Hardware Handshaking
When flow control is enabled:

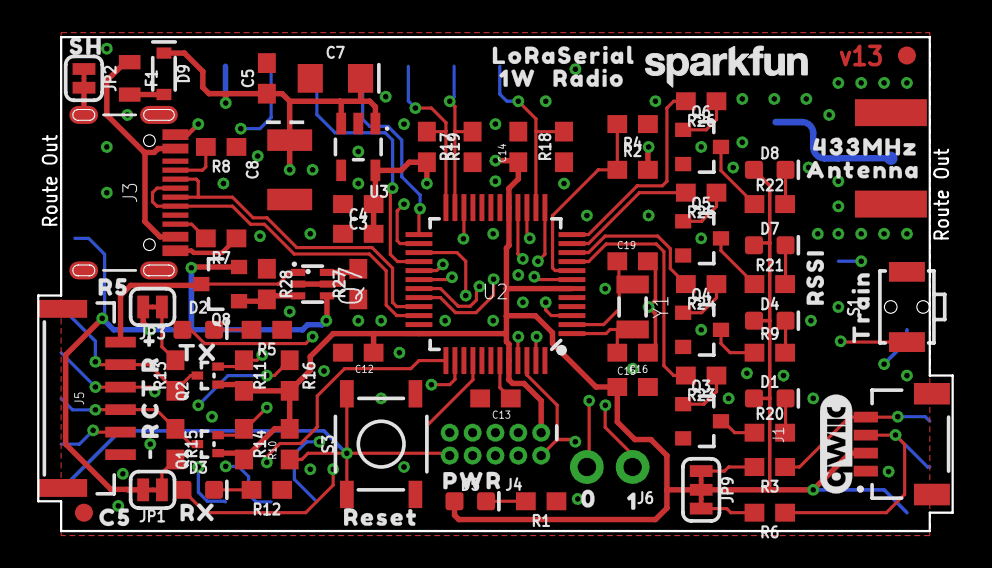
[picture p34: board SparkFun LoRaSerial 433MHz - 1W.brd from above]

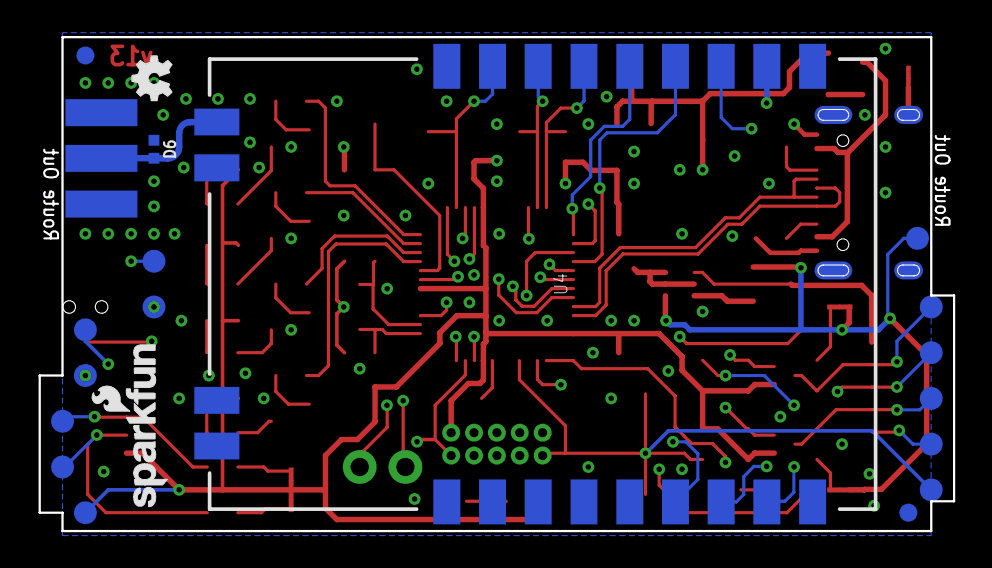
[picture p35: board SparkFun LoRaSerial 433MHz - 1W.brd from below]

Board: 4 copper layers, 50.8 x 27.4 mm, 118 parts (20 on the bottom side), 66 nets.

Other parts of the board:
U$1: 1W1
U$2: RESET0
U$4: TRAIN0
U$5: RADIO2
U$6: 01
U$7: PWR0
U$8: 433MHZ0
U$9: ANTENNA1
U$10: RX1
U$11: TX0
U$12: #0
U$13: #1
U$14: R3
U$15: T2
U$16: C0
U$17: R1
U$18: LORASERIAL0
U$19: C50
U$20: R50
U$21: RSSI0
U$22: 10
U$23: SH0

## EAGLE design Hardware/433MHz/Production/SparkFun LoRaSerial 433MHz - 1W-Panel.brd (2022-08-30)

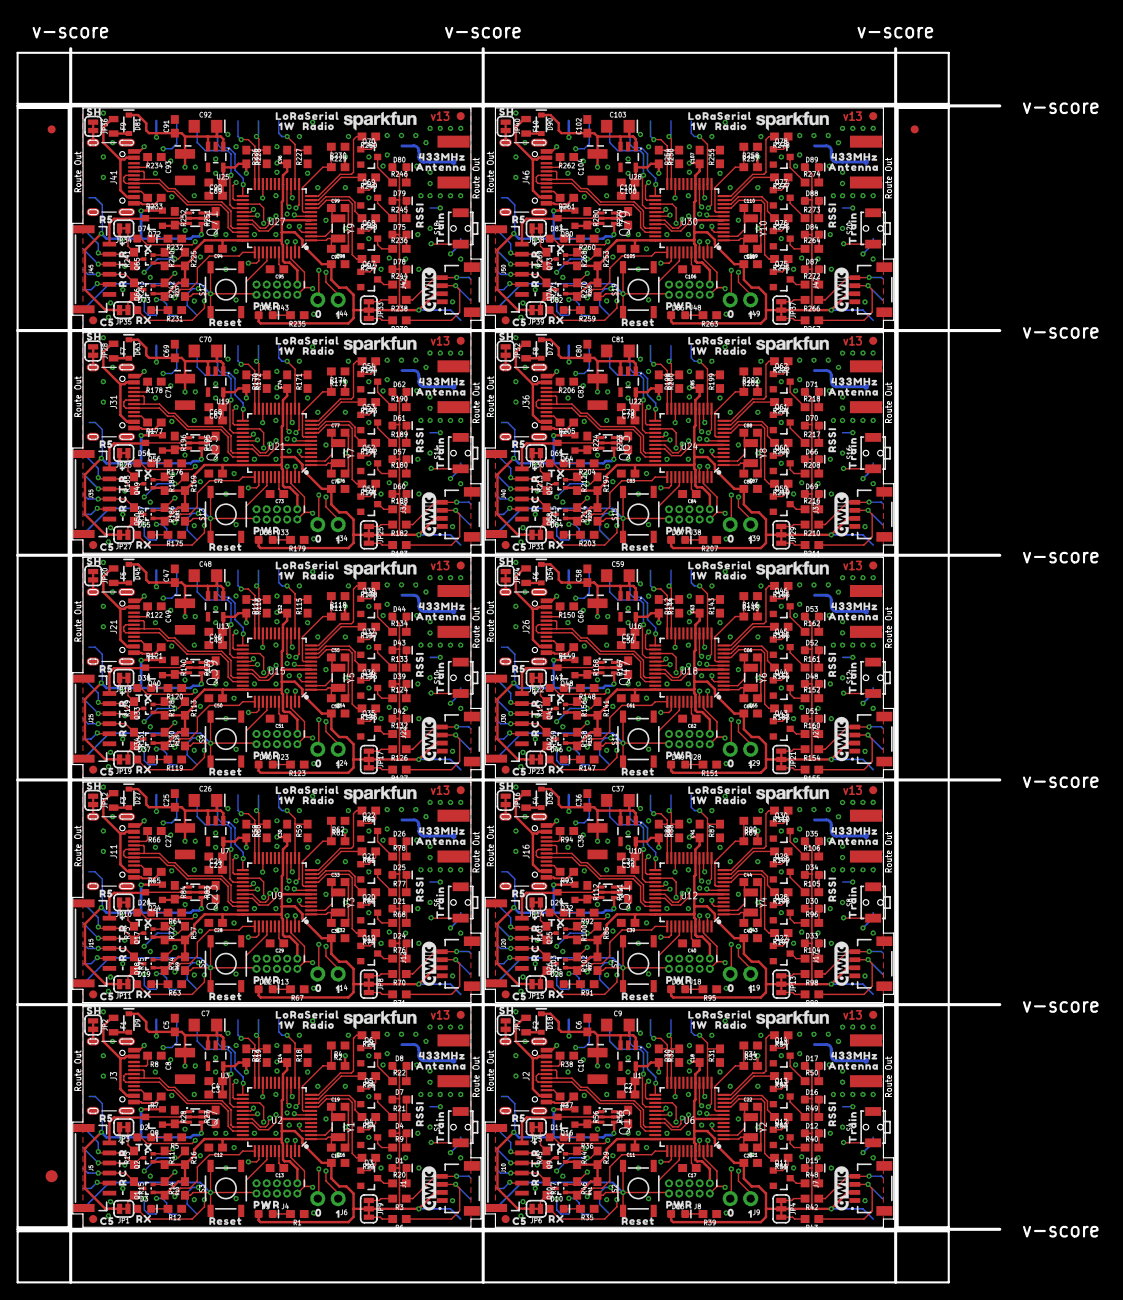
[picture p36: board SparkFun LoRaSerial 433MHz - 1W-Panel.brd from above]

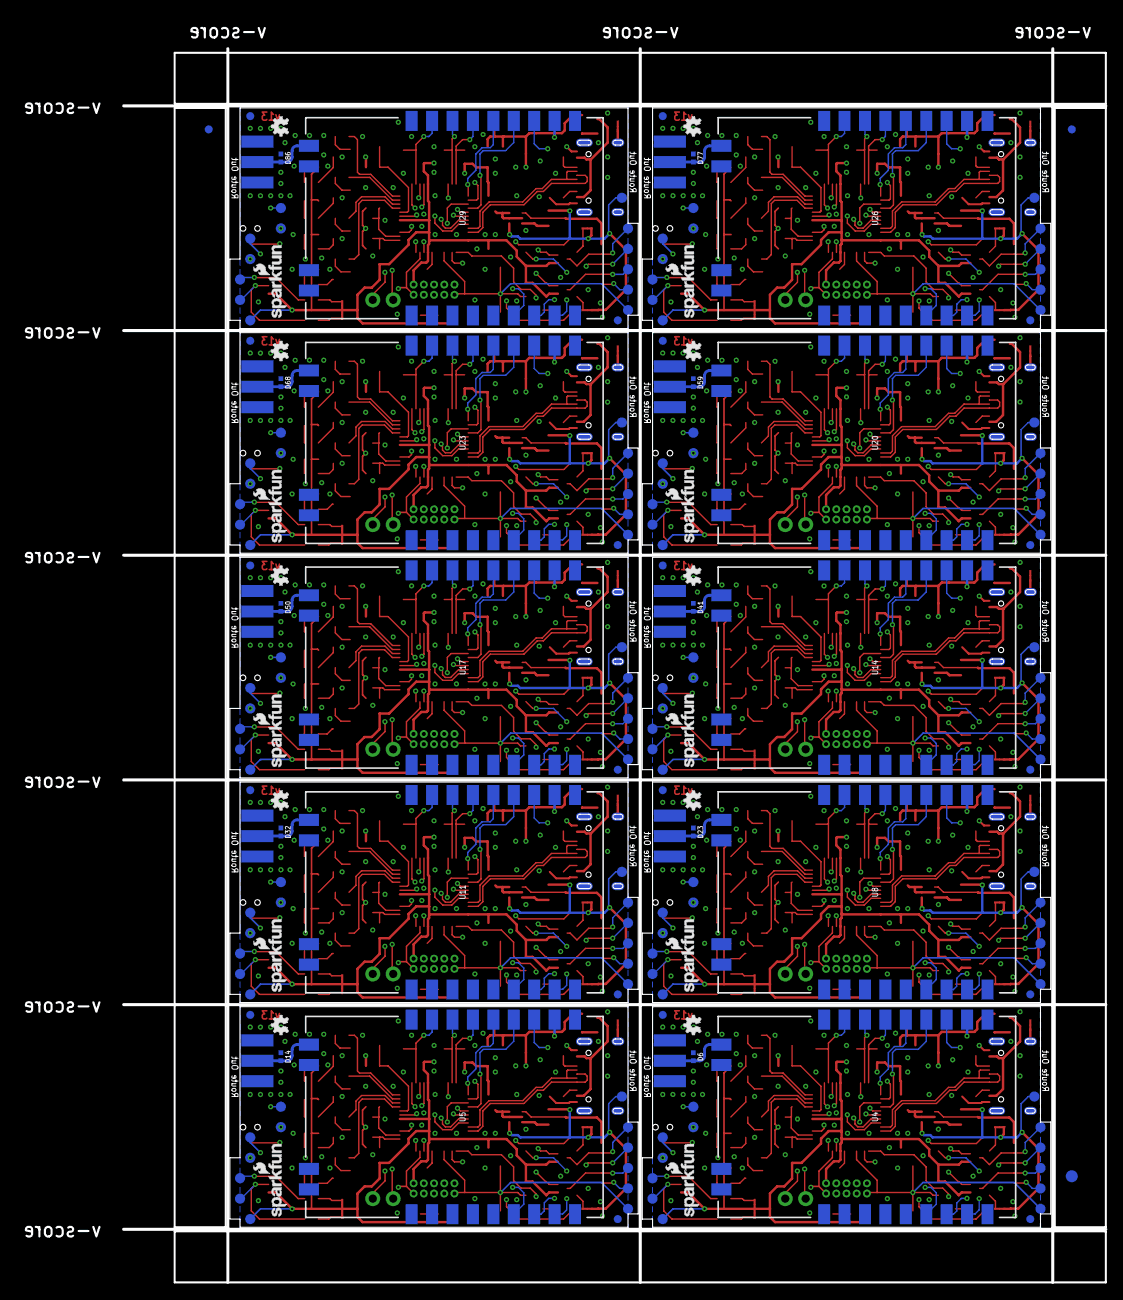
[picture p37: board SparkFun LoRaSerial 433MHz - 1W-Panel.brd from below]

Board: 4 copper layers, 122.2 x 153.5 mm, 1166 parts (203 on the bottom side), 660 nets.

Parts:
C1, C3, C5, C6, C23, C25, C34, C36, C45, C47, C56, C58, C67, C69, C78, C80, C89, C91, C100, C102: 1.0uF; 0603
C2, C4, C11, C12, C13, C14, C15, C17, C18, C20, C24, C28, C29, C30, C31, C35, C39, C40, C41, C42, C46, C50, C51, C52, C53, C57, C61, C62, C63, C64, C68, C72, C73, C74, C75, C79, C83, C84, C85, C86, C90, C94, C95, C96, C97, C101, C105, C106, C107, C108: 0.1uF; 0603
C7, C9, C26, C37, C48, C59, C70, C81, C92, C103: 10uF; EIA3216
C8, C10, C27, C38, C49, C60, C71, C82, C93, C104: 47uF; EIA3528
C16, C19, C21, C22, C32, C33, C43, C44, C54, C55, C65, C66, C76, C77, C87, C88, C98, C99, C109, C110: 15pF; 0603
D1, D4, D7, D8, D12, D15, D16, D17, D21, D24, D25, D26, D30, D33, D34, D35, D39, D42, D43, D44, D48, D51, D52, D53, D57, D60, D61, D62, D66, D69, D70, D71, D75, D78, D79, D80, D84, D87, D88, D89: GREEN; LED-0603
D2, D11, D20, D29, D38, D47, D56, D65, D74, D83: BLUE; LED-0603
D3, D10, D19, D28, D37, D46, D55, D64, D73, D82: Yellow; LED-0603
D5, D13, D22, D31, D40, D49, D58, D67, D76, D85: RED; LED-0603
D6, D14, D23, D32, D41, D50, D59, D68, D77, D86: PESD0402; 0402-TIGHT
D9, D18, D27, D36, D45, D54, D63, D72, D81, D90: 3A/10V/280mV; SOD-323
E1, E2, E3, E4, E5, E6, E7, E8, E9, E10: SMA; SMA-EDGE
E$1, E$2, E$3, E$4: FIDUCIAL-1X2
E$5, E$6: FIDUCIAL-1.5X3
F1, F2, F3, F4, F5, F6, F7, F8, F9, F10: 6V 0.5A; 0805
FID1, FID2, FID3, FID4, FID5, FID6, FID7, FID8, FID9, FID10, FID11, FID12, FID13, FID14, FID15, FID16, FID17, FID18, FID19, FID20, FID21, FID22, FID23, FID24, FID25, FID26, FID27, FID28, FID29, FID30, FID31, FID32, FID33, FID34, FID35, FID36, FID37, FID38, FID39, FID40: FIDUCIAL1X2; FIDUCIAL-1X2
J1, J7, J12, J17, J22, J27, J32, J37, J42, J47: QWIIC_RIGHT_ANGLE; JST04_1MM_RA
J2, J3, J11, J16, J21, J26, J31, J36, J41, J46: USB C; USB-C-16P
J4, J8, J13, J18, J23, J28, J33, J38, J43, J48: JTAG; 2X5-PTH-1.27MM-NO_SILK
J5, J10, J15, J20, J25, J30, J35, J40, J45, J50: JST-6-SMD-1.25MM-LOCKING
J6, J9, J14, J19, J24, J29, J34, J39, J44, J49: 1X02_NO_SILK
JP1, JP3, JP5, JP6, JP10, JP11, JP14, JP15, JP18, JP19, JP22, JP23, JP26, JP27, JP30, JP31, JP34, JP35, JP38, JP39: JUMPER-SMT_2_NC_TRACE_SILK; SMT-JUMPER_2_NC_TRACE_SILK
JP2, JP7, JP12, JP16, JP20, JP24, JP28, JP32, JP36, JP40: SMT-JUMPER_2_NC_TRACE_SILK
JP4, JP8, JP9, JP13, JP17, JP21, JP25, JP29, JP33, JP37: JUMPER-SMT_3_2-NC_TRACE_SILK; SMT-JUMPER_3_2-NC_TRACE_SILK
LOGO1, LOGO5, LOGO9, LOGO13, LOGO17, LOGO21, LOGO25, LOGO29, LOGO33, LOGO37: SFE_LOGO_NAME9_MM; SFE_LOGO_NAME_9MM
LOGO2, LOGO6, LOGO10, LOGO14, LOGO18, LOGO22, LOGO26, LOGO30, LOGO34, LOGO38: SFE_LOGO_NAME_FLAME9_MM; SFE_LOGO_NAME_FLAME_9MM
LOGO3, LOGO8, LOGO12, LOGO16, LOGO20, LOGO24, LOGO28, LOGO32, LOGO36, LOGO40: QWIIC_LOGO_CONNECTOR; QWIIC_5.5MM
LOGO4, LOGO7, LOGO11, LOGO15, LOGO19, LOGO23, LOGO27, LOGO31, LOGO35, LOGO39: OSHW-LOGOMINI; OSHW-LOGO-MINI
Q1, Q2, Q9, Q10, Q17, Q18, Q25, Q26, Q33, Q34, Q41, Q42, Q49, Q50, Q57, Q58, Q65, Q66, Q73, Q74: 20V/0.2A/8MHz/1.2Ω/1Vth; SOT-416FL
Q3, Q4, Q5, Q6, Q11, Q12, Q13, Q14, Q19, Q20, Q21, Q22, Q27, Q28, Q29, Q30, Q35, Q36, Q37, Q38, Q43, Q44, Q45, Q46, Q51, Q52, Q53, Q54, Q59, Q60, Q61, Q62, Q67, Q68, Q69, Q70, Q75, Q76, Q77, Q78: 600mA/40V; SOT23-3
Q7, Q15, Q23, Q31, Q39, Q47, Q55, Q63, Q71, Q79: SOT363_PHILIPS
Q8, Q16, Q24, Q32, Q40, Q48, Q56, Q64, Q72, Q80: 20V/4.2A/52mΩ/1.4W; SOT23-3
R1, R23, R24, R25, R26, R39, R51, R52, R53, R54, R67, R79, R80, R81, R82, R95, R107, R108, R109, R110, R123, R135, R136, R137, R138, R151, R163, R164, R165, R166, R179, R191, R192, R193, R194, R207, R219, R220, R221, R222, R235, R247, R248, R249, R250, R263, R275, R276, R277, R278: 1k; 0603
R2, R10, R33, R41, R61, R69, R89, R97, R117, R125, R145, R153, R173, R181, R201, R209, R229, R237, R257, R265: 10k; 0603
R3, R6, R11, R13, R14, R15, R42, R43, R44, R45, R46, R47, R70, R71, R72, R73, R74, R75, R98, R99, R100, R101, R102, R103, R126, R127, R128, R129, R130, R131, R154, R155, R156, R157, R158, R159, R182, R183, R184, R185, R186, R187, R210, R211, R212, R213, R214, R215, R238, R239, R240, R241, R242, R243, R266, R267, R268, R269, R270, R271: 2.2k; 0603
R4, R34, R62, R90, R118, R146, R174, R202, R230, R258: 20k; 0603
R5, R36, R64, R92, R120, R148, R176, R204, R232, R260: 0; 0603
R7, R8, R37, R38, R65, R66, R93, R94, R121, R122, R149, R150, R177, R178, R205, R206, R233, R234, R261, R262: 5.1k; 0603
R9, R20, R21, R22, R40, R48, R49, R50, R68, R76, R77, R78, R96, R104, R105, R106, R124, R132, R133, R134, R152, R160, R161, R162, R180, R188, R189, R190, R208, R216, R217, R218, R236, R244, R245, R246, R264, R272, R273, R274: 22Ω; 0603
R12, R35, R63, R91, R119, R147, R175, R203, R231, R259: 330; 0603
R16, R17, R18, R19, R27, R29, R30, R31, R32, R55, R57, R58, R59, R60, R83, R85, R86, R87, R88, R111, R113, R114, R115, R116, R139, R141, R142, R143, R144, R167, R169, R170, R171, R172, R195, R197, R198, R199, R200, R223, R225, R226, R227, R228, R251, R253, R254, R255, R256, R279: 100k; 0603
R28, R56, R84, R112, R140, R168, R196, R224, R252, R280: 1M; 0603
S1, S4, S6, S8, S10, S12, S14, S16, S18, S20: Train; TACTILE_SWITCH_SMD_RIGHT_ANGLE
S2, S3, S5, S7, S9, S11, S13, S15, S17, S19: Reset; TACTILE_SWITCH_SMD_5.2MM
TP1, TP2, TP3, TP4, TP5, TP6, TP7, TP8, TP9, TP10, TP11, TP12, TP13, TP14, TP15, TP16, TP17, TP18, TP19, TP20, TP21, TP22, TP23, TP24, TP25, TP26, TP27, TP28, TP29, TP30, TP31, TP32, TP33, TP34, TP35, TP36, TP37, TP38, TP39, TP40, TP41, TP42, TP43, TP44, TP45, TP46, TP47, TP48, TP49, TP50, TP51, TP52, TP53, TP54, TP55, TP56, TP57, TP58, TP59, TP60, TP61, TP62, TP63, TP64, TP65, TP66, TP67, TP68, TP69, TP70, TP71, TP72, TP73, TP74, TP75, TP76, TP77, TP78, TP79, TP80, TP81, TP82, TP83, TP84, TP85, TP86, TP87, TP88, TP89, TP90, TP91, TP92, TP93, TP94, TP95, TP96, TP97, TP98, TP99, TP100, TP101, TP102, TP103, TP104, TP105, TP106, TP107, TP108, TP109, TP110, TP111, TP112, TP113, TP114, TP115, TP116, TP117, TP118, TP119, TP120, TP121, TP122, TP123, TP124, TP125, TP126, TP127, TP128, TP129, TP130: PAD.03X.05
U1, U3, U7, U10, U13, U16, U19, U22, U25, U28: 3.3V/150mA; SOT23-5
U2, U6, U9, U12, U15, U18, U21, U24, U27, U30: ATSAMD21G-A; TQFP-48
U4, U5, U8, U11, U14, U17, U20, U23, U26, U29: E19-915M30S; E19-433M30S
U$1, U$35, U$57, U$79, U$101, U$123, U$145, U$167, U$189, U$211: 1W1
U$2, U$3, U$45, U$67, U$89, U$111, U$133, U$155, U$177, U$199: RESET0
U$4, U$36, U$58, U$80, U$102, U$124, U$146, U$168, U$190, U$212: TRAIN0
U$5, U$25, U$47, U$69, U$91, U$113, U$135, U$157, U$179, U$201: RADIO2
U$6, U$41, U$63, U$85, U$107, U$129, U$151, U$173, U$195, U$217: 01
U$7, U$40, U$62, U$84, U$106, U$128, U$150, U$172, U$194, U$216: PWR0
U$8, U$44, U$66, U$88, U$110, U$132, U$154, U$176, U$198, U$220: 433MHZ0
U$9, U$24, U$46, U$68, U$90, U$112, U$134, U$156, U$178, U$200: ANTENNA1
U$10, U$26, U$48, U$70, U$92, U$114, U$136, U$158, U$180, U$202: RX1
U$11, U$27, U$49, U$71, U$93, U$115, U$137, U$159, U$181, U$203: TX0
U$12, U$28, U$50, U$72, U$94, U$116, U$138, U$160, U$182, U$204: #0
U$13, U$29, U$51, U$73, U$95, U$117, U$139, U$161, U$183, U$205: #1
U$14, U$30, U$52, U$74, U$96, U$118, U$140, U$162, U$184, U$206: R3
U$15, U$31, U$53, U$75, U$97, U$119, U$141, U$163, U$185, U$207: T2
U$16, U$32, U$54, U$76, U$98, U$120, U$142, U$164, U$186, U$208: C0
U$17, U$33, U$55, U$77, U$99, U$121, U$143, U$165, U$187, U$209: R1
U$18, U$34, U$56, U$78, U$100, U$122, U$144, U$166, U$188, U$210: LORASERIAL0
U$19, U$37, U$59, U$81, U$103, U$125, U$147, U$169, U$191, U$213: C50
U$20, U$38, U$60, U$82, U$104, U$126, U$148, U$170, U$192, U$214: R50
U$21, U$39, U$61, U$83, U$105, U$127, U$149, U$171, U$193, U$215: RSSI0
U$22, U$42, U$64, U$86, U$108, U$130, U$152, U$174, U$196, U$218: 10
U$23, U$43, U$65, U$87, U$109, U$131, U$153, U$175, U$197, U$219: SH0
Y1, Y2, Y3, Y4, Y5, Y6, Y7, Y8, Y9, Y10: 32.768kHz; CRYSTAL-SMD-3.2X1.5MM

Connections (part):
3.3V: C3.1, C4.2, C12.1, C14.1, C15.1, D1.A, D4.A, D5.A, D7.A, D8.A, J1.2, J4.1, JP9.2, Q1.1, Q2.1, R2.2, R10.2, R11.2, R14.2, R16.2, R17.2, TP1.1, U2.6, U2.17, U2.36, U2.44, U3.5
3.3V1: C1.1, C2.2, C11.1, C18.1, C20.1, D12.A, D13.A, D15.A, D16.A, D17.A, J7.2, J8.1, JP4.2, Q9.1, Q10.1, R29.2, R30.2, R33.2, R41.2, R44.2, R46.2, TP14.1, U1.5, U6.6, U6.17, U6.36, U6.44
3.3V2: C23.1, C24.2, C28.1, C30.1, C31.1, D21.A, D22.A, D24.A, D25.A, D26.A, J12.2, J13.1, JP8.2, Q17.1, Q18.1, R57.2, R58.2, R61.2, R69.2, R72.2, R74.2, TP27.1, U7.5, U9.6, U9.17, U9.36, U9.44
3.3V3: C34.1, C35.2, C39.1, C41.1, C42.1, D30.A, D31.A, D33.A, D34.A, D35.A, J17.2, J18.1, JP13.2, Q25.1, Q26.1, R85.2, R86.2, R89.2, R97.2, R100.2, R102.2, TP40.1, U10.5, U12.6, U12.17, U12.36, U12.44
3.3V4: C45.1, C46.2, C50.1, C52.1, C53.1, D39.A, D40.A, D42.A, D43.A, D44.A, J22.2, J23.1, JP17.2, Q33.1, Q34.1, R113.2, R114.2, R117.2, R125.2, R128.2, R130.2, TP53.1, U13.5, U15.6, U15.17, U15.36, U15.44
3.3V5: C56.1, C57.2, C61.1, C63.1, C64.1, D48.A, D49.A, D51.A, D52.A, D53.A, J27.2, J28.1, JP21.2, Q41.1, Q42.1, R141.2, R142.2, R145.2, R153.2, R156.2, R158.2, TP66.1, U16.5, U18.6, U18.17, U18.36, U18.44
3.3V6: C67.1, C68.2, C72.1, C74.1, C75.1, D57.A, D58.A, D60.A, D61.A, D62.A, J32.2, J33.1, JP25.2, Q49.1, Q50.1, R169.2, R170.2, R173.2, R181.2, R184.2, R186.2, TP79.1, U19.5, U21.6, U21.17, U21.36, U21.44
3.3V7: C78.1, C79.2, C83.1, C85.1, C86.1, D66.A, D67.A, D69.A, D70.A, D71.A, J37.2, J38.1, JP29.2, Q57.1, Q58.1, R197.2, R198.2, R201.2, R209.2, R212.2, R214.2, TP92.1, U22.5, U24.6, U24.17, U24.36, U24.44
3.3V8: C89.1, C90.2, C94.1, C96.1, C97.1, D75.A, D76.A, D78.A, D79.A, D80.A, J42.2, J43.1, JP33.2, Q65.1, Q66.1, R225.2, R226.2, R229.2, R237.2, R240.2, R242.2, TP105.1, U25.5, U27.6, U27.17, U27.36, U27.44
3.3V9: C100.1, C101.2, C105.1, C107.1, C108.1, D84.A, D85.A, D87.A, D88.A, D89.A, J47.2, J48.1, JP37.2, Q73.1, Q74.1, R253.2, R254.2, R257.2, R265.2, R268.2, R270.2, TP118.1, U28.5, U30.6, U30.17, U30.36, U30.44
5V: C5.1, C7.+, C8.A, D9.C, JP1.2, JP3.2, Q7.4, Q8.2, TP2.1, U3.1, U3.3, U4.11
5V1: C6.1, C9.+, C10.A, D18.C, JP5.2, JP6.2, Q15.4, Q16.2, TP15.1, U1.1, U1.3, U5.11
5V2: C25.1, C26.+, C27.A, D27.C, JP10.2, JP11.2, Q23.4, Q24.2, TP28.1, U7.1, U7.3, U8.11
5V3: C36.1, C37.+, C38.A, D36.C, JP14.2, JP15.2, Q31.4, Q32.2, TP41.1, U10.1, U10.3, U11.11
5V4: C47.1, C48.+, C49.A, D45.C, JP18.2, JP19.2, Q39.4, Q40.2, TP54.1, U13.1, U13.3, U14.11
5V5: C58.1, C59.+, C60.A, D54.C, JP22.2, JP23.2, Q47.4, Q48.2, TP67.1, U16.1, U16.3, U17.11
5V6: C69.1, C70.+, C71.A, D63.C, JP26.2, JP27.2, Q55.4, Q56.2, TP80.1, U19.1, U19.3, U20.11
5V7: C80.1, C81.+, C82.A, D72.C, JP30.2, JP31.2, Q63.4, Q64.2, TP93.1, U22.1, U22.3, U23.11
5V8: C91.1, C92.+, C93.A, D81.C, JP34.2, JP35.2, Q71.4, Q72.2, TP106.1, U25.1, U25.3, U26.11
5V9: C102.1, C103.+, C104.A, D90.C, JP38.2, JP39.2, Q79.4, Q80.2, TP119.1, U28.1, U28.3, U29.11
A0: J6.2, TP12.1, U2.3
A1: J6.1, TP13.1, U2.7
A2: J9.1, TP26.1, U6.7
A2/BOARD_ID: R2.1, R4.2, U2.8
A2/BOARD_ID1: R33.1, R34.2, U6.8
A2/BOARD_ID2: R61.1, R62.2, U9.8
A2/BOARD_ID3: R89.1, R90.2, U12.8
A2/BOARD_ID4: R117.1, R118.2, U15.8
A2/BOARD_ID5: R145.1, R146.2, U18.8
A2/BOARD_ID6: R173.1, R174.2, U21.8
A2/BOARD_ID7: R201.1, R202.2, U24.8
A2/BOARD_ID8: R229.1, R230.2, U27.8
A2/BOARD_ID9: R257.1, R258.2, U30.8
A3: J9.2, TP25.1, U6.3
A3/RSSI1: R23.2, U2.9
A3/RSSI2: R51.2, U6.9
A3/RSSI3: R79.2, U9.9
A3/RSSI4: R107.2, U12.9
A3/RSSI5: R135.2, U15.9
A3/RSSI6: R163.2, U18.9
A3/RSSI7: R191.2, U21.9
A3/RSSI8: R219.2, U24.9
A3/RSSI9: R247.2, U27.9
A3/RSSI10: R275.2, U30.9
A4: J14.1, TP39.1, U9.7
A4/RSSI1: R52.2, U6.10
A4/RSSI2: R24.2, U2.10
A4/RSSI3: R80.2, U9.10
A4/RSSI4: R108.2, U12.10
A4/RSSI5: R136.2, U15.10
A4/RSSI6: R164.2, U18.10
A4/RSSI7: R192.2, U21.10
A4/RSSI8: R220.2, U24.10
A4/RSSI9: R248.2, U27.10
A4/RSSI10: R276.2, U30.10
A5: J14.2, TP38.1, U9.3
A5/RX_LED: D3.A, U2.47
A5/RX_LED1: D10.A, U6.47
A5/RX_LED2: D19.A, U9.47
A5/RX_LED3: D28.A, U12.47
A5/RX_LED4: D37.A, U15.47
A5/RX_LED5: D46.A, U18.47
A5/RX_LED6: D55.A, U21.47
A5/RX_LED7: D64.A, U24.47
A5/RX_LED8: D73.A, U27.47
A5/RX_LED9: D82.A, U30.47
A6: J19.1, TP52.1, U12.7
A7: J19.2, TP51.1, U12.3
A8: J24.1, TP65.1, U15.7
A9: J24.2, TP64.1, U15.3
A10: J29.1, TP78.1, U18.7
A11: J29.2, TP77.1, U18.3
A12: J34.1, TP91.1, U21.7
A13: J34.2, TP90.1, U21.3
A14: J39.1, TP104.1, U24.7
A15: J39.2, TP103.1, U24.3
A16: J44.1, TP117.1, U27.7
A17: J44.2, TP116.1, U27.3
A18: J49.1, TP130.1, U30.7
A19: J49.2, TP129.1, U30.3
CC1: J3.A5, R8.2
CC2: J3.B5, R7.2
CC3: J2.B5, R37.2
CC4: J2.A5, R38.2
CC5: J11.B5, R65.2
CC6: J11.A5, R66.2
CC7: J16.B5, R93.2
CC8: J16.A5, R94.2
CC9: J21.B5, R121.2
CC10: J21.A5, R122.2
CC11: J26.B5, R149.2
CC12: J26.A5, R150.2
CC13: J31.B5, R177.2
CC14: J31.A5, R178.2
CC15: J36.B5, R205.2
CC16: J36.A5, R206.2
CC17: J41.B5, R233.2
CC18: J41.A5, R234.2
CC19: J46.B5, R261.2
CC20: J46.A5, R262.2
CTS-I_HV: J5.4, Q1.3, R15.1, TP6.1
CTS-I_HV1: J10.4, Q10.3, R47.1, TP19.1
CTS-I_HV2: J15.4, Q18.3, R75.1, TP32.1
CTS-I_HV3: J20.4, Q26.3, R103.1, TP45.1
CTS-I_HV4: J25.4, Q34.3, R131.1, TP58.1
CTS-I_HV5: J30.4, Q42.3, R159.1, TP71.1
CTS-I_HV6: J35.4, Q50.3, R187.1, TP84.1
CTS-I_HV7: J40.4, Q58.3, R215.1, TP97.1
CTS-I_HV8: J45.4, Q66.3, R243.1, TP110.1
CTS-I_HV9: J50.4, Q74.3, R271.1, TP123.1
D2/LORA_TXEN: R19.2, U2.23, U4.16
D2/LORA_TXEN1: R32.2, U5.16, U6.23
D2/LORA_TXEN2: R60.2, U8.16, U9.23
D2/LORA_TXEN3: R88.2, U11.16, U12.23
D2/LORA_TXEN4: R116.2, U14.16, U15.23
D2/LORA_TXEN5: R144.2, U17.16, U18.23
D2/LORA_TXEN6: R172.2, U20.16, U21.23
D2/LORA_TXEN7: R200.2, U23.16, U24.23
D2/LORA_TXEN8: R228.2, U26.16, U27.23
D2/LORA_TXEN9: R256.2, U29.16, U30.23
D3/LORA_RXEN: R18.2, U2.14, U4.17
D3/LORA_RXEN1: R31.2, U5.17, U6.14
D3/LORA_RXEN2: R59.2, U8.17, U9.14
D3/LORA_RXEN3: R87.2, U11.17, U12.14
D3/LORA_RXEN4: R115.2, U14.17, U15.14
D3/LORA_RXEN5: R143.2, U17.17, U18.14
D3/LORA_RXEN6: R171.2, U20.17, U21.14
D3/LORA_RXEN7: R199.2, U23.17, U24.14
D3/LORA_RXEN8: R227.2, U26.17, U27.14
D3/LORA_RXEN9: R255.2, U29.17, U30.14
D4/TRAIN: S1.1, U2.13
D4/TRAIN1: S4.1, U6.13
D4/TRAIN2: S6.1, U9.13
D4/TRAIN3: S8.1, U12.13
D4/TRAIN4: S10.1, U15.13
D4/TRAIN5: S12.1, U18.13
D4/TRAIN6: S14.1, U21.13
D4/TRAIN7: S16.1, U24.13
D4/TRAIN8: S18.1, U27.13
D4/TRAIN9: S20.1, U30.13
D5/LORA_!CS!: R17.1, U2.24, U4.15
D5/LORA_!CS!1: R30.1, U5.15, U6.24
D5/LORA_!CS!2: R58.1, U8.15, U9.24
D5/LORA_!CS!3: R86.1, U11.15, U12.24
D5/LORA_!CS!4: R114.1, U14.15, U15.24
D5/LORA_!CS!5: R142.1, U17.15, U18.24
D5/LORA_!CS!6: R170.1, U20.15, U21.24
D5/LORA_!CS!7: R198.1, U23.15, U24.24
D5/LORA_!CS!8: R226.1, U26.15, U27.24
D5/LORA_!CS!9: R254.1, U29.15, U30.24
D6/LORA_!RST!: R16.1, U2.29, U4.8
D6/LORA_!RST!1: R29.1, U5.8, U6.29
D6/LORA_!RST!2: R57.1, U8.8, U9.29
D6/LORA_!RST!3: R85.1, U11.8, U12.29
D6/LORA_!RST!4: R113.1, U14.8, U15.29
D6/LORA_!RST!5: R141.1, U17.8, U18.29
D6/LORA_!RST!6: R169.1, U20.8, U21.29
D6/LORA_!RST!7: R197.1, U23.8, U24.29
D6/LORA_!RST!8: R225.1, U26.8, U27.29
D6/LORA_!RST!9: R253.1, U29.8, U30.29
D7/LORA_D0: U2.30, U4.7
D7/LORA_D1: U5.7, U6.30
D7/LORA_D2: U8.7, U9.30
D7/LORA_D3: U11.7, U12.30
D7/LORA_D4: U14.7, U15.30
D7/LORA_D5: U17.7, U18.30
D7/LORA_D6: U20.7, U21.30
D7/LORA_D7: U23.7, U24.30
D7/LORA_D8: U26.7, U27.30
D7/LORA_D9: U29.7, U30.30
D8/RSSI1: R53.2, U6.11
D8/RSSI2: R81.2, U9.11
D8/RSSI3: R25.2, U2.11
D8/RSSI4: R109.2, U12.11
D8/RSSI5: R137.2, U15.11
D8/RSSI6: R165.2, U18.11
D8/RSSI7: R193.2, U21.11
D8/RSSI8: R221.2, U24.11
D8/RSSI9: R249.2, U27.11
D8/RSSI10: R277.2, U30.11
D9/RSSI1: R54.2, U6.12
D9/RSSI2: R82.2, U9.12
D9/RSSI3: R110.2, U12.12
D9/RSSI4: R26.2, U2.12
D9/RSSI5: R138.2, U15.12
D9/RSSI6: R166.2, U18.12
D9/RSSI7: R194.2, U21.12
D9/RSSI8: R222.2, U24.12
D9/RSSI9: R250.2, U27.12
D9/RSSI10: R278.2, U30.12
D10/LORA_D1: U2.27, U4.6
D10/LORA_D2: U5.6, U6.27
D10/LORA_D3: U8.6, U9.27
D10/LORA_D4: U11.6, U12.27
D10/LORA_D5: U14.6, U15.27
D10/LORA_D6: U17.6, U18.27
D10/LORA_D7: U20.6, U21.27
D10/LORA_D8: U23.6, U24.27
D10/LORA_D9: U26.6, U27.27
D10/LORA_D10: U29.6, U30.27
D11/SPI_PICO: U2.25, U4.14
D11/SPI_PICO1: U5.14, U6.25
D11/SPI_PICO2: U8.14, U9.25
D11/SPI_PICO3: U11.14, U12.25
D11/SPI_PICO4: U14.14, U15.25
D11/SPI_PICO5: U17.14, U18.25
D11/SPI_PICO6: U20.14, U21.25
D11/SPI_PICO7: U23.14, U24.25
D11/SPI_PICO8: U26.14, U27.25
D11/SPI_PICO9: U29.14, U30.25
D12/SPI_POCI: U2.28, U4.13
D12/SPI_POCI1: U5.13, U6.28
D12/SPI_POCI2: U8.13, U9.28
D12/SPI_POCI3: U11.13, U12.28
D12/SPI_POCI4: U14.13, U15.28
D12/SPI_POCI5: U17.13, U18.28
D12/SPI_POCI6: U20.13, U21.28
D12/SPI_POCI7: U23.13, U24.28
D12/SPI_POCI8: U26.13, U27.28
D12/SPI_POCI9: U29.13, U30.28
D13/SPI_SCK: U2.26, U4.12
D13/SPI_SCK1: U5.12, U6.26
D13/SPI_SCK2: U8.12, U9.26
D13/SPI_SCK3: U11.12, U12.26
D13/SPI_SCK4: U14.12, U15.26
D13/SPI_SCK5: U17.12, U18.26
D13/SPI_SCK6: U20.12, U21.26
D13/SPI_SCK7: U23.12, U24.26
D13/SPI_SCK8: U26.12, U27.26
D13/SPI_SCK9: U29.12, U30.26
D20/SDA: J1.3, R6.1, TP10.1, U2.31
D20/SDA1: J7.3, R43.1, TP23.1, U6.31
D20/SDA2: J12.3, R71.1, TP36.1, U9.31
D20/SDA3: J17.3, R99.1, TP49.1, U12.31
D20/SDA4: J22.3, R127.1, TP62.1, U15.31
D20/SDA5: J27.3, R155.1, TP75.1, U18.31
D20/SDA6: J32.3, R183.1, TP88.1, U21.31
D20/SDA7: J37.3, R211.1, TP101.1, U24.31
D20/SDA8: J42.3, R239.1, TP114.1, U27.31
D20/SDA9: J47.3, R267.1, TP127.1, U30.31
D21/SCL: J1.4, R3.1, TP11.1, U2.32
D21/SCL1: J7.4, R42.1, TP24.1, U6.32
D21/SCL2: J12.4, R70.1, TP37.1, U9.32
D21/SCL3: J17.4, R98.1, TP50.1, U12.32
D21/SCL4: J22.4, R126.1, TP63.1, U15.32
D21/SCL5: J27.4, R154.1, TP76.1, U18.32
D21/SCL6: J32.4, R182.1, TP89.1, U21.32
D21/SCL7: J37.4, R210.1, TP102.1, U24.32
D21/SCL8: J42.4, R238.1, TP115.1, U27.32
D21/SCL9: J47.4, R266.1, TP128.1, U30.32
D28/USB_D-: J3.A7, J3.B7, U2.33
D28/USB_D-1: J2.A7, J2.B7, U6.33
D28/USB_D-2: J11.A7, J11.B7, U9.33
D28/USB_D-3: J16.A7, J16.B7, U12.33
D28/USB_D-4: J21.A7, J21.B7, U15.33
D28/USB_D-5: J26.A7, J26.B7, U18.33
D28/USB_D-6: J31.A7, J31.B7, U21.33
D28/USB_D-7: J36.A7, J36.B7, U24.33
D28/USB_D-8: J41.A7, J41.B7, U27.33
D28/USB_D-9: J46.A7, J46.B7, U30.33
D29/USB_D+: J3.A6, J3.B6, U2.34
D29/USB_D+1: J2.A6, J2.B6, U6.34
D29/USB_D+2: J11.A6, J11.B6, U9.34
D29/USB_D+3: J16.A6, J16.B6, U12.34
D29/USB_D+4: J21.A6, J21.B6, U15.34
D29/USB_D+5: J26.A6, J26.B6, U18.34
D29/USB_D+6: J31.A6, J31.B6, U21.34
D29/USB_D+7: J36.A6, J36.B6, U24.34
D29/USB_D+8: J41.A6, J41.B6, U27.34
D29/USB_D+9: J46.A6, J46.B6, U30.34
D30/CTS-I_LV: Q1.2, R14.1, U2.37
D30/CTS-I_LV1: Q10.2, R46.1, U6.37
D30/CTS-I_LV2: Q18.2, R74.1, U9.37
D30/CTS-I_LV3: Q26.2, R102.1, U12.37
D30/CTS-I_LV4: Q34.2, R130.1, U15.37
D30/CTS-I_LV5: Q42.2, R158.1, U18.37
D30/CTS-I_LV6: Q50.2, R186.1, U21.37
D30/CTS-I_LV7: Q58.2, R214.1, U24.37
D30/CTS-I_LV8: Q66.2, R242.1, U27.37
D30/CTS-I_LV9: Q74.2, R270.1, U30.37
D31/TX_LED: D2.A, U2.38
D31/TX_LED1: D11.A, U6.38
D31/TX_LED2: D20.A, U9.38
D31/TX_LED3: D29.A, U12.38
D31/TX_LED4: D38.A, U15.38
D31/TX_LED5: D47.A, U18.38
D31/TX_LED6: D56.A, U21.38
D31/TX_LED7: D65.A, U24.38
D31/TX_LED8: D74.A, U27.38
D31/TX_LED9: D83.A, U30.38
D38/RTS-O: J5.5, TP9.1, U2.22
D38/RTS-O1: J10.5, TP22.1, U6.22
D38/RTS-O2: J15.5, TP35.1, U9.22
D38/RTS-O3: J20.5, TP48.1, U12.22
D38/RTS-O4: J25.5, TP61.1, U15.22
D38/RTS-O5: J30.5, TP74.1, U18.22
D38/RTS-O6: J35.5, TP87.1, U21.22
D38/RTS-O7: J40.5, TP100.1, U24.22
D38/RTS-O8: J45.5, TP113.1, U27.22
D38/RTS-O9: J50.5, TP126.1, U30.22
GND: C3.2, C4.1, C5.2, C7.-, C8.C, C12.2, C13.2, C14.2, C15.2, C16.1, C19.2, D6.1, E2.GND@0, E2.GND@1, E2.GND@2, E2.GND@3, J1.1, J3.GND, J3.GND2, J4.3, J4.5, J4.9, J5.6, JP2.1, Q3.2, Q4.2, Q5.2, Q6.2, R1.1, R4.1, R5.1, R7.1, R8.1, R12.1, R18.1, R19.1, R27.1, R28.1, S1.2, S3.3, S3.4, U2.5, U2.18, U2.35, U2.42, U3.2, U4.1, U4.9, U4.10, U4.18, U4.20, U4.21, U4.22
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

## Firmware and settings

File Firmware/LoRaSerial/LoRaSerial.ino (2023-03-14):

/*
  December 15th, 2021
  SparkFun Electronics
  Nathan Seidle

  This firmware runs the core of the SparkFun LoRaSerial Radio product.
  Primarily designed to run on a ATSAMD21G18A with the ebyte 1W LoRa Radio based on the SX1276.

  This radio is designed to operate at the physical layer of LoRa sending data directly to an end point
  as opposed to something like LoRaWAN that operates on the data and network layers. For this reason
  LoRaSerial is not intended to operate on LoRaWAN.

  The system requests an ACK for certain packet types.

  Each packet contains data plus a NetID (byte) and Control byte.
  For transmissions at SpreadFactor 6 the packet length is set to 250 bytes and an additional byte is
  transmitted before NetID that repsents the actual data length within the packet.

  The max packet size for the SX127x is 255 bytes. With the NetID and control bytes removed, we have
  253 bytes available for data (252 when spread factor is 6).

  The AT command structure is based on the SiK Ardupilot radio.

  For a graphical view of the system state machine see: https://lucid.app/lucidchart/7293b4a6-690a-493e-a3f6-92bf47025fb1/edit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

  Build notes:
    RadioLib should have RADIOLIB_FIX_ERRATA_SX127X turned on (uncommented)

  Processors supported:
    SAMD21
    ESP32

  For other processors the following unique features must be considered:
    Interrupt capable pins for DIO0/1
    Processor reset (command ATZ)
    EEPROM read/write/commit
    ~14k RAM for serial RX/TX and radio buffers

  Compiled with Arduino v1.8.15
*/

const int FIRMWARE_VERSION_MAJOR = 2;
const int FIRMWARE_VERSION_MINOR = 0;

#define RADIOLIB_LOW_LEVEL  //Enable access to the module functions
//#define ENABLE_DEVELOPER true //Uncomment this line to enable special developer modes

#define UNUSED(x) (void)(x)

//Define the LoRaSerial board identifier:
//  This is an int which is unique to this variant of the LoRaSerial hardware which allows us
//  to make sure that the settings in EEPROM are correct for this version of the LoRaSerial
//  (sizeOfSettings is not necessarily unique and we want to avoid problems when swapping from one variant to another)
//  It is the sum of:
//    the major firmware version * 0x10
//    the minor firmware version
#define LRS_IDENTIFIER (FIRMWARE_VERSION_MAJOR * 0x10 + FIRMWARE_VERSION_MINOR)

#define CHANNEL_TIMER_BYTES sizeof(uint16_t) //Number of bytes used within in control header for clock sync (uint16_t msToNextHop)
#define CLOCK_MILLIS_BYTES sizeof(unsigned long) //Number of bytes used within in various packets for system timestamps sync (unsigned long currentMillis)
#define MAX_PACKET_SIZE 255 //Limited by SX127x
#define AES_IV_BYTES    12  //Number of bytes for AESiv
#define AES_KEY_BYTES   16  //Number of bytes in the encryption key
#define UNIQUE_ID_BYTES 16  //Number of bytes in the unique ID

//Frame lengths
#define MP_HEARTBEAT_BYTES      1 //Number of data bytes in the MP_HEARTBEAT frame
#define P2P_FIND_PARTNER_BYTES  sizeof(unsigned long) //Number of data bytes in the FIND_PARTNER frame
#define P2P_SYNC_CLOCKS_BYTES   (sizeof(uint8_t) + sizeof(unsigned long)) //Number of data bytes in the SYNC_CLOCKS frame
#define P2P_ZERO_ACKS_BYTES     sizeof(unsigned long) //Number of data bytes in the ZERO_ACKS frame
#define P2P_HEARTBEAT_BYTES     sizeof(unsigned long) //Number of data bytes in the HEARTBEAT frame
#define P2P_ACK_BYTES           sizeof(unsigned long) //Number of data bytes in the ACK frame
#define VC_HEARTBEAT_BYTES      1 + 1 + 1 + 16 + 4 //Number of data bytes in the VC_HEARTBEAT frame

//Bit 0: Signal Detected indicates that a valid LoRa preamble has been detected
//Bit 1: Signal Synchronized indicates that the end of Preamble has been detected, the modem is in lock
//Bit 3: Header Info Valid toggles high when a valid Header (with correct CRC) is detected
#define RECEIVE_IN_PROCESS_MASK   0b1011

//Always define ENABLE_DEVELOPER to enable its use in conditional statements
#ifndef ENABLE_DEVELOPER
#define ENABLE_DEVELOPER false
#endif  //ENABLE_DEVELOPER

#define SERIAL_RX_BUFFER_SIZE     1024
#define RTS_ON_BYTES              (SERIAL_RX_BUFFER_SIZE / 4)

#include "settings.h"

//Hardware connections
//=-=-=-=-=-=-=-=-=-=-=-=-=-=-=-=-=-=-=-=-=-=-=-=-=-=-=-=-=-=-=-=-=-=-=-=-=-=-=-=-=-=-=-=-=
//These pins are set in beginBoard()
#define PIN_UNDEFINED   255

uint8_t pin_rst = PIN_UNDEFINED;
uint8_t pin_cs = PIN_UNDEFINED;
uint8_t pin_txen = PIN_UNDEFINED;
uint8_t pin_rxen = PIN_UNDEFINED;
uint8_t pin_dio0 = PIN_UNDEFINED;
uint8_t pin_dio1 = PIN_UNDEFINED;
uint8_t pin_rts = PIN_UNDEFINED;
uint8_t pin_cts = PIN_UNDEFINED;
uint8_t pin_blue_LED = PIN_UNDEFINED;
uint8_t pin_yellow_LED = PIN_UNDEFINED;
uint8_t pin_trainButton = PIN_UNDEFINED;
uint8_t pin_green_1_LED = PIN_UNDEFINED;
uint8_t pin_green_2_LED = PIN_UNDEFINED;
uint8_t pin_green_3_LED = PIN_UNDEFINED;
uint8_t pin_green_4_LED = PIN_UNDEFINED;
uint8_t pin_boardID = PIN_UNDEFINED;

uint8_t pin_trigger = PIN_UNDEFINED;
uint8_t pin_hop_timer = PIN_UNDEFINED;

/*
        Antenna         Qwiic
    +---------------------------+
    |                           |
    |     G4   G3   G2   G1     |
    |                           |
    |                           |
    |                       Red |
    |                           |
    |                           |
    |            Blue    Yellow |
    |                           |
    +---------------------------+
        USB            Serial
*/

#define GREEN_LED_1         pin_green_1_LED //Top right
#define GREEN_LED_2         pin_green_2_LED
#define GREEN_LED_3         pin_green_3_LED
#define GREEN_LED_4         pin_green_4_LED //Top left
#define BLUE_LED            pin_blue_LED
#define YELLOW_LED          pin_yellow_LED //Bottom right

#define RADIO_USE_BLINK_MILLIS    15

#define LED_ON              HIGH
#define LED_OFF             LOW

#define LED_MAX_PULSE_WIDTH     24 //mSec
//-=-=-=-=-=-=-=-=-=-=-=-=-=-=-=-=-=-=-=-=-=-=-=-=-=-=-=-=-=-=-=-=-

//Radio Library
//-=-=-=-=-=-=-=-=-=-=-=-=-=-=-=-=-=-=-=-=-=-=-=-=-=-=-=-=-=-=-=-=-
#include <RadioLib.h> //Click here to get the library: http://librarymanager/All#RadioLib v5.6.0
SX1276 radio = NULL; //We can't instantiate here because we don't yet know what pin numbers to use

float *channels;
uint8_t channelNumber = 0;
uint32_t airSpeed;

//-=-=-=-=-=-=-=-=-=-=-=-=-=-=-=-=-=-=-=-=-=-=-=-=-=-=-=-=-=-=-=-=-

//Encryption
//=-=-=-=-=-=-=-=-=-=-=-=-=-=-=-=-=-=-=-=-=-=-=-=-=-=-=-=-=-=-=-=-=-=-=-=-=-=-=-=-=-=-=-=-=
#include <Crypto.h> //From: https://github.com/rweather/arduinolibs
#include <AES.h>
#include <GCM.h>
GCM <AES128> gcm;

uint8_t AESiv[AES_IV_BYTES] = {0}; //Set during hop table generation
//-=-=-=-=-=-=-=-=-=-=-=-=-=-=-=-=-=-=-=-=-=-=-=-=-=-=-=-=-=-=-=-=-

//Buttons - Interrupt driven and debounce
//-=-=-=-=-=-=-=-=-=-=-=-=-=-=-=-=-=-=-=-=-=-=-=-=-=-=-=-=-=-=-=-=-
#include <JC_Button.h> // http://librarymanager/All#JC_Button //v2.1.2
Button *trainBtn = NULL; //We can't instantiate the button here because we don't yet know what pin number to use

const int trainButtonClientTime = 3 * 1000; //ms press and hold before entering client training
const int trainButtonServerTime = 6 * 1000; //ms press and hold before entering server training
const int trainButtonFactoryResetTime = 10 * 1000; //ms press and hold before reset

bool inTraining; //True if training is in process
//-=-=-=-=-=-=-=-=-=-=-=-=-=-=-=-=-=-=-=-=-=-=-=-=-=-=-=-=-=-=-=-=-

//Hardware Timers
//=-=-=-=-=-=-=-=-=-=-=-=-=-=-=-=-=-=-=-=-=-=-=-=-=-=-=-=-=-=-=-=-=-=-=-=-=-=-=-=-=-=-=-=-=
#include "SAMDTimerInterrupt.h" //http://librarymanager/All#SAMD_TimerInterrupt v1.10.1 by Koi Hang
SAMDTimer channelTimer(TIMER_TCC); //Available: TC3, TC4, TC5, TCC, TCC1 or TCC2
volatile uint16_t channelTimerMsec; //Last value programmed into the channel timer
volatile unsigned long channelTimerStart = 0; //Tracks how long our timer has been running since last hop
volatile bool timeToHop = false; //Set by channelTimerHandler to indicate that hopChannel needs to be called
volatile bool reloadChannelTimer = false; //When set channel timer interval needs to be reloaded with settings.maxDwellTime

uint16_t petTimeout = 0; //A reduced amount of time before WDT triggers. Helps reduce amount of time spent petting.
unsigned long lastPet = 0; //Remebers time of last WDT pet.
//=-=-=-=-=-=-=-=-=-=-=-=-=-=-=-=-=-=-=-=-=-=-=-=-=-=-=-=-=-=-=-=-=-=-=-=-=-=-=-=-=-=-=-=-=

//Global variables - Serial
//-=-=-=-=-=-=-=-=-=-=-=-=-=-=-=-=-=-=-=-=-=-=-=-=-=-=-=-=-=-=-=-=-
const uint8_t escapeCharacter = '+';
const uint8_t maxEscapeCharacters = 3; //Number of characters needed to enter command mode
const uint8_t responseDelayDivisor = 4; //Add on to max response time after packet has been sent. Factor of 2. 8 is ok. 4 is good. A smaller number increases the delay.

//Buffer to receive serial data from the USB or serial ports
uint16_t rxHead = 0;
uint16_t rxTail = 0;
uint8_t serialReceiveBuffer[SERIAL_RX_BUFFER_SIZE];

//Buffer to store bytes for transmission via the long range radio
uint16_t radioTxHead = 0;
uint16_t radioTxTail = 0;
uint8_t radioTxBuffer[1024 * 3];

//Buffer to store bytes to be sent to the USB or serial ports
uint16_t txHead = 0;
uint16_t txTail = 0;
uint8_t serialTransmitBuffer[1024 * 4]; //Bytes received from RF waiting to be printed out UART. Buffer up to 1s of bytes at 4k

unsigned long lastByteReceived_ms = 0; //Track when last transmission was. Send partial buffer once time has expired.
//=-=-=-=-=-=-=-=-=-=-=-=-=-=-=-=-=-=-=-=-=-=-=-=-=-=-=-=-=-=-=-=-=-=-=-=-=-=-=-=-=-=-=-=-=

//Global variables - Command Processing
//-=-=-=-=-=-=-=-=-=-=-=-=-=-=-=-=-=-=-=-=-=-=-=-=-=-=-=-=-=-=-=-=-
char commandBuffer[100]; //Received serial gets stored into buffer until \r or \n is received
uint8_t commandRXBuffer[100]; //Bytes received from remote, waiting for printing or AT parsing
uint8_t commandTXBuffer[1024 * 4]; //Bytes waiting to be transmitted to the remote unit
uint16_t commandTXHead = 0;
uint16_t commandTXTail = 0;
uint16_t commandRXHead = 0;
uint16_t commandRXTail = 0;

uint8_t escapeCharsReceived = 0; //Used to enter command mode
unsigned long lastEscapeReceived_ms = 0; //Tracks end of serial traffic
const long minEscapeTime_ms = 2000; //Serial traffic must stop this amount before an escape char is recognized

bool inCommandMode = false; //Normal data is prevented from entering serial output when in command mode
uint8_t commandLength = 0;
bool remoteCommandResponse;
bool waitRemoteCommandResponse;

bool rtsAsserted; //When RTS is asserted, host says it's ok to send data
bool forceRadioReset = false; //Goes true when a setting requires a link/radio reset to work
bool writeOnCommandExit = false; //Goes true if user specifies ATW command

/* Data Flow - Point-to-Point and Multi-Point

                             USB or UART
                                  |
                                  | Flow control: RTS for UART
                                  |      Off: Buffer full
                                  |      On: Buffer drops below half full
                                  | updateSerial
                                  V
                         serialReceiveBuffer
                                  |
                                  | processSerialInput
                                  |
                                  | inCommandMode or local VC command?
                                  |
                     true         V        false
                    .-------------+--------------------------.
                    |                                        |
                    V                                        v
              commandBuffer                            radioTxBuffer
                    |                                        |
                    | Remote Command?                        v
                    |                                 outgoingPacket
       false        V         true                           |
      .-------------+-------------.                          V
      |                           |                Send to remote system
      |                           V                          |
      |                    outgoingPacket                    V
      |                           |                   incomingBuffer
      |                           V                          |
      |                 Send to remote system                |
      |                           |                          |
      |                           V                          |
      |                    incomingBuffer                    |
      |                           |                          |
      |                           V                          |
      |                    commandRXBuffer                   |
      |                           |                          |
      |                           V          VC Remote Cmd   V
      |                     commandBuffer <------------------+
      |                           |                          |
      |                           V                          |
      |                  Command processing                  |
      |                     checkCommand                     | Data or
      |                           |                          | VC Data or
      |                           V                          | VC Rmt Cmd Resp
      |                    commandTXBuffer                   |
      |                           |                          |
      |                           V                          |
      |                    outgoingPacket                    |
      |                           |                          |
      |                           V                          |
      |               Send back to local system              |
      |                           |                          |
      |                           V                          |
      |                    incomingBuffer                    |
      |                           |                          |
      |                           V                          |
      `-------------------------->+<-------------------------'
                                  |
                                  |
                                  V
                         serialTransmitBuffer
                                  |
                                  |
                                  V
                             USB or UART

*/

/* Data Flow - Virtual Circuit

                             USB or UART
                                  |
                                  | Flow control: RTS for UART
                                  |      Off: Buffer full
                                  |      On: Buffer drops below half full
                                  | updateSerial
                                  V
                         serialReceiveBuffer
                                  |
                                  | vcProcessSerialInput
                                  |
                                  | Destination VC?
                                  V                                    Other
                    .-------------+--------------->+---------------->+------> Discard
         VC_COMMAND |                         myVc |            >= 0 |
                    |                              |    VC_BROADCAST |
                    |                              |                 |
                    V                              |                 v
              commandBuffer                        |           radioTxBuffer
                    |                              |                 |
                    | Remote Command?              |                 v
                    |                              |           outgoingPacket
       false        V         true                 |                 |
      .-------------+-------------.                |                 V
      |                           |                |       Send to remote system
      |                           V                |                 |
      |                    outgoingPacket          |                 V
      |                           |                |          incomingBuffer
      |                           V                |                 |
      |                 Send to remote system      |                 |
      |                           |                |                 |
      |                           V                |                 |
      |                    incomingBuffer          |                 |
      |                           |                |                 |
      |                           V                |                 |
      |                    commandRXBuffer         |                 |
      |                           |                |                 |
      |                           V                |                 |
      |                  Command processing        |                 |
      |                     checkCommand           |                 |
      |                           |                |                 |
      |                           V                |                 |
      |                    commandTXBuffer         |                 |
      |                           |                |                 |
      |                           V                |                 |
      |                    outgoingPacket          |                 |
      |                           |                |                 |
      |                           V                |                 |
      |               Send back to local system    |                 |
      |                           |                |                 |
      |                           V                |                 |
      |                    incomingBuffer          |                 |
      |                           |                |                 |
      |                           V                V                 |
      `-------------------------->+<---------------+<----------------'
                                  |
                                  V
                        serialTransmitBuffer
                                  |
                                  | Flow control: CTS for UART
                                  |
                                  V
                             USB or UART

*/

//-=-=-=-=-=-=-=-=-=-=-=-=-=-=-=-=-=-=-=-=-=-=-=-=-=-=-=-=-=-=-=-=-

//Global variables - LEDs
//-=-=-=-=-=-=-=-=-=-=-=-=-=-=-=-=-=-=-=-=-=-=-=-=-=-=-=-=-=-=-=-=-
uint8_t cylonLedPattern = 0b0001;
bool cylonPatternGoingLeft;
//-=-=-=-=-=-=-=-=-=-=-=-=-=-=-=-=-=-=-=-=-=-=-=-=-=-=-=-=-=-=-=-=-

//Global variables - Radio (General)
//-=-=-=-=-=-=-=-=-=-=-=-=-=-=-=-=-=-=-=-=-=-=-=-=-=-=-=-=-=-=-=-=-
uint16_t radioBand = 0; //In MHz. Detected radio module type. Sets the upper/lower frequency bounds.
uint8_t outgoingPacket[MAX_PACKET_SIZE]; //Contains the current data in route to receiver
uint32_t frameAirTimeUsec; //Recalc'd with each new packet transmission
uint8_t frameSentCount = 0; //Increases each time a frame is sent

unsigned long lastPacketReceived = 0; //Controls link LED in broadcast mode
unsigned long lastLinkBlink = 0; //Controls link LED in broadcast mode

volatile uint16_t irqFlags; //IRQ Flags register value
volatile bool transactionComplete = false; //Used in dio0ISR
uint8_t sf6ExpectedSize = MAX_PACKET_SIZE; //Used during SF6 operation to reduce packet size when needed

float radioFrequency; //Current radio frequency
float frequencyCorrection = 0; //Adjust receive freq based on the last packet received freqError

volatile bool hop = true; //Clear the DIO1 hop ISR when possible

int rssi; //Average signal level, measured during reception of a packet

//Link quality metrics
uint32_t datagramsSent;     //Total number of datagrams sent
uint32_t datagramsReceived; //Total number of datagrams received
uint32_t framesSent;        //Total number of frames sent
uint32_t framesReceived;    //Total number of frames received
uint32_t badFrames;         //Total number of bad frames received
uint32_t duplicateFrames;   //Total number of duplicate frames received
uint32_t lostFrames;        //Total number of lost TX frames
uint32_t linkFailures;      //Total number of link failures
uint32_t insufficientSpace; //Total number of times the buffer did not have enough space
uint32_t badCrc;            //Total number of bad CRC frames
uint32_t netIdMismatch;     //Total number of mismatched Net ID frames

unsigned long lastLinkUpTime = 0; //Mark when link was first established
unsigned long lastRxDatagram; //Remember last valid receive

//Receiver and Transmitter status
unsigned long rxSuccessMillis;
unsigned long rxFailureMillis;
int rxFailureState;

//Receive failures
unsigned long startReceiveFailureMillis;
int startReceiveFailureState;
unsigned long lastReceiveInProcessTrue;
uint8_t lastModemStatus;

unsigned long txSuccessMillis;
unsigned long txFailureMillis;
int txFailureState;

//History
unsigned long radioCallHistory[RADIO_CALL_MAX];
unsigned long radioStateHistory[RADIO_MAX_STATE];

uint8_t packetLength = 0; //Total bytes received, used for calculating clock sync times in multi-point mode
int16_t msToNextHopRemote; //Can become negative
uint8_t clockSyncIndex;
CLOCK_SYNC_DATA clockSyncData[16];
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
void loop()
{
  petWDT();

  updateButton(); //Check if train button is pressed

  updateSerial(); //Store incoming and print outgoing

  updateRadioState(); //Send packets as needed for handshake, data, remote commands

  updateLeds(); //Update the LEDs on the board

  updateHopISR(); //Clear hop ISR as needed
}

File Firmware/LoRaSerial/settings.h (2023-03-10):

typedef enum
{
  RADIO_RESET = 0,

  //Point-To-Point: Bring up the link
  RADIO_P2P_LINK_DOWN,
  RADIO_P2P_WAIT_TX_FIND_PARTNER_DONE,
  RADIO_P2P_WAIT_SYNC_CLOCKS,
  RADIO_P2P_WAIT_TX_SYNC_CLOCKS_DONE,
  RADIO_P2P_WAIT_ZERO_ACKS,
  RADIO_P2P_WAIT_TX_ZERO_ACKS_DONE,

  //Point-to-Point: Link up, data exchange
  RADIO_P2P_LINK_UP,
  RADIO_P2P_LINK_UP_WAIT_TX_DONE,

  //Server-client discovery
  RADIO_DISCOVER_BEGIN,
  RADIO_DISCOVER_SCANNING,
  RADIO_DISCOVER_WAIT_TX_FIND_PARTNER_DONE,
  RADIO_DISCOVER_STANDBY,

  //Multi-Point: Datagrams
  RADIO_MP_STANDBY,
  RADIO_MP_WAIT_TX_DONE,

  //Training client states
  RADIO_TRAIN_WAIT_TX_FIND_PARTNER_DONE,
  RADIO_TRAIN_WAIT_RX_RADIO_PARAMETERS,
  RADIO_TRAIN_WAIT_TX_PARAM_ACK_DONE,

  //Training server states
  RADIO_TRAIN_WAIT_FOR_FIND_PARTNER,
  RADIO_TRAIN_WAIT_TX_RADIO_PARAMS_DONE,

  //Virtual-Circuit states
  RADIO_VC_WAIT_SERVER,
  RADIO_VC_WAIT_TX_DONE,
  RADIO_VC_WAIT_RECEIVE,

  RADIO_MAX_STATE,
} RadioStates;

RadioStates radioState = RADIO_RESET;

#define LINK_BREAK_MULTIPLIER           3

typedef struct _RADIO_STATE_ENTRY
{
  RadioStates state;
  bool rxState;
  const char * name;
  const char * description;
} RADIO_STATE_ENTRY;

const RADIO_STATE_ENTRY radioStateTable[] =
{
  {RADIO_RESET,                          0, "RESET",                          NULL},                         // 0

  //Point-to-Point link handshake
  //    State                           RX      Name                              Description
  {RADIO_P2P_LINK_DOWN,                  1, "P2P_LINK_DOWN",                  "P2P: [No Link] Waiting for FIND_PARTNER"}, // 1
  {RADIO_P2P_WAIT_TX_FIND_PARTNER_DONE,  0, "P2P_WAIT_TX_FIND_PARTNER_DONE",  "P2P: [No Link] Wait FIND_PARTNER TX Done"},// 2
  {RADIO_P2P_WAIT_SYNC_CLOCKS,           1, "P2P_WAIT_SYNC_CLOCKS",           "P2P: [No Link] Waiting for SYNC_CLOCKS"},  // 3
  {RADIO_P2P_WAIT_TX_SYNC_CLOCKS_DONE,   0, "P2P_WAIT_TX_SYNC_CLOCKS_DONE",   "P2P: [No Link] Wait SYNC_CLOCKS TX Done"}, // 4
  {RADIO_P2P_WAIT_ZERO_ACKS,             1, "P2P_WAIT_ZERO_ACKS",             "P2P: [No Link] Waiting for ZERO_ACKS"},    // 5
  {RADIO_P2P_WAIT_TX_ZERO_ACKS_DONE,     0, "P2P_WAIT_TX_ZERO_ACKS_DONE",     "P2P: [No Link] Wait ZERO_ACKS TX Done"},   // 6

  //Point-to-Point, link up, data exchange
  //    State                           RX      Name                              Description
  {RADIO_P2P_LINK_UP,                    1, "P2P_LINK_UP",                    "P2P: Receiving Standby"},          // 7
  {RADIO_P2P_LINK_UP_WAIT_TX_DONE,       0, "P2P_LINK_UP_WAIT_TX_DONE",       "P2P: Waiting TX done"},            // 8

  //Server-client discovery
  //    State                           RX      Name                              Description
  {RADIO_DISCOVER_BEGIN,                 0, "DISCOVER_BEGIN",                 "Disc: Setup for scanning"},                  // 9
  {RADIO_DISCOVER_SCANNING,              0, "DISCOVER_SCANNING",              "Disc: Scanning for servers"},                //10
  {RADIO_DISCOVER_WAIT_TX_FIND_PARTNER_DONE, 0, "DISCOVER_WAIT_TX_FIND_PARTNER_DONE", "Disc: Wait for FIND_PARTNER to xmit"}, //11
  {RADIO_DISCOVER_STANDBY,               0, "RADIO_DISCOVER_STANDBY",         "Disc: Wait for Server HB"},                  //12

  //Multi-Point data exchange
  //    State                           RX      Name                              Description
  {RADIO_MP_STANDBY,                     1, "MP_STANDBY",                     "MP: Wait for TX or RX"},           //13
  {RADIO_MP_WAIT_TX_DONE,                0, "MP_WAIT_TX_DONE",                "MP: Waiting for TX done"},         //14

  //Training client states
  //    State                           RX      Name                              Description
  {RADIO_TRAIN_WAIT_TX_FIND_PARTNER_DONE, 0, "TRAIN_WAIT_TX_FIND_PARTNER_DONE", "Train: Wait TX training FIND_PARTNER done"}, //15
  {RADIO_TRAIN_WAIT_RX_RADIO_PARAMETERS, 1, "TRAIN_WAIT_RX_RADIO_PARAMETERS", "Train: Wait for radio parameters"},          //16
  {RADIO_TRAIN_WAIT_TX_PARAM_ACK_DONE,   0, "TRAIN_WAIT_TX_PARAM_ACK_DONE",   "Train: Wait for TX param ACK done"},         //17

  //Training server states
  //    State                           RX      Name                              Description
  {RADIO_TRAIN_WAIT_FOR_FIND_PARTNER,    1, "TRAIN_WAIT_FOR_FIND_PARTNER",    "Train: Wait for training FIND_PARTNER"}, //18
  {RADIO_TRAIN_WAIT_TX_RADIO_PARAMS_DONE, 0, "TRAIN_WAIT_TX_RADIO_PARAMS_DONE", "Train: Wait for TX params done"},      //19
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

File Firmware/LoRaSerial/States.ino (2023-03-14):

#define SAVE_TX_BUFFER()                                  \
  {                                                       \
    petWDT();                                             \
    memcpy(rexmtBuffer, outgoingPacket, MAX_PACKET_SIZE); \
    rexmtControl = txControl;                             \
    rexmtLength = txDatagramSize;                         \
    rexmtFrameSentCount = frameSentCount;                 \
  }

#define RESTORE_TX_BUFFER()                               \
  {                                                       \
    petWDT();                                             \
    memcpy(outgoingPacket, rexmtBuffer, MAX_PACKET_SIZE); \
    txControl = rexmtControl;                             \
    txDatagramSize = rexmtLength;                         \
    frameSentCount = rexmtFrameSentCount;                 \
  }

#define P2P_SEND_ACK(trigger)                                                   \
  {                                                                             \
    /*Compute the frequency correction*/                                        \
    frequencyCorrection += radio.getFrequencyError() / 1000000.0;               \
    \
    /*Send the ACK to the remote system*/                                       \
    triggerEvent(trigger);                                                      \
    if (xmitDatagramP2PAck() == true)                                           \
    {                                                                           \
      /*We ack'd the packet so be responsible for sending the next heartbeat*/  \
      setHeartbeatShort();                                                      \
      changeState(RADIO_P2P_LINK_UP_WAIT_TX_DONE);                              \
    }                                                                           \
  }

#define START_ACK_TIMER()                                                       \
  {                                                                             \
    /*Start the ACK timer*/                                                     \
    ackTimer = datagramTimer;                                                   \
    \
    /*Since ackTimer is off when equal to zero, force it to a non-zero value*/  \
    /*Subtract one so that the comparisons result in a small number*/           \
    if (!ackTimer)                                                              \
      ackTimer -= 1;                                                            \
  }

#define STOP_ACK_TIMER()      \
  {                           \
    /*Stop the ACK timer*/    \
    ackTimer = 0;             \
  }

#define COMPUTE_TIMESTAMP_OFFSET(millisBuffer, rShift, frameAirTimeUsec)               \
  {                                                                                    \
    unsigned long deltaUsec = frameAirTimeUsec + micros() - transactionCompleteMicros; \
    memcpy(&remoteSystemMillis, millisBuffer, sizeof(remoteSystemMillis));             \
    timestampOffset = remoteSystemMillis + (deltaUsec / 1000) - millis();              \
    timestampOffset >>= rShift;                                                        \
  }

//Process the radio states
void updateRadioState()
{
  int8_t addressByte;
  uint8_t channel;
  unsigned long clockOffset;
  unsigned long currentMillis;
  unsigned long deltaMillis;
  uint8_t * header = outgoingPacket;
  bool heartbeatTimeout;
  int index;
  uint16_t length;
  uint8_t radioSeed;
  bool serverLinkBroken;
  unsigned long timeoutMsec;
  VIRTUAL_CIRCUIT * vc;
  VC_RADIO_MESSAGE_HEADER * vcHeader;

  switch (radioState)
  {
    default:
      {
        systemPrint("Unknown state: ");
        systemPrintln(radioState);
        waitForever("ERROR - Unknown radio state!");
      }
      break;

    //=-=-=-=-=-=-=-=-=-=-=-=-=-=-=-=-=-=-=-=-=-=-=-=-=-=-=-=-=-=-=-=-=-=-=-=-=-=-=-=-=-=-=-=-=
    // Reset
    //=-=-=-=-=-=-=-=-=-=-=-=-=-=-=-=-=-=-=-=-=-=-=-=-=-=-=-=-=-=-=-=-=-=-=-=-=-=-=-=-=-=-=-=-=

    case RADIO_RESET:
      petWDT();

      //Empty the buffers
      discardPreviousData();

      //Set all of the ACK numbers to zero
      *(uint8_t *)(&txControl) = 0;

      //Initialize the radio
      rssi = -200;
      radioSeed = radio.randomByte(); //Puts radio into standy-by state
      randomSeed(radioSeed);
      if ((settings.debug == true) || (settings.debugRadio == true))
      {
        systemPrint("RadioSeed: ");
        systemPrintln(radioSeed);
        outputSerialData(true);
      }

      generateHopTable(); //Generate frequency table based on user settings.

      selectHeaderAndTrailerBytes(); //Determine the components of the frame header and trailer

      stopChannelTimer(); //Stop frequency hopping - reset
      clockSyncReceiver = true; //Assume receiving clocks - reset

      configureRadio(); //Setup radio, set freq to channel 0, calculate air times

      //Determine the maximum frame air time
      maxFrameAirTimeMsec = (calcAirTimeUsec(MAX_PACKET_SIZE) + 500) / 1000;

      sf6ExpectedSize = headerBytes + CLOCK_MILLIS_BYTES + trailerBytes; //Tell SF6 to receive FIND_PARTNER packet

      petWDT();

      //Stop the ACK timer
      STOP_ACK_TIMER();
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

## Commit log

2022-01-13 Add ignore. Fix RP-SMA connector.
    [SparkFun SRT - LoRa 1W.GBL, SparkFun SRT - LoRa 1W.GBO, SparkFun SRT - LoRa 1W.GBP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]
2022-01-13 Update to new RP SMA connector package
    [SparkFun SRT - LoRa 1W.brd, SparkFun SRT - LoRa 1W.sch]
2022-01-21 File rename
    [SparkFun LoRaSerial - 1W.brd, SparkFun LoRaSerial - 1W.sch]
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2022-01-24 Fix receiveInProgess, prevent serial print blocking, add 40 and 400bps airspeed, ESP32 EEPROM support, debug trigger pin
    [Begin.ino, Commands.ino, NVM.ino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]
2022-01-24 Add train button, TX/RX LEDs, CTS/RTS connections, GPIO breakout. Increase to v11.
    [SparkFun LoRaSerial - 1W.brd, SparkFun LoRaSerial - 1W.sch]
2022-01-25 Add v11 panel
    [SparkFun LoRaSerial - 1W-Panel.GBL, SparkFun LoRaSerial - 1W-Panel.GBO, SparkFun LoRaSerial - 1W-Panel.GBP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]
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2022-01-27 Fix packetSize math for SF6. Fix ACK expectations.
    [Radio.ino, States.ino]
2022-01-28 Remove noise triggered hops testing. Add dwellTime setting. Increase maxHopPeriod to 255. Adjust trigger widths.
    [Commands.ino, Radio.ino, States.ino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]
2022-01-29 Add preliminary broadcasting. Remove noise triggered hop code.
    [Begin.ino, Commands.ino, Radio.ino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]
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2022-02-02 Fix reversed pinout on locking JST.
    [SparkFun LoRaSerial - 1W.brd, SparkFun LoRaSerial - 1W.sch]
2022-02-08 Add display AES key. Always echo serial during AT config.
    [SparkFun LoRaSerial - 1W.sch]
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2022-02-18 Add sub folders for other frequencies
    [SparkFun LoRaSerial - 1W-Panel.GBL, SparkFun LoRaSerial - 1W-Panel.GBO, SparkFun LoRaSerial - 1W-Panel.GBP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]
2022-02-23 Add RSSI LEDs
    [SparkFun LoRaSerial 915MHz - 1W.brd, SparkFun LoRaSerial 915MHz - 1W.sch]
2022-02-23 Fix break bug in AT commands for ATS2*
    [Commands.ino]
2022-02-23 Prevent double encryption and scrambling when resending.
    [Radio.ino]
2022-02-23 Add more timeToHop checking. Add WDT handling for ESP32. Move clearFHSSInt to hopChannel.
2022-02-23 Set defaults to no scrambling, no autotune. Add short delay for fast datarates.
    [Radio.ino, States.ino, settings.h]
2022-02-25 Adjust 50ohm microstrip for four layer
    [SparkFun LoRaSerial 915MHz - 1W-Panel.brd, SparkFun LoRaSerial 915MHz - 1W.brd, SparkFun LoRaSerial 915MHz - 1W.sch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]
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2022-02-25 Replace template with functions for ESP support.
    [System.ino]
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2022-03-09 Add TX of command and responses. Rename packet types.
    Remove F() prints.
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2022-03-29 Update resistors to increase LED brightness
    [SparkFun LoRaSerial 915MHz - 1W.brd, SparkFun LoRaSerial 915MHz - 1W.sch]
2022-03-29 Add programing files. Add back board file.
    [SparkFun LoRaSerial 915MHz - 1W.brd]
2022-04-06 Add RSSI LED drivers. v13
    [SparkFun LoRaSerial 915MHz - 1W.brd, SparkFun LoRaSerial 915MHz - 1W.sch]
2022-04-11 Add TPs, GND stitching, sch cosmetic cleanup.
    [SparkFun LoRaSerial 915MHz - 1W.brd, SparkFun LoRaSerial 915MHz - 1W.sch]
2022-04-13 Fix printing of binary chars
    [System.ino]
2022-05-19 v13 - panel files.
    [SparkFun LoRaSerial 915MHz - 1W-Panel.brd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]
2022-05-19 Change to in stock 3.3V regulator
    [SparkFun LoRaSerial 915MHz - 1W-Panel.brd, SparkFun LoRaSerial 915MHz - 1W.brd, SparkFun LoRaSerial 915MHz - 1W.sch]
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2022-06-23 Add WDT pet to avoid reset during ATI0 printing
    [Commands.ino]
2022-08-29 Add enclosure files
    [LRS-Enclosure-Body.stl, LRS-Enclosure-Lid.stl]
2022-08-30 Change RSSI LED resistors to 22 ohm
    [SparkFun LoRaSerial 915MHz - 1W.brd, SparkFun LoRaSerial 915MHz - 1W.sch]
2022-08-30 Add 868MHz PCB
    [SparkFun LoRaSerial 868MHz - 1W-Panel.GBL, SparkFun LoRaSerial 868MHz - 1W-Panel.GBO, SparkFun LoRaSerial 868MHz - 1W-Panel.GBP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]
2022-08-30 Add 433MHz and 868MHz designs
    [SparkFun LoRaSerial 433MHz - 1W-Panel.GBL, SparkFun LoRaSerial 433MHz - 1W-Panel.GBO, SparkFun LoRaSerial 433MHz - 1W-Panel.GBP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]
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2022-09-07 Rework command processor (set, display, display list)
    This change:
    * Adds the command table
    * Adds a routine to display a setting value
    * Adds a routine to set a setting value
    * Adds routine to display the list of settings
    * Supports sorting the list of settings by name
    Verified using the following script:
    Firmware/Tools/Command_Validation_Script.txt
    Results found in:
    Firmware/Tools/Results/Command_Validation_Results.txt
    [Commands.ino, System.ino, settings.h]
2022-09-08 Always display the radio configuration failure message
    [Radio.ino]
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2022-09-10 Remove F() from around strings
    Testing, display ROM/RAM usage before, add string (line noise), display
    ROM/RAM usage after - Results ROM increased by string size, RAM
    increased by address size (4 bytes)
    Sketch uses 81552 bytes (31%) of program storage space. Maximum is
    262144 bytes.
    Global variables use 16068 bytes (49%) of dynamic memory, leaving 16700
    bytes for local variables. Maximum is 32768 bytes.
    systemPrintln(junk_to_test_string_location);
    char * junk_to_test_string_location =
    "sdlkjdsa;flkjasdf;lkjq;lkja;lkjdaf;lkjsadf;lkjasd;flkjsad;fkjas;dfkjasd;flkjsad;flkjas;fdkjsa;fdkjsa;fdkja;fdkj";
    Sketch uses 81668 bytes (31%) of program storage space. Maximum is
    262144 bytes.
    Global vari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
    [Radio.ino, Serial.ino, States.ino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]
2022-09-11 Add unique ID support
    The unique ID is a 128 bit (16 byte) value that is CPU architecture
    specific.
    Add command ATI8 to print the unique ID value
2022-09-11 Add settings to define the trigger operation
    triggerWidth: Fixed width of trigger pulses
    triggerWidthIsMultiplier: Use the trigger width as a multiplier
    triggerEnable: Bit mask of enabled triggers from 31 - 0
    triggerEnable2: Bitmask of enabled triggers from 63 - 32
    [Commands.ino, System.ino, settings.h]
2022-09-12 Add debugReceive setting
    Output the various steps during the receive operation
    Use PrintRfData and PrintPktData to dump the receive packet data
2022-09-26 Add debugTransmit and printTxErrors settings
    Output the various steps during the transmit operation
    Use PrintRfData and PrintPktData to dump the transmit packet data
2022-09-26 Add reset state
    Put the reset decisions in a state
    [Begin.ino, States.ino, Train.ino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]
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2022-10-03 Define PIN_UNDEFINED and use it to replace a large number of 255s
    [Begin.ino, Radio.ino, Serial.ino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]
2022-10-03 Set maxDatagramSize and use it to replace 255 - 3
    [Radio.ino, Serial.ino, States.ino]
2022-10-03 V2: Synchronize the clocks
    Compute a clock offset that is used to adjust the timestamp display.
    The offset is (1/2)(local clock + remote clock + round trip time)
    Add displayRealMillis parameter and ATS49 command to display millis
    * Display real millisecond value in timestamp when set true
    * Display adjusted (time synchronized) timestamp when false
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2022-10-06 Calculate datagram and ack airtime for correct timeouts
    [Radio.ino, States.ino, settings.h]
2022-10-07 Revert "Calc packet air time"
    [Begin.ino, Commands.ino, Radio.ino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]
2022-10-07 Correct datagram count handling
    rxAckNumber was being overwritten in rcvDatagram() regardless of gram type. Reduce number of counters to two (ack and everything else).
    [States.ino]
2022-10-07 Force reset of timer
    This fixes a rare timer hang seen when link is re-established
2022-10-07 Reset heartbeat after data or sync
    [States.ino]
2022-10-09 Verify AES encryption key and block counter lengths
    Replace magic numbers with defined constants.
    Verify the defined constants.
    [Radio.ino, System.ino, settings.h]
2022-10-12 Only enable one protocol version at a time
    Switch useV2 to protocolVersion to support future protocols
    Add comments to end of settings as reminders to update code
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2022-10-13 Add selectTraining routine
    Pass in parameter to determining the set of parameters to use (current
    or default).
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2022-10-14 Remove V1 Radio Protocol
    Switch to using V2 by default
    Remove V1 states from state machine
    Remove V1 training
    Remove V1 radio protocol routines
    Remove V1 states
    Regroup global variables
    Remove unused V1 variables
    Rename PACKET_ to DATAGRAM_ and add V2 in MAX_V2_DATAGRAM_TYPE
    Add link quality metrics
    Rename packetSent to frameSentCount
    Fix counting of transmitted frames.
    Rename controlPacketAirTime to ackAirTime
    Rename packetAirTime and datagramAirTime to frameAirTime
    [Commands.ino, Radio.ino, States.ino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]
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2022-10-17 Count and display total link failures
    [Commands.ino, States.ino]
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2022-10-21 VC: Add basis virtual circuit support (P2P, VC0<->VC1) Freq 0
    Testing with the following scripts:
    //Virtual-Circuit - Server, noHOP, netId, CRC, Debug
    +++
    at&f
    ats3=2
    ats51=1
    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
2022-10-27 Add RX Flow_Control test sketch
    Test case:
    States.ino --> USB in --> USB out --> st.txt
    Results:
    The files matched, except the following lines were added to the output
    file:
    Delay time: 495522 mSec
    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
2022-10-28 Add ATS58 and ATS59 commands to invert CTS and RTS
    Add invertCts and invertRts to settings.
    Move setting of RTS into a subroutine to properly handle inversion.
    Replace the direct writes to the RTS pin with calls to the subroutine.
    Prevent serial input until the end of setup.
    [Arch_SAMD.h, Commands.ino, Serial.ino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]
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2022-10-28 Support serial data flow control across the radio link
    Only read data from the serial port or USB when there is space in the
    serialReceiveBuffer. Deassert RTS when serialReceiveBuffer is full.
    Assert RTS when serialReceiveBuffer drops to half full and there is lots
    of space in the transmit buffer.
    Testing done by sending States.ino across the radio link and verifying
    the resulting file. This has been successful a couple of times, but the
    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
2022-10-28 Always call resetHeartbeat instead of setting heartbeatTimer directly
    [States.ino]
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2022-10-31 Add short/long heartbeat
    Prevent pair from having even random heartbeat at same time.
    [States.ino]
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2022-11-02 Fix hops when clock syncing. Print link uptime during debug.
    [States.ino]
2022-11-03 Prevent double hop if ISR triggers during clock sync
    The hop ISR may occur while we are forcing a hop (case A and C). Reset timeToHop as needed.
    [settings.h]
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2022-11-04 Allow reverse hop table walking
    [Radio.ino]
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2022-11-10 Add CRC Error cases to radio states
    [States.ino]
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2022-11-11 Fix the virtual circuit header alignment
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2022-11-11 Fix systemWrite with length
    Bug: System rebooting when the link up message is received
    Fix: Properly increment the buffer address in systemWrite with length
    [System.ino]
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2022-11-11 Fix help for ATR and ATS commands
    [Commands.ino]
2022-11-11 Fix letter for ATL command
    [Commands.ino]
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2022-11-14 Fix length in link status message
    [States.ino]
2022-11-14 Rename ATL command to ATB (break link)
    Add debug output to the command
    Call break link routine to notify caller that the link is down
    Only reset ring buffers when the local host's link breaks
    [Commands.ino, Serial.ino, States.ino]
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2022-11-17 Prevent a rexmit from corrupting a restored buffer
    [States.ino]
2022-11-17 Correct heartbeat timeouts as we link up
    [States.ino]
2022-11-17 Increase heartbeat timeout by frame transmit time
    This allows heartbeat lengths to be correctly started once the transmission is complete.
2022-11-17 Throttle retransmits
    Adds a global called retransmitTimeout. This var is calculated at transmit and is atleast ackAirTime, but may be as large as frameTime+ackAirTime. For each failed transmission, retransmit is delayed by this random amount * failed attempts.
    [States.ino, settings.h]
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2022-11-18 Determine settings before selecting header bytes
    Partial fix for SF6
    [Radio.ino, States.ino, System.ino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]
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2022-11-26 VC: Add vcLinkUp routine
    Only reset ACK counters if link was down
    [States.ino]
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2022-12-01 VC: Remote command support any VC to any VC
    This commit includes the following changes:
    * Modify serial to pass remote commands to the transmit code
    * Modify radio code to display the proper VC numbers
    * Leave all remote commands in the outgoingPacket
    * Process the remote command locally
    - Place response in commandTXBuffer
    - Divide up response and place in serialTransmitBuffer
    * Place the remote command into the command buffer and process it
    * Transmit command response to VC that issued the command
    * Receive the command response
    [Serial.ino, States.ino, Virtual_Circuit_Protocol.h]
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2022-12-05 Add missing routine comments
    [Arch_ESP32.h, Arch_SAMD.h, Begin.ino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]
2022-12-06 VC: Fix link timeouts, use data and HEARTBEATS to keep link alive
    [Commands.ino, States.ino, settings.h]
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2022-12-08 Remember last successful and failure TX and RX
    [Commands.ino, Radio.ino]
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2022-12-08 Bug Fix: Data corruption would occur when rxSrcVc = VC_BROADCAST
    [States.ino]
2022-12-09 VC: Bug fix, clear the vcConnecting bit during VC_STATE_CONNECTED
    [States.ino]
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2022-12-09 Fix uint to int compilation error
    Radiolib returns negative errors. U16_TO_STRING changed to handle ints.
    [Radio.ino, settings.h]
2022-12-09 Move all LED control to updateLEDs()
    This prevents multiple functions and states from trying to control the LEDs during default RSSI mode.
    [Commands.ino, States.ino, System.ino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]
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2022-12-10 Enable button training off-the-shelf
    If radios are in default P2P state, and training is pressed, units now complete training. If a different mode is used, or if server is set, server will stay in training until button press or command is issued. If a user wants to train specific custom settings in P2P mode using the training button, the user should put the unit with the desired settings into training first (ie have its train button pressed first).
    [States.ino, System.ino, Train.ino]
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2022-12-11 Prevent auto-server training when mode is not P2P.
    [States.ino]
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2022-12-12 Change 868MHz connector to SMA
    [SparkFun LoRaSerial 868MHz - 1W.brd, SparkFun LoRaSerial 868MHz - 1W.sch]
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2022-12-13 Display start receive failures in ATI10
    [Commands.ino, Radio.ino]
2022-12-13 Fix last up time display
    [Commands.ino]
2022-12-15 Add reset column to command table. Rename originalSettings to tempSettings.
    [Commands.ino, Radio.ino, States.ino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]
2022-12-15 Force radio link reset if certain settings are modified.
    [Commands.ino, Serial.ino]
2022-12-15 Print output during hard error
    [Begin.ino]
2022-12-15 Mark server setting as requiring radio reset
    [Commands.ino]
2022-12-16 Fix at-server=r, properly parse an integer and floating point value
    The strtod function does not set errno upon error!
    [Commands.ino]
2022-12-16 P2P: Use macro to replace common code to send ACK
    [States.ino]
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2022-12-16 Display link failures with the ATI10 command
    [Commands.ino]
2022-12-18 Fix the upper-casing of the command
    [Commands.ino]
2022-12-20 VC: Fix local command processing
    [Commands.ino, Serial.ino]
2022-12-20 VC: Fix remote command processing
    [States.ino]
2022-12-20 VC: Notify the PC of the LoRaSerial reset
    [Commands.ino, Virtual_Circuit_Protocol.h]
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2022-12-20 Fix the macro that sets the ackTimer
    Fix bug when ackTimer is zero and a comparison is done immediately.
    millis() = 0
    ackTimer = 1
    - ___
    -1 = 0xFFFFFFFF
    If the resulting value is treated as an unsigned number it is larger
    than all of the timeout values.
    Fix:
    millis() = 0
    ackTimer = -1 (0xFFFFFFFF)
    - ____
    1
    This result value reduces the expected timeout value by one millisecond
    which is significantly less than all of the timeouts.
    [States.ino]
2022-12-20 Replace xmitDatagramMpFindPartner with xmitDatagramP2PFindPartner
    [Radio.ino, States.ino, settings.h]
2022-12-21 Replace MP_WAIT_TX_ACK_DONE with RADIO_MP_WAIT_TX_DONE
    This commit makes the following changes:
    * Establisheds defines for SYNC_CLOCKS_BYTES and ZERO_ACKS_BYTES
    * Verifies the values of the defines above
    * Replaces xmitDatagramMpAck with xmitDatagramP2PSyncClocks
    * Adds channel number to xmitDatagramP2PSyncClocks
    * Adds discovery and multipoint state diagram
    * Replaces RADIO_MP_WAIT_TX_ACK_DONE with RADIO_MP_WAIT_TX_DONE since
    hop can be done after clock and channel synchronization
    [Radio.ino, States.ino, settings.h]
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2023-01-03 Define a single source for channelTimer corrections
    For point-to-point mode the source for channel timer corrections is the
    system that sent the DATAGRAM_SYNC_CLOCKS frame. The other system is
    the only system that updates its timer.
    For multi-point and virtual-circuit modes the server is the source for
    channel timer corrections. The client systems all synchronize to the
    server.
    [Radio.ino, States.ino]
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2023-01-03 Minimize rxTimeUsec and txTimeUsec after initial value following reset
    [States.ino]
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2023-01-07 Don't spin forever when a channel timer value error is detected on RX
    [Radio.ino]
2023-01-07 Fix the case when both the remote and local values are negative
    [Radio.ino]
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2023-01-09 Describe the steps to prevent attacks on the LoRaSerial network
    [Radio.ino]
2023-01-09 Output the correct channelNumber LSB on port A1 in syncChannelTimer
    [Radio.ino]
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2023-01-12 VC: Fix computation for next HEARTBEAT interval
    [Radio.ino, States.ino]
2023-01-12 VC: Fix the timestamp offset calculations
    [States.ino]
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2023-01-12 P2P: Fix error in link down/up synchronization
    [States.ino]
2023-01-12 Fix wrap around test
    [Radio.ino]
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2023-01-13 Bug Fix: memory corruption, clockSyncIndex got larger than array size
    [Radio.ino, States.ino]
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2023-01-17 Display the command which received the error
    [Commands.ino]
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2023-01-23 Blink error LED and regularly output an error message
    Add an error message to waitForever
    [Begin.ino, Radio.ino, States.ino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]
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2023-01-23 Fix bug in RADIO_DISCOVER_SCANNING. Remove channel number from heartbeat.
    [Radio.ino, States.ino]
2023-01-23 MP: Reset heartbeat timeout when in standby.
    [States.ino]
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2023-01-26 Fix bug in return of getReceiveCompletionOffset
    [System.ino]
2023-01-28 Fix calcAirTime to use LDRO and Implicit header.
    [Radio.ino]
2023-01-28 Fix roll-over bug in syncChannelTimer
    [Radio.ino]
2023-01-28 Fix starting channel number
    [States.ino]
2023-01-30 Replace TX_TO_RX_USEC with settings.txToRxUsec
    [Commands.ino, Radio.ino, States.ino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]
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2023-01-30 Replace maxPacketAirTime with maxFrameAirTimeMsec
    [Radio.ino, States.ino]
2023-01-30 Replace ackAirTime with txDataAckUsec
    [Radio.ino, States.ino]
2023-01-30 Replace frameAirTime with frameAirTimeUsec
    [Radio.ino, States.ino]
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2023-01-30 Prevent channel timer from starting if P2P link times out.
    [Radio.ino, States.ino]
2023-01-31 VC: Fix infinite output, START_OF_VC_SERIAL already removed
    [Serial.ino]
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2023-02-13 Move to MP Standby if discovery fails
    [LoRaSerial.ino, States.ino]
2023-02-13 Skip active discovery for low airspeeds
    [States.ino]
2023-02-14 Fix wrap-around on debugSerial prints
    [Serial.ino]
2023-02-15 Fix include path given directory change
    [settings.h]
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2023-02-16 Fix AT-AIRSPEED command
    convertAirSpeedToSettings was changing settings instead of tempSettings. This had two problems: 1) ATR was showing tempSettings so it looked like nothing changed, and 2) tempSettings would overwrite settings at ATO, causing the AIRSPEED change to be lost.
    [Commands.ino, Radio.ino]
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2023-02-17 Replace the mode specific defines with LED color defines
    [LoRaSerial.ino, System.ino]
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2023-02-18 Quick Start: Add references to command mode
    Mention that command mode can be used to change the network ID and
    encryption key.
    Add links to the other documentation.
    ------
    Note that the various web browsers behave differently. While Microsoft
    Edge might display the menu as a list of items on the left, Google
    Chrome only displays a menu icon and unless the user knows that there is
    a menu, the icon is easy to miss.
    As such, I recommend adding a short paragraphs describing the other
    sections of the documentation and include a link in the paragraph. This
    way if the user does not notice the menu button they still have access
    to the full documentation.
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2023-02-19 Fix the compile error caused by cfc11bf8.
    LED names did not changed in Begin.ino
    [Begin.ino]
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2023-02-24 Use a common reset function
    [Commands.ino, States.ino, Train.ino]
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2023-02-24 New training button behavior
    When the training button is pressed the green LEDs start counting
    seconds. When the 4 second boundary is crossed the yellow LED starts to
    blink. When the 8 second boundary is crossed the blue LED starts to
    blink. When the time reaches 15 seconds the radio clears NVM and
    resets. Upon boot the LoRaSerial radio starts with factory settings.
    [LoRaSerial.ino, States.ino, System.ino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]
2023-03-01 Reduce times for training and factory reset.
    [LoRaSerial.ino]
2023-03-01 Prevent updateLEDs() during training
    [System.ino]
2023-03-01 Immediately do system reset if train button triggers factory defaults
    [System.ino]
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2023-03-05 Fix the backspace in command mode
    [Serial.ino]
2023-03-06 Fix free space check for remote commands and HEARTBEAT frames
    [Radio.ino]
2023-03-06 Fix button press LEDs behavior
    [LoRaSerial.ino, System.ino]
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2023-03-06 Fix serialTransmitBuffer overrun - drain buffer when it gets full
    [Serial.ino]
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2023-03-07 Fix RTS and CTS to match the SAMD21 specification
    [Serial.ino]
2023-03-09 Update schematics with flow control notes
    [SparkFun LoRaSerial 433MHz - 1W.brd, SparkFun LoRaSerial 433MHz - 1W.sch, SparkFun LoRaSerial 868MHz - 1W.brd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]
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2023-03-13 Bug Fix: Receive remote command responses when in command mode
    [Radio.ino]
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2023-12-28 Pin mkdocs version to avoid error

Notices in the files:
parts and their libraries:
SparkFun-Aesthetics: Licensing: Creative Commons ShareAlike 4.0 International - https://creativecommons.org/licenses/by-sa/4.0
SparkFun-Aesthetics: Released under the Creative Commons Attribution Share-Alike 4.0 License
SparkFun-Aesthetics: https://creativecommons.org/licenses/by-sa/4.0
